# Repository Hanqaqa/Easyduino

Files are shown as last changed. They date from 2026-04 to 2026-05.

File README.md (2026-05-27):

# Easyduino: Repository of Open Source PCB Devboards for KiCad

The Easyduino project is an effort to easily dive into different PCB designs of the most popular microcontroller devboards like **Arduino, ESP32, Raspberry Pico and STM32 Bluepill** (more to come!). Using the free and Open Source Software [KiCad](https://www.kicad.org/) and adhering the best practices across the PCB and KiCad ecosystem. Also adding the much needed USB-C support!

<p align="center">
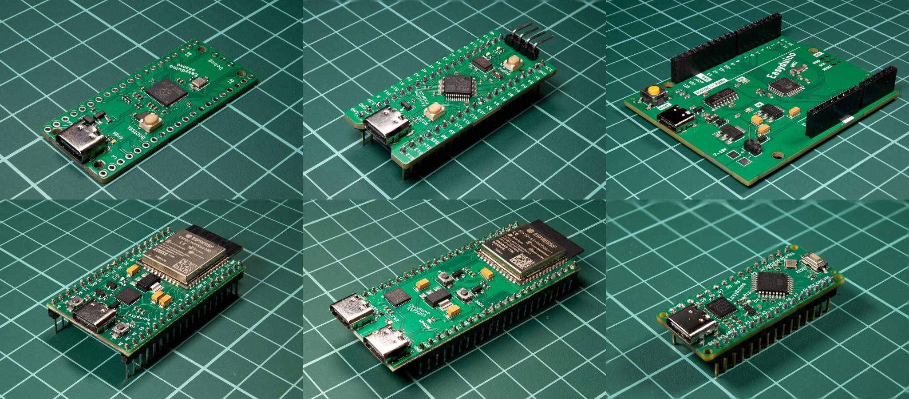
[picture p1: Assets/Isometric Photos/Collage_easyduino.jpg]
    
</p>

The project was born out of the necessity to unify the wide variety of software, languages and conventions used in the most popular devboards. For example Arduino Uno was developed in 2010, Italy, using Eagle. The ESP32 devboard was developed in 2016, China, using Altium. The Raspberry Pi Pico 2040 was developed around 2021 in the U.K. using KiCad and Altium...

## Available Development Boards 

[Easyduino UNO](https://github.com/Hanqaqa/Easyduino/tree/master/Atmega328p%20Arduino%20Uno) | [Easyduino Nano](https://github.com/Hanqaqa/Easyduino/tree/master/Atmega328p%20Arduino%20Nano) | [Easyduino ESP32](https://github.com/Hanqaqa/Easyduino/tree/master/ESP32) |
---|---|---|
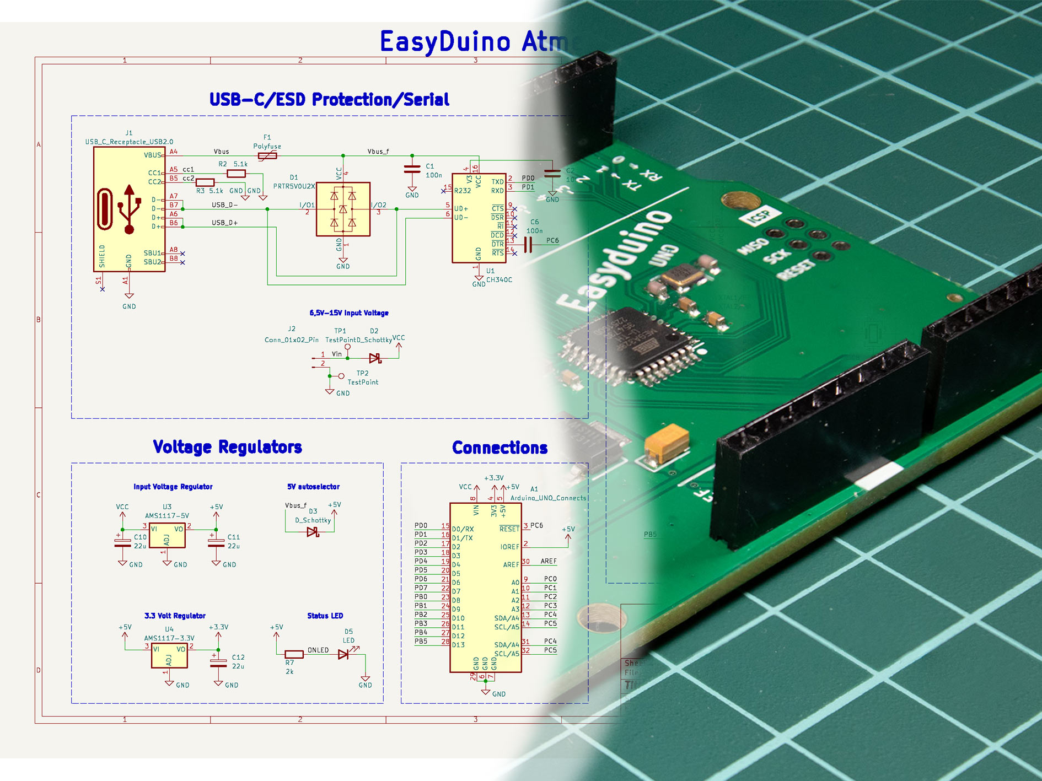
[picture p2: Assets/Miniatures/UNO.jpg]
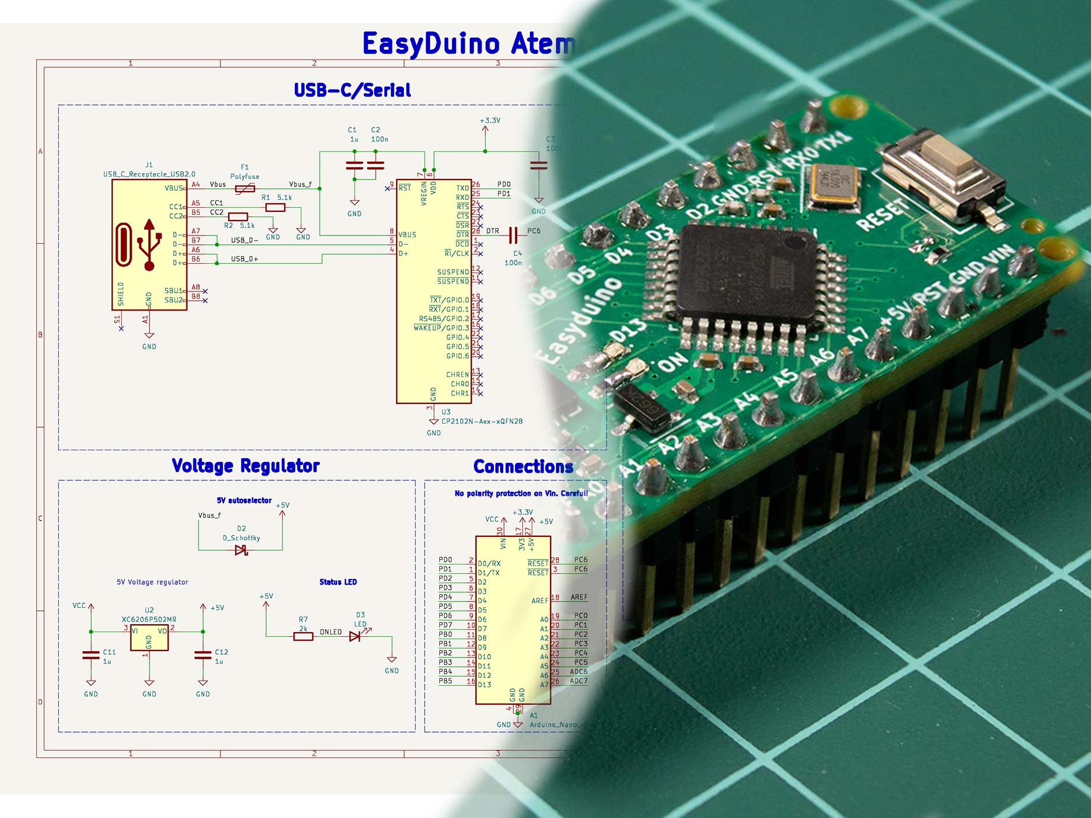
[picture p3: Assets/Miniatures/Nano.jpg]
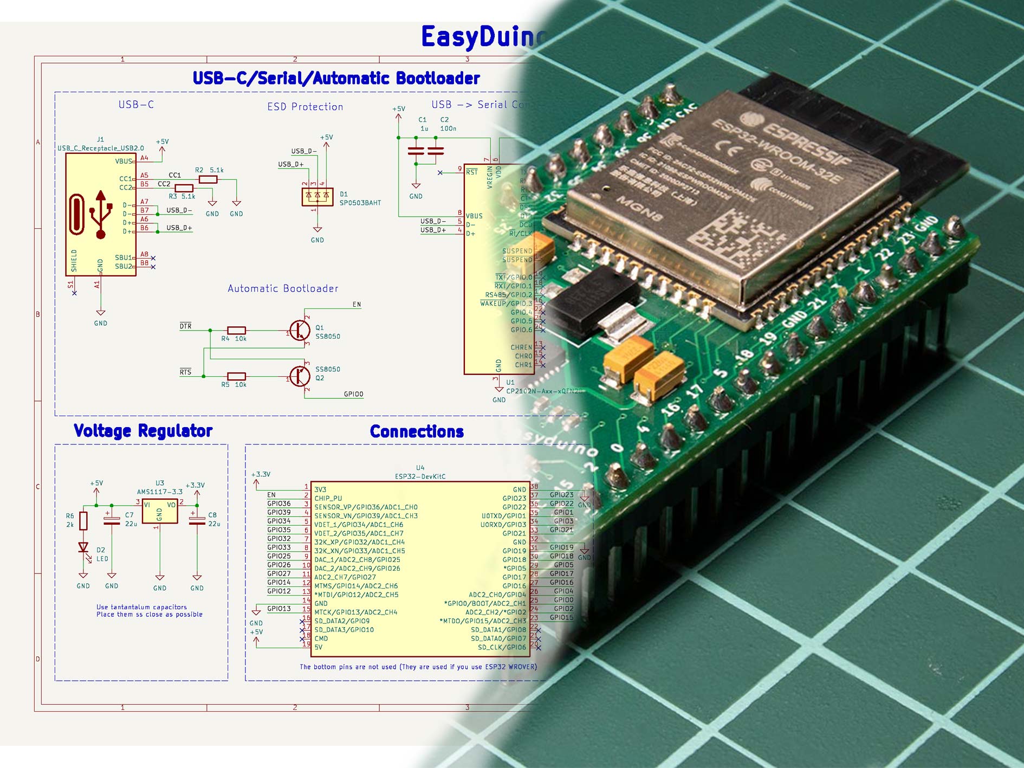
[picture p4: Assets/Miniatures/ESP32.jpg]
[](https://github.com/Hanqaqa/Easyduino/tree/master/Atmega328p%20Arduino%20Uno) | [](https://github.com/Hanqaqa/Easyduino/tree/master/Atmega328p%20Arduino%20Nano) | [](https://github.com/Hanqaqa/Easyduino/tree/master/ESP32) | 

[Easyduino ESP32 S3](https://github.com/Hanqaqa/Easyduino/tree/master/ESP32S3) | [Easyduino Pi Pico](https://github.com/Hanqaqa/Easyduino/tree/master/Raspberry%20Pi%20Pico%202040) | [Easyduino Bluepill STM32F103](https://github.com/Hanqaqa/Easyduino/tree/master/STM32F103%20Bluepill)
---|---|---|
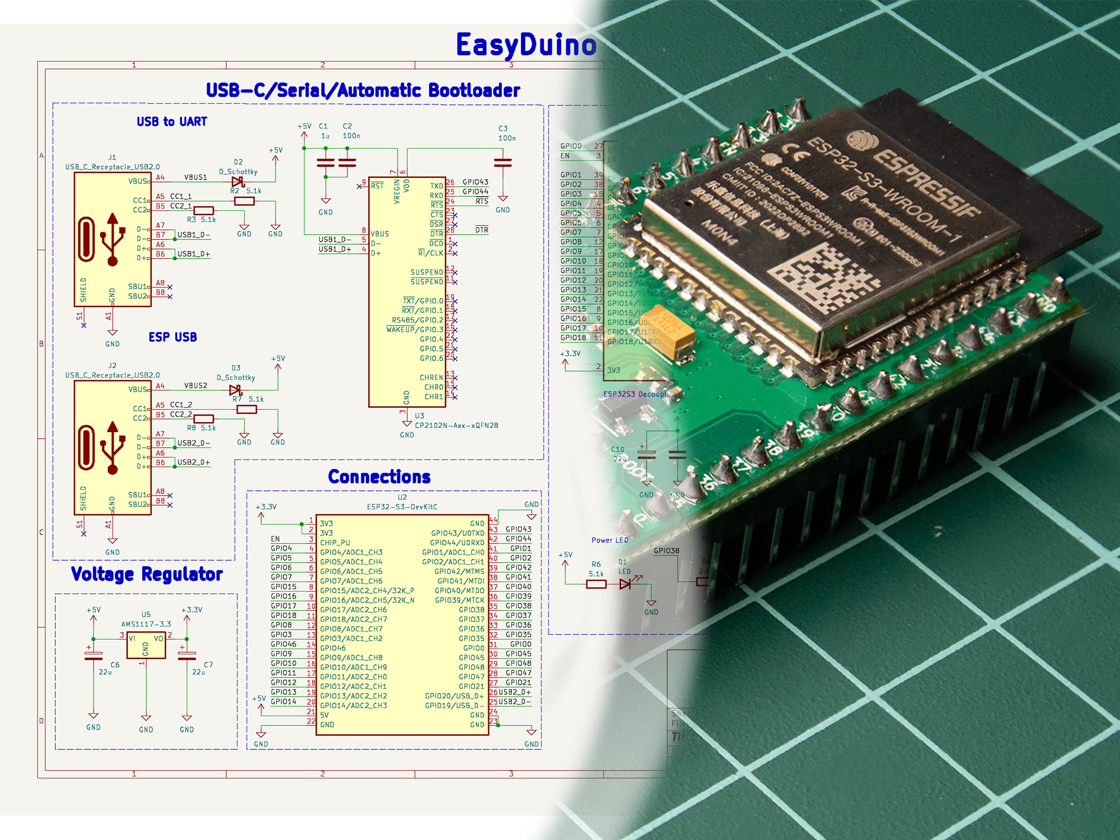
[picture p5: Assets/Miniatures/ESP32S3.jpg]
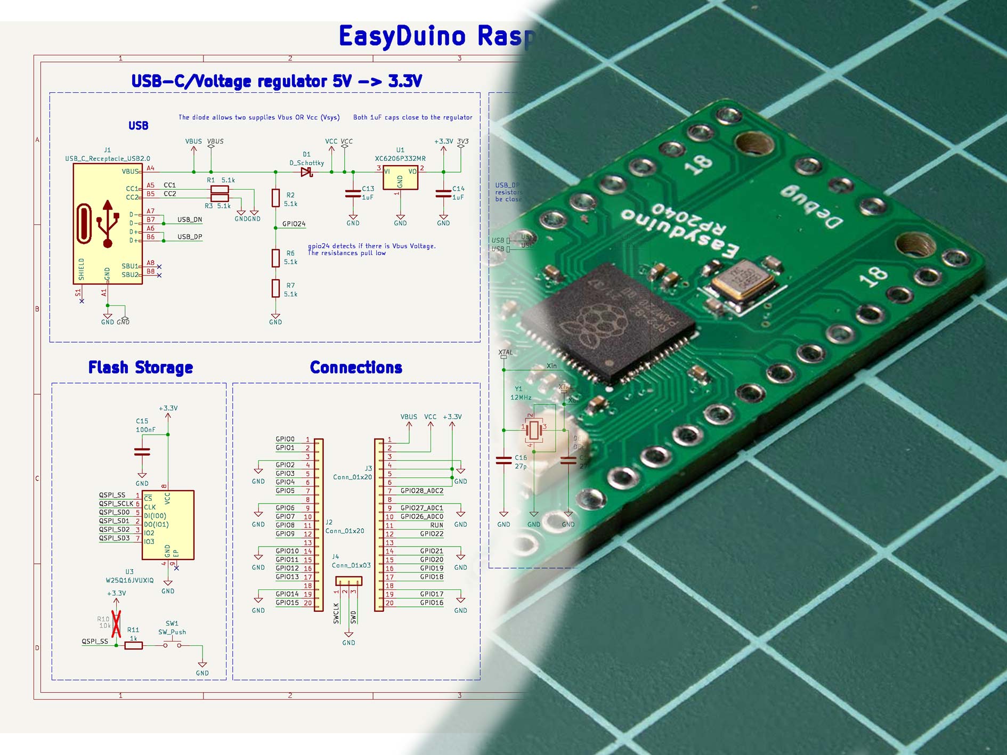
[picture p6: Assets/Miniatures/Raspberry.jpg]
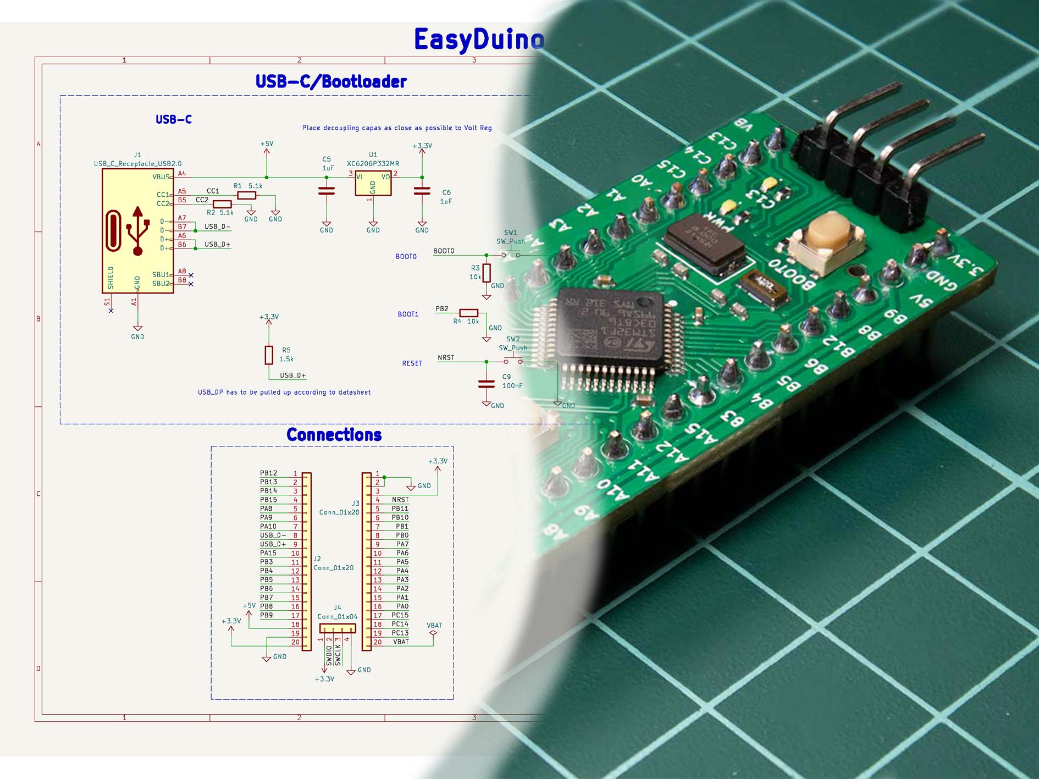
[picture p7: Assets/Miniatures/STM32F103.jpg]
[](https://github.com/Hanqaqa/Easyduino/tree/master/ESP32S3) | [](https://github.com/Hanqaqa/Easyduino/tree/master/Raspberry%20Pi%20Pico%202040) | [](https://github.com/Hanqaqa/Easyduino/tree/master/STM32F103%20Bluepill)

[Easyduino Pi Pico 2](https://github.com/Hanqaqa/Easyduino/tree/master/PiPico2) | [Easyduino Pi Pico 2 2354B](https://github.com/Hanqaqa/Easyduino/tree/master/PiPico22354B) | [Easyduino nrf52840 dongle](https://github.com/Hanqaqa/Easyduino/tree/master/nrf52840dongle)
---|---|---|
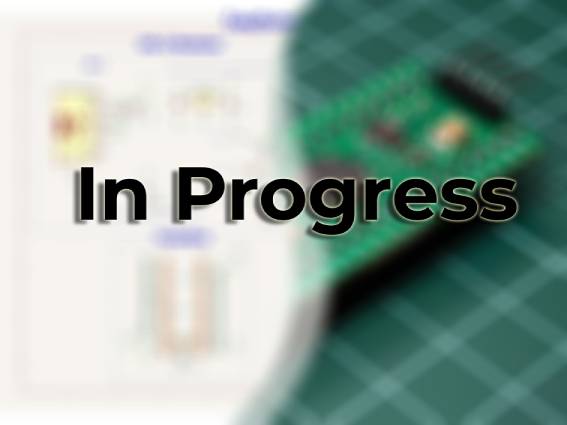
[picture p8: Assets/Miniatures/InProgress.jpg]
[](https://github.com/Hanqaqa/Easyduino/tree/master/PiPico2) | [](https://github.com/Hanqaqa/Easyduino/tree/master/PiPico22354B) | [](https://github.com/Hanqaqa/Easyduino/tree/master/nrf52840dongle)

The outline, pinout, layout and components have been tried to be replicated with respect to the originals, in all of the boards. With various levels of success. 

Some boards, like the Raspberry Pi Pico use 01005 components which are too expensive for the manufacturer to integrate in the PCB Aseembly line. Some other components like the original Arduino UNO USB to Serial converter, an Atmega16u2, were hard to come by during the development of this project ~January 2023, so more readily available options were chosen. All the differences with the original boards are explained inside the folder of each project in a readme file. 

4 layers of copper have been used in all projects to simplify the wiring. Specifically the [JLC04161H-7628](https://jlcpcb.com/impedance) stackup. 

The PCB constraints of the manufacturer JLCPCB are explained [here](https://github.com/Hanqaqa/Easyduino/tree/master/Assets/JLCPCB%20Constraints)

## Structure of each project

Each project consists of: 
- Main KiCad files (.kicad_pro, .kicad_sch...)
- A readme explaining the specifics of that project
- xxx.pretty or xxxlibraries folder which contains the non standard footprints or schematic parts used in the project (Some projects such as the Arduino UNO only use standard libraries, therefore these folders don't exist)
- The **Outputs** folder: Contains all the data produced by the KiCad Jobset like Gerbers, STEPs, PDFs, ERC, BOM, CPLs... Most of these are then copied, organized, and placed into their respective `ProductionFiles` folders.
- The ***ProductionFiles*** folder which includes files such as:
    - BOM: This folder contains both the list of components and the Centroid File in JLCPCB readable format. The CPL .csv file needs a small tweak at the beginning of the file in order to be readable. I mention it [here](https://github.com/Hanqaqa/Easyduino/tree/master/Assets/JLCPCB%20Constraints#cpl-component-placement-list).
    - ***Datasheets***: all the datasheets of the main components used in the project. Datasheets of easily replaceable components such as Resistors, Capacitors and LEDs are not given
    - Gerbers: A zip file with all of the manufacturing gerber files such as Copper/Mask/Silkscreen layers
    - PDFs: PDF and PNG files of the Schematic and PCB
    - Photos: Some photos of the manufactured PCB as well as some renders

## Using the project

1. Install the latest version of [KiCad](https://www.kicad.org/)
2. If you already have KiCad installed, click the upper right button in this github page `<>Code`, click `Download ZIP`, extract the files in your desired folder. If you know how to use git, clone the repository
3. Double click on the xxx.kicad_pro file inside any project and KiCad will start

This project was developed using KiCad v8.0.0, but has been updated and tested with KiCad v10. Including the creation of Jobsets which massively simplfies creating gerbers and BOMs. 

Since this is a collection of projects, the new KiCad v10 Git utilities don't work properly with each project, forcing you to git add the whole project if you want to make a change.

If you'd rather just consult the schematics or the gerbers. They are located inside the **ProductionFiles** folder of each project. Inside the **PDFs** and **Gerber** folders.

## Contributing

If you spot any mistakes inside any of the projects. Either open an issue and I will try to correct it or fork and merge the correction. 

If you plan on developing any other development boards and wish to merge into the project. Please try to use the same style and conventions as the original ones in the schematic. Positive voltages facing up, text being clearly readable, a references page, similar folder structure.

To do list:

- [ ] ~~Order and test the v1.1 RP2040 board. (In v1.0 I mixed some pins in the Flash and couldn't boot up). Ordered. Awaiting arrival. v1.1 is working correctly. Need to update photos and repo.~~ Order v1.2 with Silkscreen text for BOOTSEL and RESET. Once received test and make photos.
- [ ] ~~Order and test the v1.1 ESP32S3 board. (In v1.0 I forgot to add PullUp and PullDown in RST and SUSPEND CP2102). Ordered. Awaiting arrival.~~ TX and RX signals going into CP2102 were mixed. Fix it and order v1.2. Once received test and make photos.
- [ ] Developing: nRF52840 Dongle, RP2350A (Pi Pico 2), and Pi Pico 2 2354B with extra functionalities
- [ ] Investigate other possible microcontrollers/SOCs/FPGAs to implement.

## Acknowledgments

Thanks to [winsrrow](https://github.com/winsrrow) for providing lots of KiCad tips and designing from the ground up the v1.1 RP2040 board.

## Licensing

This project is distributed under the [**CERN Open Hardware Licence Version 2 - Permissive**](https://github.com/Hanqaqa/Easyduino/blob/master/License.txt) which means **you are free to use any or all parts of this project with or without disclosing the source**, even for comercial projects. As long as you include a copy of the CERN OHLv2 Permissive Licence.

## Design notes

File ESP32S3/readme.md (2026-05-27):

# ESP32S3 v1.2 IN PROGRESS

The new and powerful microcontroller from Espressif

<p align="center">
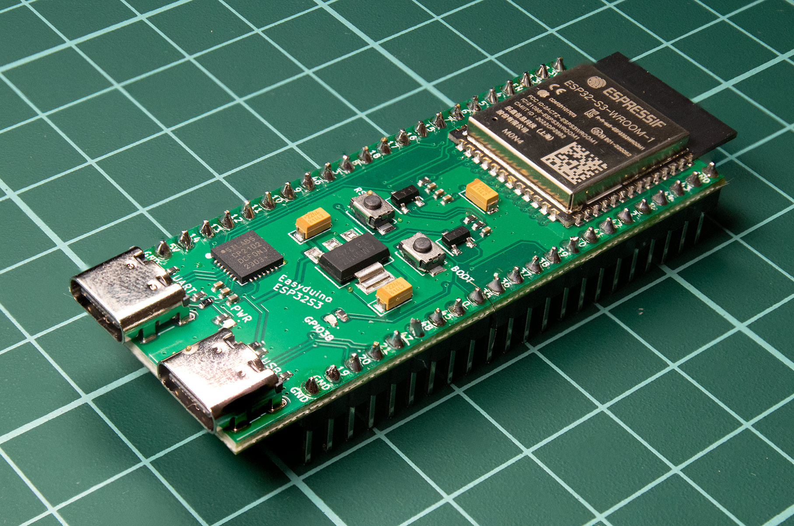
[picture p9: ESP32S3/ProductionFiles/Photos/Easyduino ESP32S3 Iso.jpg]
    
</p>

**The pictured version is v1.0 which had TX/RX from the CP2102 going into the ESP32S3 module mixed up. The project contains the v1.2 which corrects that mistake. Will update the pictures once I order antoher batch and test everything works correctly.**

## Schematic

<p align="center">
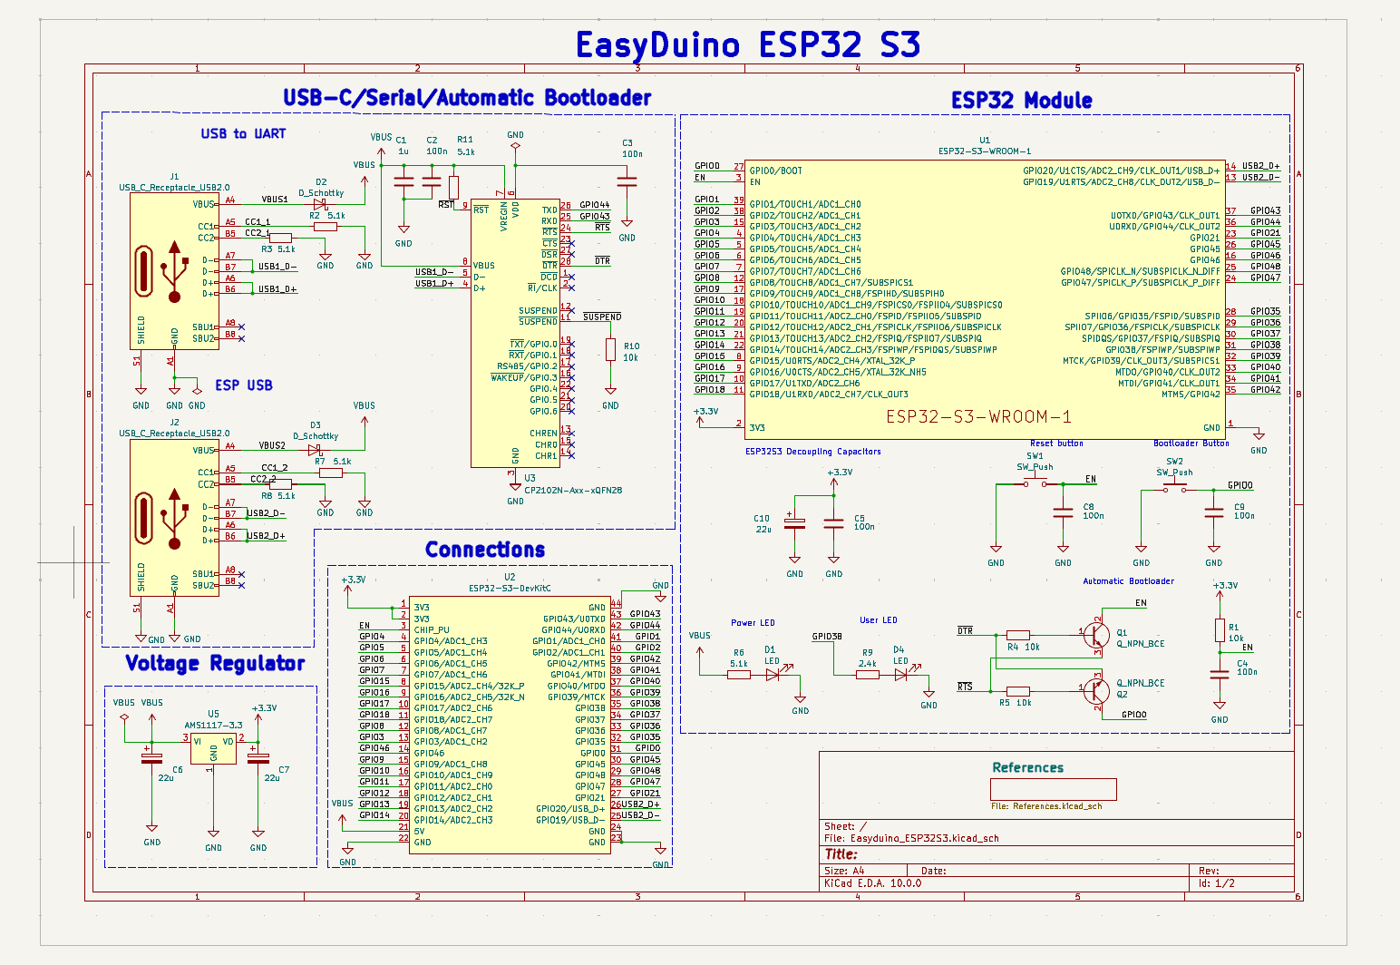
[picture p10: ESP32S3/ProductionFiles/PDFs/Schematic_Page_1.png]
    
</p>

KiCad Schematic symbols, footprints and 3D Models were obtained from their [KiCad Github repository](https://github.com/espressif/kicad-libraries)

## Gerbers

<p align="center">
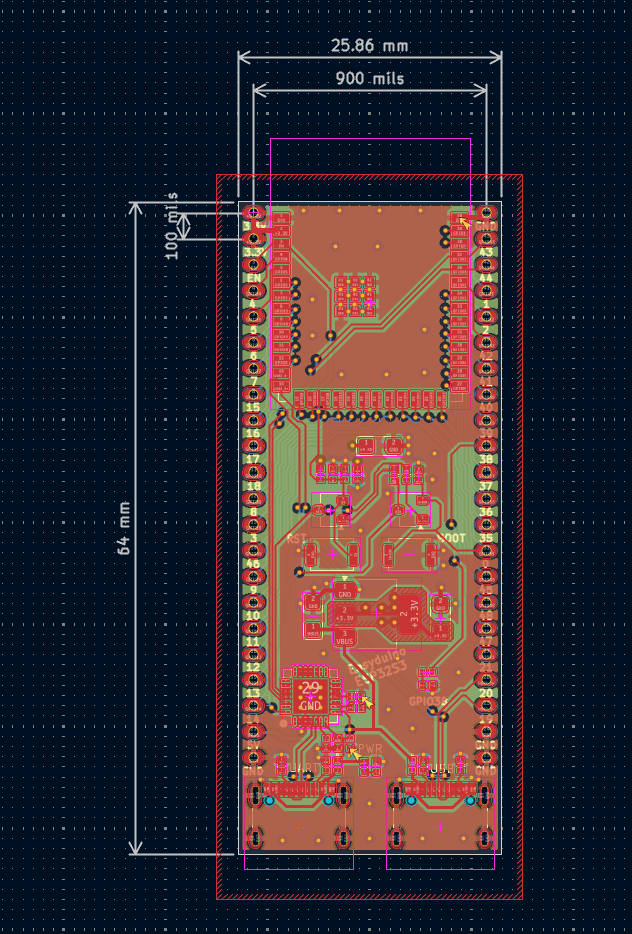
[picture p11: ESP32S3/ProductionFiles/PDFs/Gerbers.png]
    
</p>

## Specs

- Input Voltage: 5V-15V(External Source 5V) 5V (USB UART OR USB ESP32) or 3.3V. ONLY USE ONE VOLTAGE INPUT AT A TIME
- Output Current at 3.3V : 1 A (External Source) 500mA (USB)
- No Polarity Protection (External Source)
- Overcurrent Protection: None 

## References 

### ESP32 S3 WROOM 1

#### Decoupling Capacitors:

- ESP32 S3 WROOM 1 datasheet p25 -> 3.3V pin needs a 22uF and a 100nF capacitors. The 22uF doesn't have to be a tantalum capacitor. But I will use a tantalum to reuse components

#### Automatic Bootloader

- ESPS3 Sch -> Automatic Bootloader.
- ESPS3 Sch / ESP32 S3 WROOM 1 datasheet p25 -> EN pin 10k resistor and 100nF capacitor

#### Thermal vias

- ESP32 S3 WROOM 1 datasheet p27 -> GND Thermal needs vias between pads

### USB-C

#### Filtering 

- USB Hardware Design Guidelines for FTDI ICs p8 -> 10nF Cap + Ferrite Bead + 100nF Cap + 4.7uF Cap
- I disregarded such heavy filtering for the easier to implement 1uF and 100nF cap given in the CP2102 datasheet
- I added a polyfuse with Ihold=500mA and Itrip=1A.

#### Differential Pair

- USB needs 90 Ohm differential traces. 
- Using JLCPCB's JLC04161H-7628 stackup.
- Which with Signal Layer (Layer 1) and a GND layer (L2) below. And with 0.2mm tracks and separated 0.15mm gives a differential pair impedance of approximately 90 Ohms.
- For USB1 will use a very short trace for D+ D- (around 2mm)
- For USB2 (tracks that go to the internal ESP32 S3 pins and the pinout) the traces are long ~60mm for D+ D-, and have vias
- The Development board from ESP32S3 has no problem with these differential pairs with vias and is a 2 board layer
- I also have to place vias because of the pinout of USB C and CP2102. Some other people have placed vias without problems for signal integrity

#### CP2102

- CP2102 datasheet p15 -> VBUS will be tied to REGIN. 1uF and 100 nF will be added.
- CP2102 datasheet p15 -> ESD Supression Diode for all three inputs of USB  
- CP2102 datasheet p15 and p19 -> 100nF for VDD output, 4.7 uF is optional for higher current circuits.
- CP2102 datasheet p23 -> The VDD or 3.3 output can only provide 100mA. I will not use this as a voltage provider for the ciruit. I will use the AMS1117-3.3 
- CP2102 datasheet p15 -> RST pulled up via 4.7k and SUSPEND~ pulled down via 10k.

#### AMS1117-3.3V

- AMS1117 Datasheet p1 -> 3.3V/1A Output with 5-15V Input
- AMS1117 Datasheet p4 -> 22uF tantalum capacitor on input and output.

## KiCad Render

<p align="center">
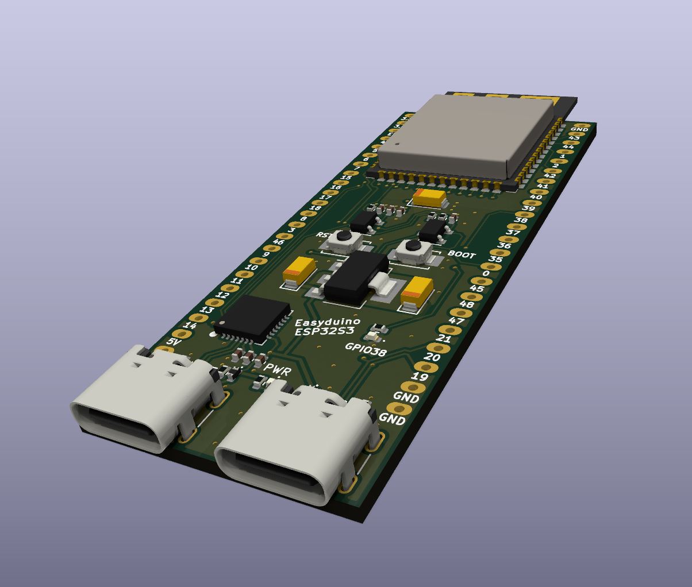
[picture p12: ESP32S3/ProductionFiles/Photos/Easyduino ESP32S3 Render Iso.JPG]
    
</p>

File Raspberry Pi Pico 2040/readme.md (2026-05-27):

# Raspberry Pi Pico RP2040 v1.2 IN PROGRESS.

The new and easy to use Microcontroller from the Raspberry Pi Foundation. Now with a Reset button. Connect via USB, hold BOOTSEL (BT), press and release RESET(RST), then release BOOTSEL. You are now in Bootloader mode.

<p align="center">
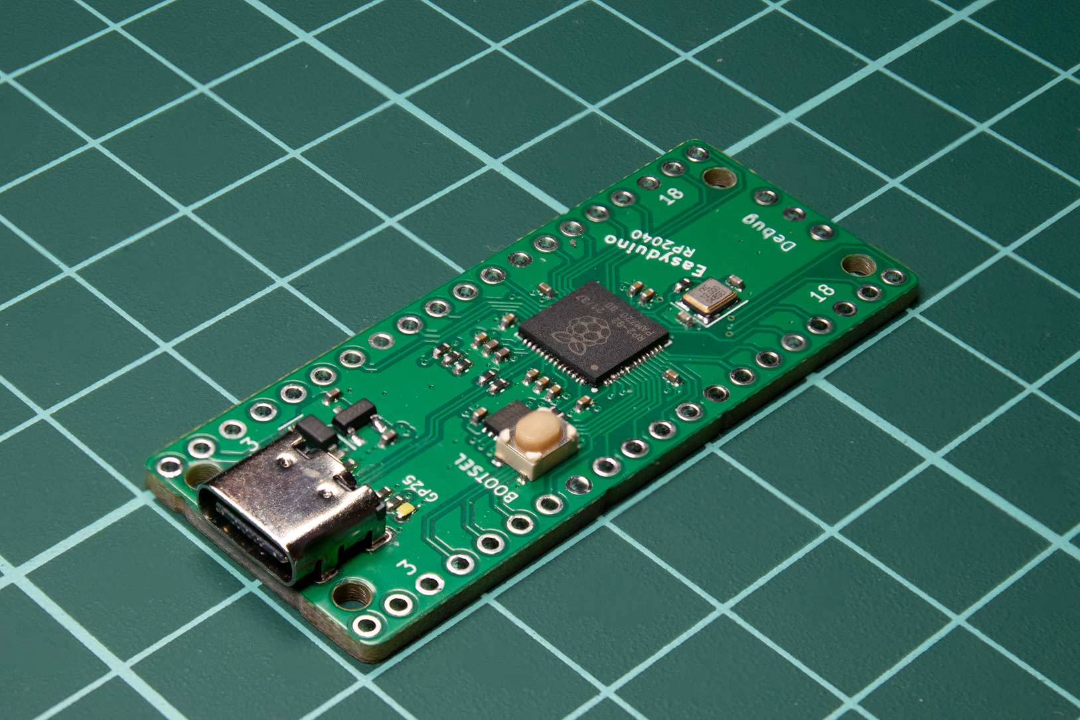
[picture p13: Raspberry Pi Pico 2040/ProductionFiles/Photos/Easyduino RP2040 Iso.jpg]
    
</p>

**The pictured version is v1.0 which had some pins mixed up in the flash memory and couldn't boot up. The project contains the v1.2 which corrects that mistake, adds a debug port and some test points. The photo will be updated when I receive and test the new board.**
**The mounting holes are not exactly in the same position as the original Pi Pico due to the size of USBC**

## Schematic

<p align="center">
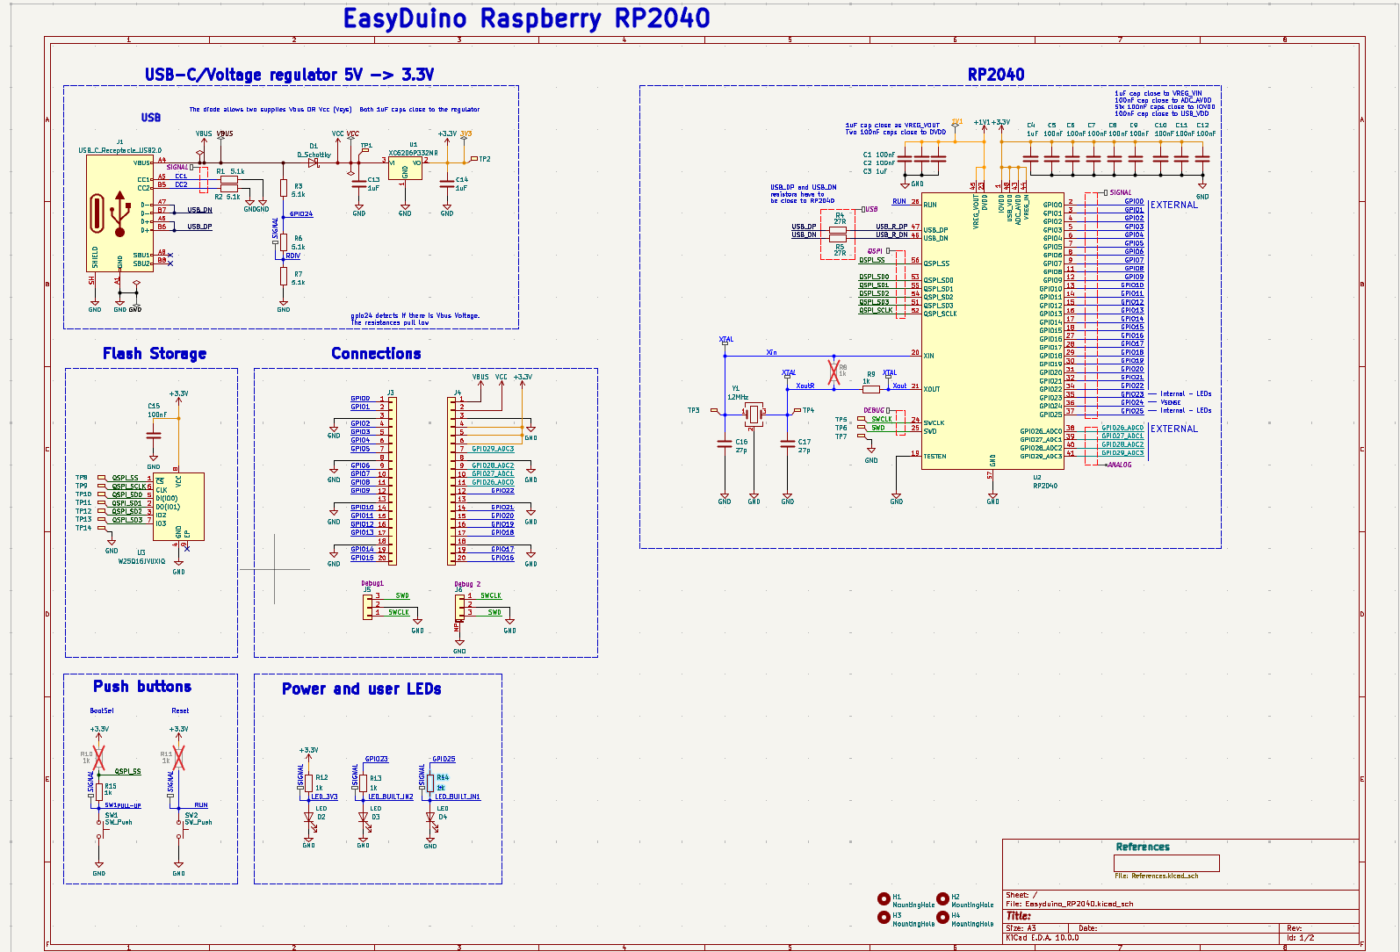
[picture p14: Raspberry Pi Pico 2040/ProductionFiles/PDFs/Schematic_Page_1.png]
    
</p>

KiCad's "Net classes" have been used in this schematic (The squares and romboids in the schematic). Net classes are useful for organising different nets on the circuit. For example, you can change all tracks widths for that net in just one menu.

## Gerbers

<p align="center">
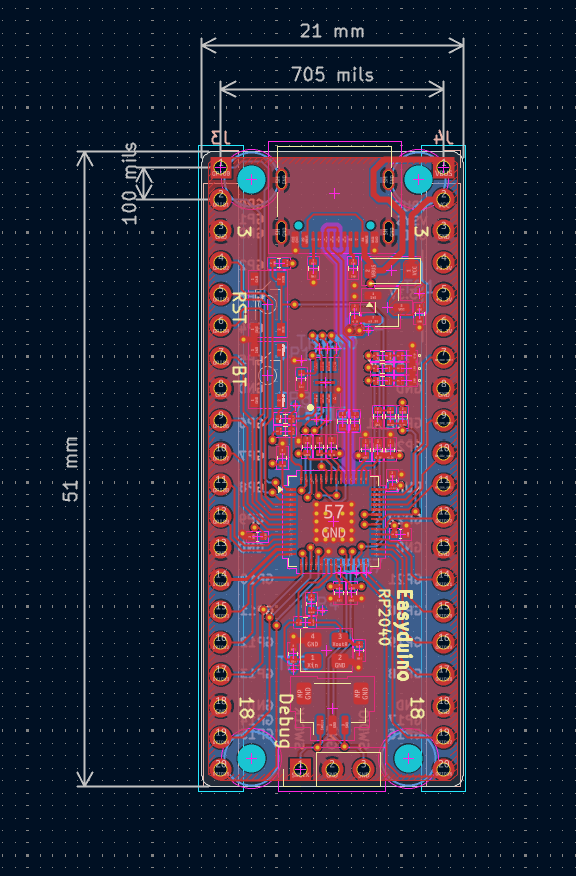
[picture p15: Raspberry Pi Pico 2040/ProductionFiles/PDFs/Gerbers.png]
    
</p>

## Specs

- Input Voltage: 5.5V-9V(External Source 5V) or 5V (USB). ONLY USE ONE VOLTAGE INPUT AT A TIME
- Maximum Output Current at 5V input : 200 mA at 3.3V output
- No Polarity Protection (External Source)
- Overcurrent Protection: None! 

## References 

### RP2040

- RPI Pico Schematic
- Hardware design with rp2040 p10 -> 12MHz crystal with 27 pF Capacitors 
- rp2040 datasheet p13 -> USB_DP and USB_DM need 27 Ohm Resistors
- rp2040 datasheet p13 -> Use a 12MHz Crystal
- rp2040 datasheet p13 -> TESTEN to GND
- rp2040 datasheet p155 -> USB_VDD connected to 3.3V and decoupled with a 100 nF capacitor
- rp2040 datasheet p155 -> IOVDD connected to 3.3V and decoupled with a 100 nF capacitor per pin (6pins)
- rp2040 datasheet p155 -> DVDD connected to VREG_VOUT = 1.1V and decoupled with a 100 nF capacitor per pin (2pins)
- rp2040 datasheet p156 -> ADC_AVDD connected to 3.3V and decoupled with a 100 nF capacitor. A better circuit (Pico Schematic) can be made when ADC is crucial
- rp2040 datasheet p160 -> VREG_VIN Internal 1.1V Voltage regulator Input. Connect to external 3.3V and decouple with 1uF
- rp2040 datasheet p160 -> VREG_VOUT Internal 1.1V Voltage regulator Output. Connect to 1.1V and decouple with 1uF

### USB-C

#### Differential Pair

- USB needs 90 Ohm differential traces. 
- According to JLCPCB impedance calculator, with a JLC7628 prepreg and 6mil (0.15mm) space between lines
- I have to use 9 mil tracks -> 0.2 mm
- I have to place vias because of the pinout of USB C and CP2102. Some other people have done it with no problems

### W25Q16JVUXIQ

- W25Q16JVUXIQ Datasheet p6 -> Use a 100nF and 1uF capacitor
- RPI Pico Schematic -> Use a 100nF and 2uF decoupling capacitors. A pull up resistor is not fitted
- Hardware design with rp2040 p9 -> Use a 100nF decoupling capacitor. Pull up resistor is not fitted, the flash can work without it. 
- I will only place the 100nF capacitor, since the devboard can work according to Hardware design guide. I will not place a pull up resitor

### XC6206P332MR-3.3V

- XC6206_Torex Datasheet p6 -> Two 1 uF ceramic capacitors on Vin and Vout

### Differences with Original Raspberry Pi Pico

- GPIO23 is not exposed or used. Since the voltage regulator used (XC6206...) doesn't have a Power Select mode
- GPIO29_ADC which is used for monitoring VSys (external battery) is not exposed or used in order to save costs
- In the Raspberry Pi Pico Schematic, 2uF capacitors are used for decoupling. I use 1uF decoupling capacitors as indicated in the rp2040 datasheet
- ADC_AVDD is powered only by 3.3V, no option for external Analog powering. This will be more noisy for projects where ADC is used. But in order to save space and cost. I will skip the option to power ADC_AVDD externally

## KiCad Render

<p align="center">
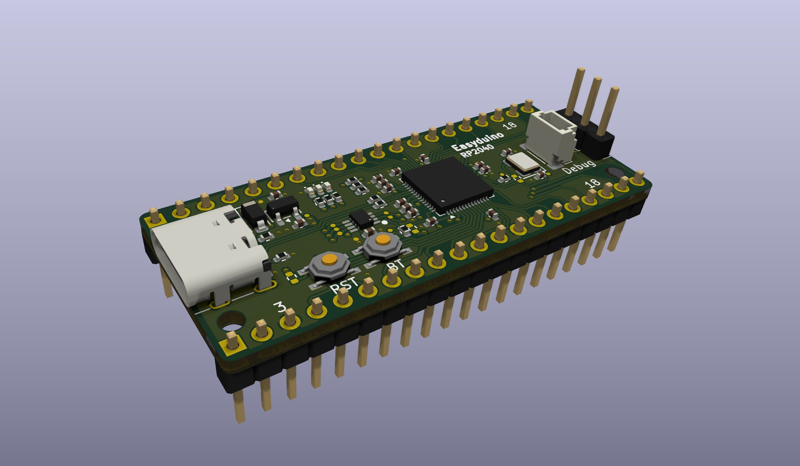
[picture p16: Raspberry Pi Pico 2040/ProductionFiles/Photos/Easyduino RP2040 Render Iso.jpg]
    
</p>

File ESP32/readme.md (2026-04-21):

# ESP32

The most popular WiFi Microcontroller

<p align="center">
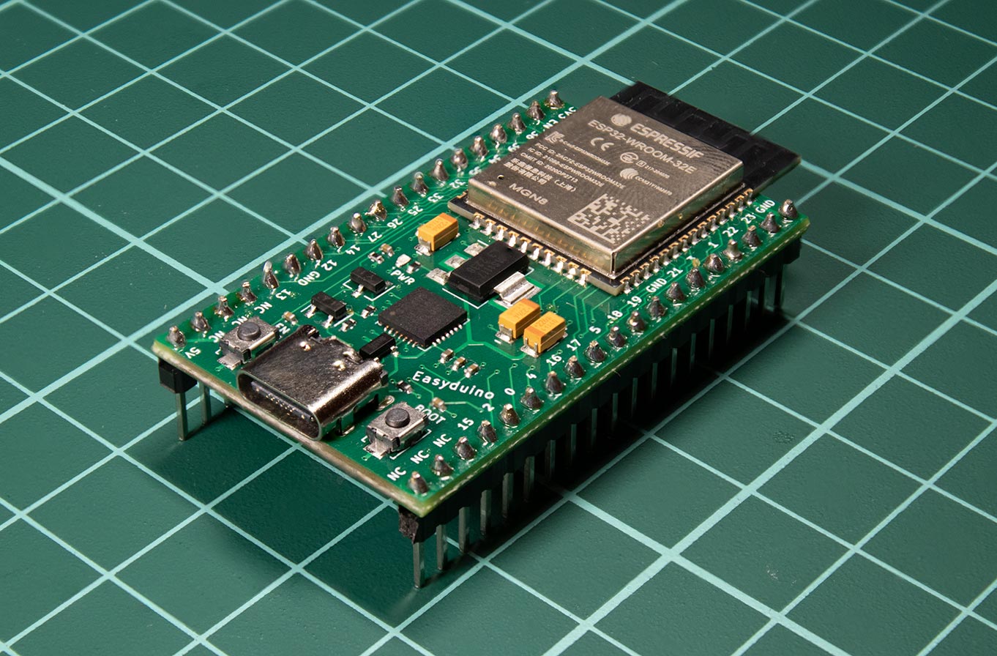
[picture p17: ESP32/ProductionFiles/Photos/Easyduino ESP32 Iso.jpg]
    
</p>

## Schematic

<p align="center">
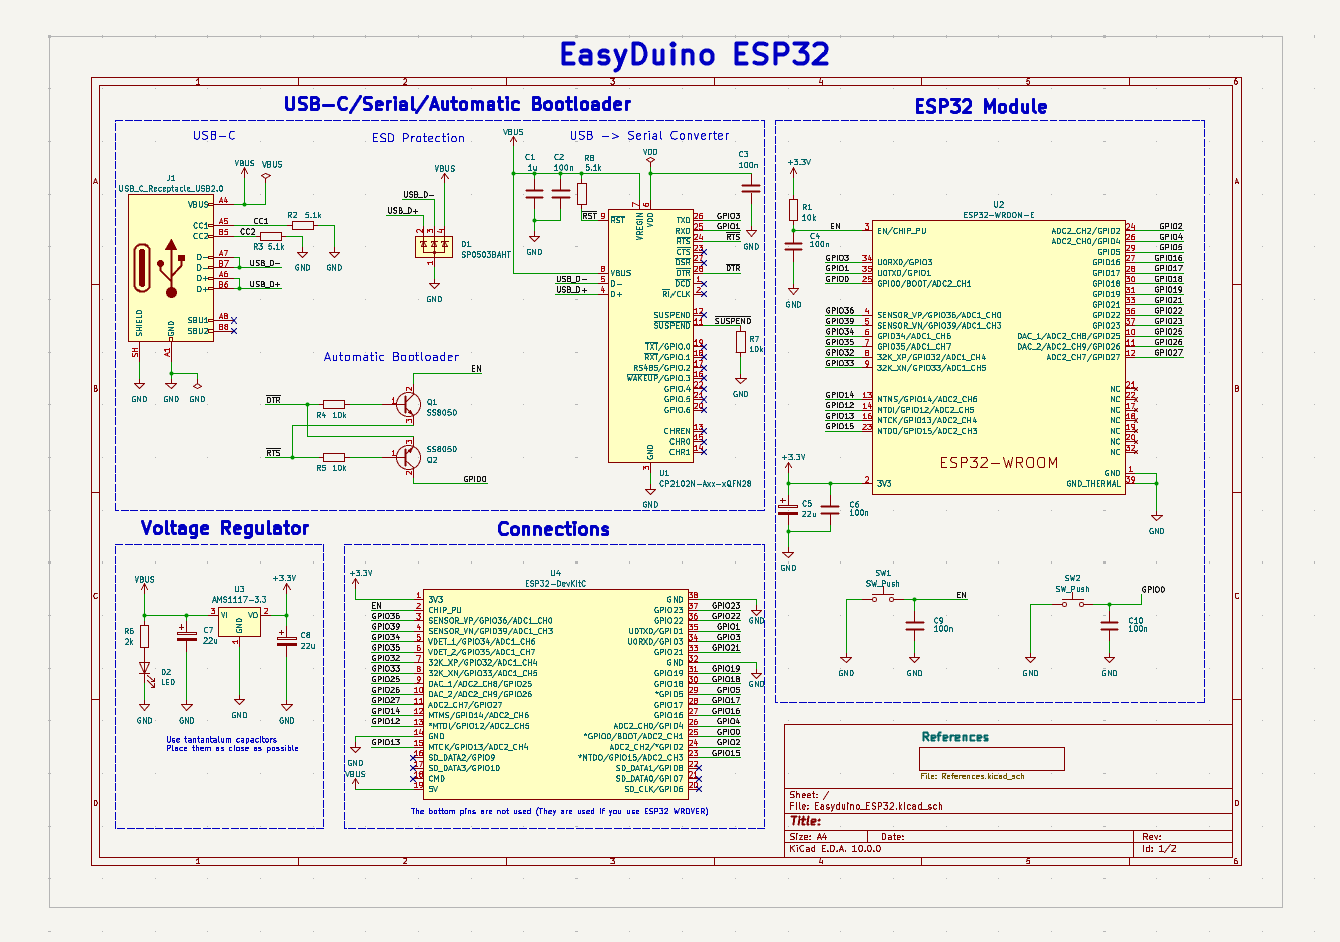
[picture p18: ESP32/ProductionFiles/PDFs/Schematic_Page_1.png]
    
</p>

KiCad Schematic symbols, footprints and 3D Models were obtained from their [KiCad Github repository](https://github.com/espressif/kicad-libraries)

## Gerbers

<p align="center">
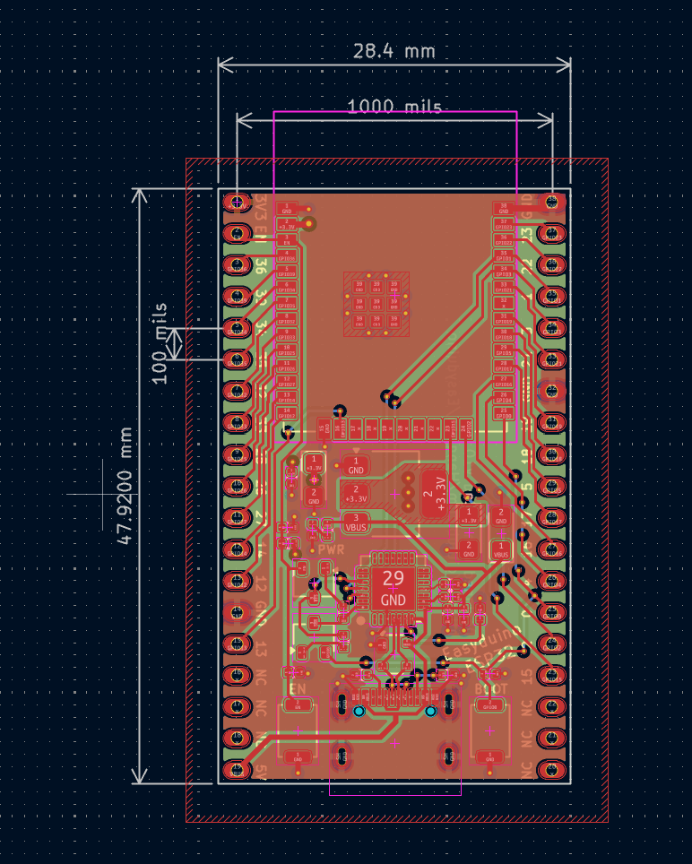
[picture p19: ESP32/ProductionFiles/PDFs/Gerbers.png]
    
</p>

## Specs

- Input Voltage: 5V-15V(External Source 5V Pin) 5V (USB) or 3.3V (3.3V Pin). ONLY USE ONE VOLTAGE INPUT AT A TIME
- Output Current at 3.3V : 1 A (External Source) 500mA (USB)
- No Polarity Protection (External Source)
- Overcurrent Protection: None 

## References 

### ESP32 WROOM 32E

#### Decoupling capacitors 

- ESP32 Wroom 32 E datasheet p24 -> 3.3V pin needs one 22uF and one 100nF capacitors

#### Enable pin (EN)

- ESP32 Devkit sch -> EN pin 10k resistor and 100nF capacitor

#### Thermal Pad

- ESP32 Wroom 32 E datasheet p26 -> GND Thermal needs vias between pads. Needed vias are too small for my manufacturer. I will use bigger vias

#### Automatic Bootloader

- ESP32 Devkit sch -> Automatic Bootloader.

### USB-C

#### Filtering 

- USB Hardware Design Guidelines for FTDI ICs p8 -> 10nF Cap + Ferrite Bead + 100nF Cap + 4.7uF Cap
- I disregarded such heavy filtering for the easier to implement 1uF and 100nF cap given in the CP2102 datasheet
- I added a polyfuse with Ihold=500mA and Itrip=1A.

#### Differential Pair

- USB needs 90 Ohm differential traces. 
- According to JLCPCB impedance calculator, with a JLC7628 prepreg and 6mil (0.15mm) space between lines
- I have to use 9 mil tracks -> 0.2 mm
- I will use a very short trace for D+ D- (around 2mm)
- I have to place vias because of the pinout of USB C and CP2102. Some other people have done it with no problems

#### CP2102

- CP2102 datasheet p15 -> VBUS will be tied to REGIN. 1uF and 100 nF will be added.
- CP2102 datasheet p15 -> ESD Supression Diode for all three inputs of USB  
- CP2102 datasheet p15 and p19 -> 100nF for VDD output, 4.7 uF is optional for higher current circuits.
- CP2102 datasheet p23 -> The VDD or 3.3 output can only provide 100mA. I will not use this as a voltage provider for the ciruit. I will use the AMS1117-3.3 
- CP2102 datasheet p15 -> RST pulled up via 4.7k and SUSPEND~ pulled down via 10k.

#### AMS1117-3.3V

- AMS1117 Datasheet p1 -> 3.3V/1A Output with 5-15V Input
- AMS1117 Datasheet p4 -> 22uF tantalum capacitor on input and output.

## KiCad Render

<p align="center">
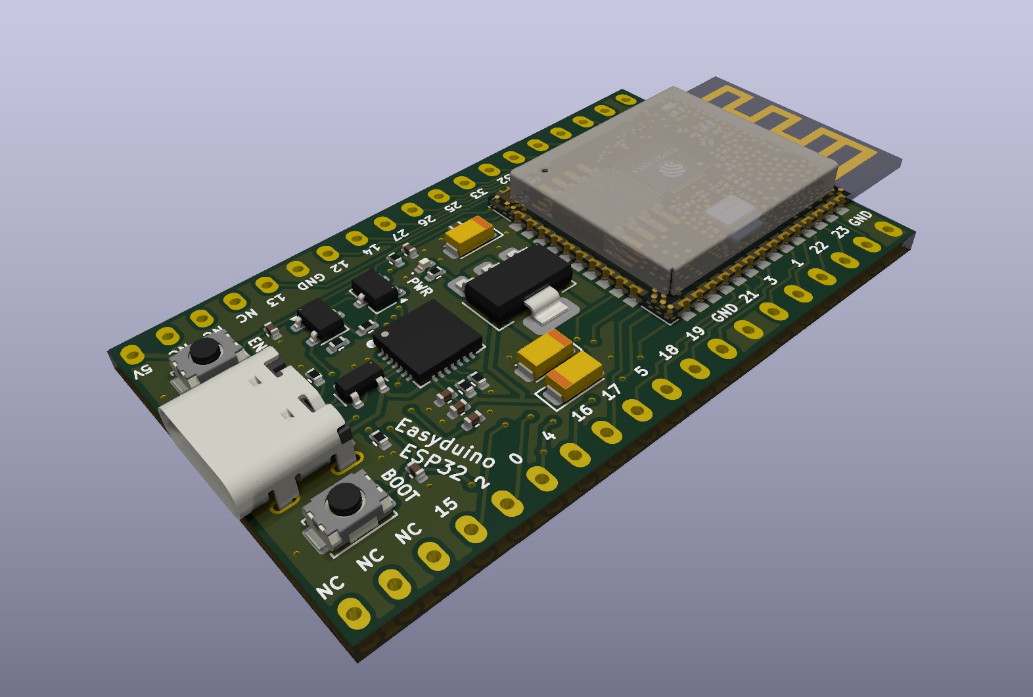
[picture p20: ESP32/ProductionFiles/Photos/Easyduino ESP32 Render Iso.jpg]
    
</p>

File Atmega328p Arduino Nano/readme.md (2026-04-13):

# Easyduino Arduino Nano

The popular Nano version of the Arduino

<p align="center">
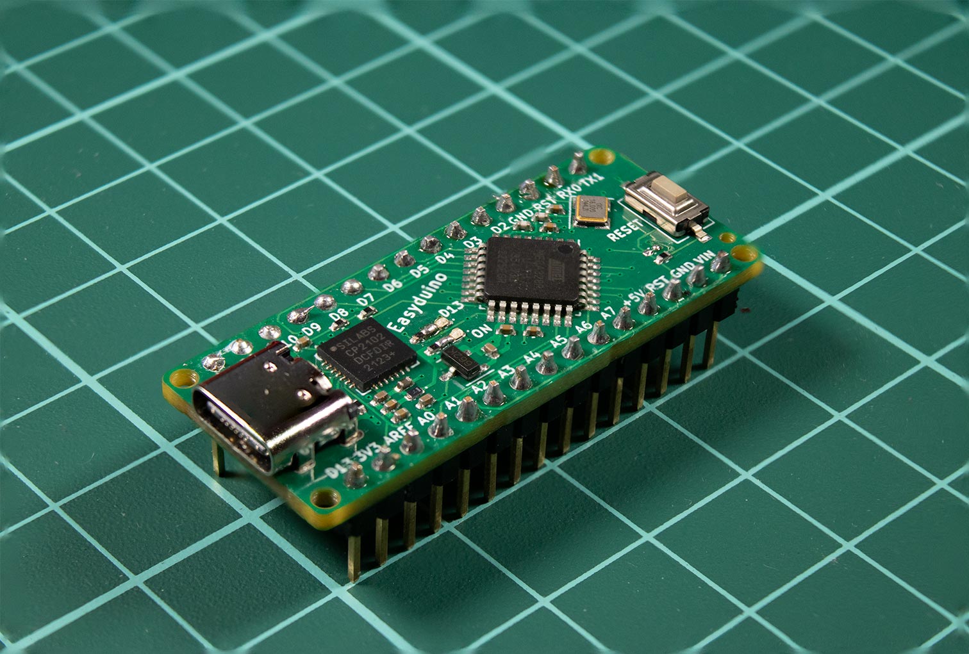
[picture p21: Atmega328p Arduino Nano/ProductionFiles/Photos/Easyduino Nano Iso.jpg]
    
</p>

## Schematic

<p align="center">
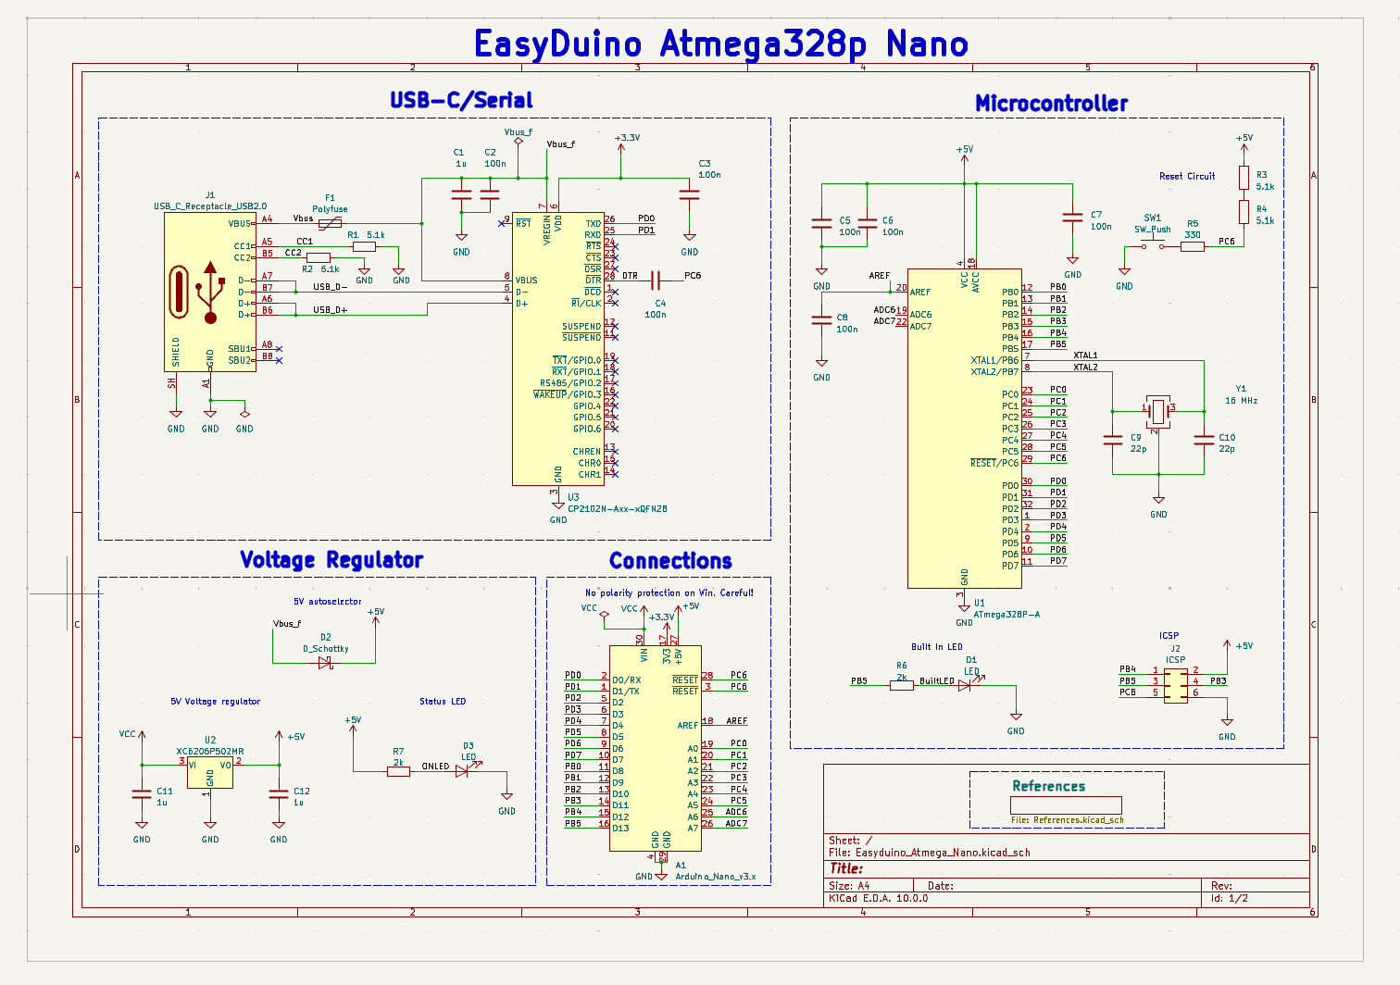
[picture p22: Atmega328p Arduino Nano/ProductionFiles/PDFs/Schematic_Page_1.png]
    
</p>

## Gerbers

<p align="center">
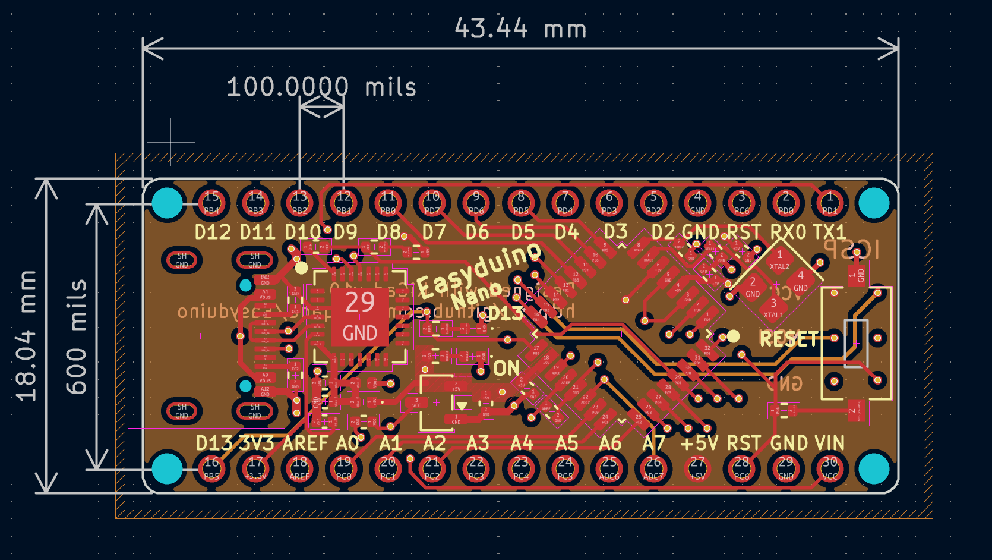
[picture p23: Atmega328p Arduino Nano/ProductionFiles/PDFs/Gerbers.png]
    
</p>

## Specs

- Input Voltage: 5.5V-9V(External Source Vin) 5V (USB). Both can be used at the same time. Preferable to only power from one source
- Output Current: 250 mA (External Source) 500mA (USB)
- 3.3V Output Current: None (External Source) 100 mA (USB)
- No Polarity Protection (External Source)
- Overcurrent Protection: None (External Source) 1A (USB)
- 5V Autoselector: can take both USB and external source. A diode will avoid short circuit. 
- External input Polarity Protection: None!! 

## References 

### Atmega 328p

#### Reset 

- Atmega Hardware Design Considerations p7,p8 -> 10kR and 330R for switch. The 100nF capacitor is not used for Arduino (Produces errors with DTR)
- The 100nF capacitor on DTR (CP2102) is used for tricking the Atmega into Bootloader mode

#### Crystal

- Atmega Hardware Design Considerations p16 -> 22pf

#### AVCC

- Atmega328 Reference Manual p213 -> 10uH ferrite bead and 100nF. 
- The Analog tracks aren't critical. I won't create an analog ground for these tracks.
- I also won't add the 10 uH ferrite

#### AREF

- Atmega Hardware Design Considerations p6 -> 100nF

### USB-C

#### Filtering 

- USB Hardware Design Guidelines for FTDI ICs p8 -> 10nF Cap + Ferrite Bead + 100nF Cap + 4.7uF Cap
- I disregarded such heavy filtering for the easier to implement 1uF and 100nF cap given in the CP2102 datasheet
- I added a polyfuse with Ihold=500mA and Itrip=1A.

#### Differential Pair

- USB needs 90 Ohm differential traces. 
- According to JLCPCB impedance calculator, with a JLC7628 prepreg and 6mil (0.15mm) space between lines

- I have to use 9 mil tracks -> 0.2 mm
- I will use a very short trace for D+ D- (around 2mm)
- I have to place vias because of the pinout of USB C and CP2102. Some other people have done it with no problems

#### CP2102

- CP2102 datasheet p15 -> 1uF and 100nF for REGIN and VBUS
- CP2102 datasheet p15 -> 100nF for VDD output, 4.7 uF is optional for higher current circuits.
- CP2102 datasheet p23 -> The VDD or 3.3 output can only provide 100mA 
- CP2102 datasheet p23 -> Logic levels go up to 3.3 V, but Atmega328p is able to understand them. Despite being 5V
- CP2102 datasheet p15 -> RST and SUSPEND resistors have not been placed. Might produce bad results due to noise

#### XC6206P

- XC6206 Torex Datasheet p1 -> 1uF ceramic capacitor on input and output. 7V Maximum operating Voltage
- XC6206 UWM Datasheet p2 -> 1uF ceramic capacitor on the input and output. 9V Maximum operating Voltage

#### 5V autoselector

- If USB is present and no external input voltage. The USB will power the ATMEGA
- If USB is present and there is external input voltage. The external voltage will power the ATMEGA
- If USB is not present and there is external input voltage. The external voltage will power the ATMEGA. The 3.3V output won't work

## KiCad Render

<p align="center">
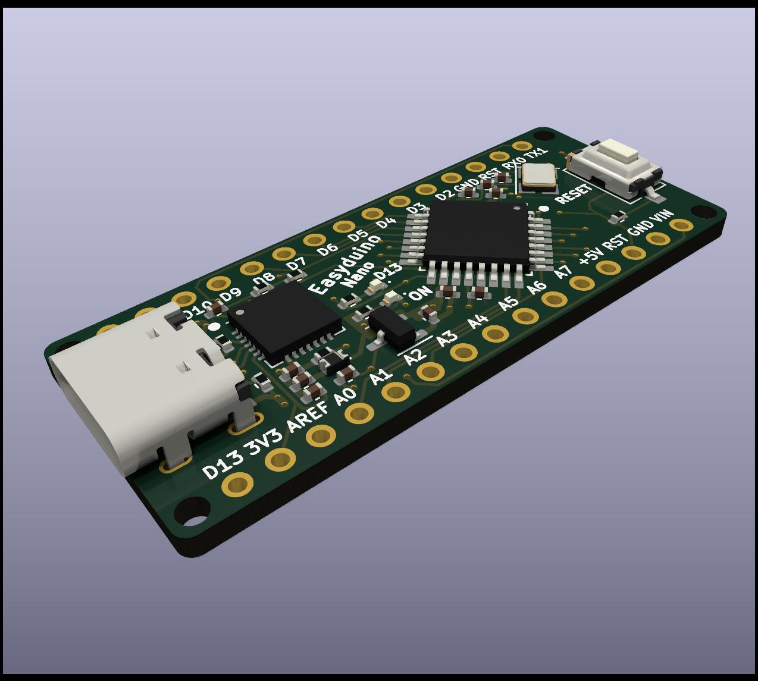
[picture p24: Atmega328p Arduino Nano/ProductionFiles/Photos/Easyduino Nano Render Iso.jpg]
    
</p>

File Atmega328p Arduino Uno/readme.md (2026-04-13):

# Easyduino Arduino

The Microcontroller that propelled the Maker and Hobbyst movements

<p align="center">
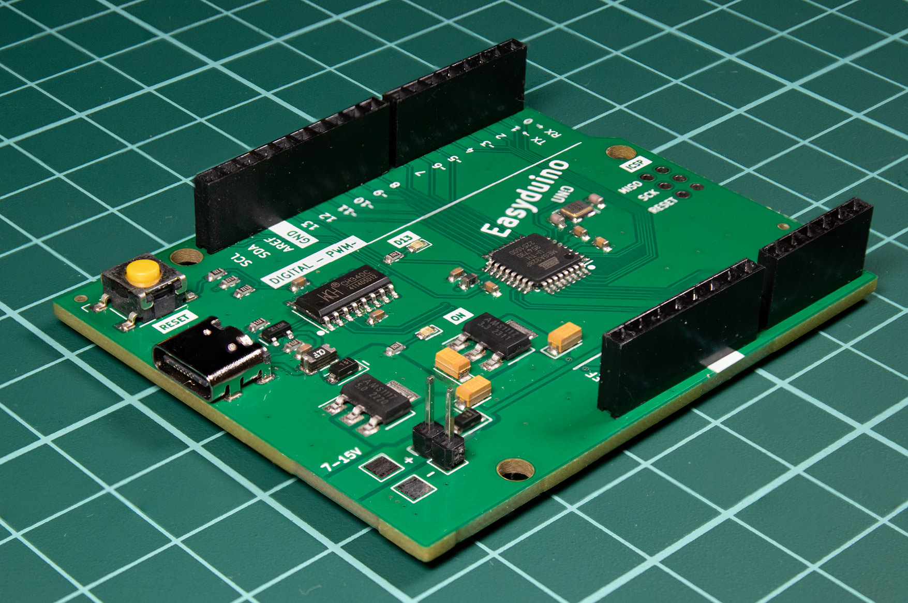
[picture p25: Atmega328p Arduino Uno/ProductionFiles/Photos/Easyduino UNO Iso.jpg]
    
</p>

## Schematic

<p align="center">
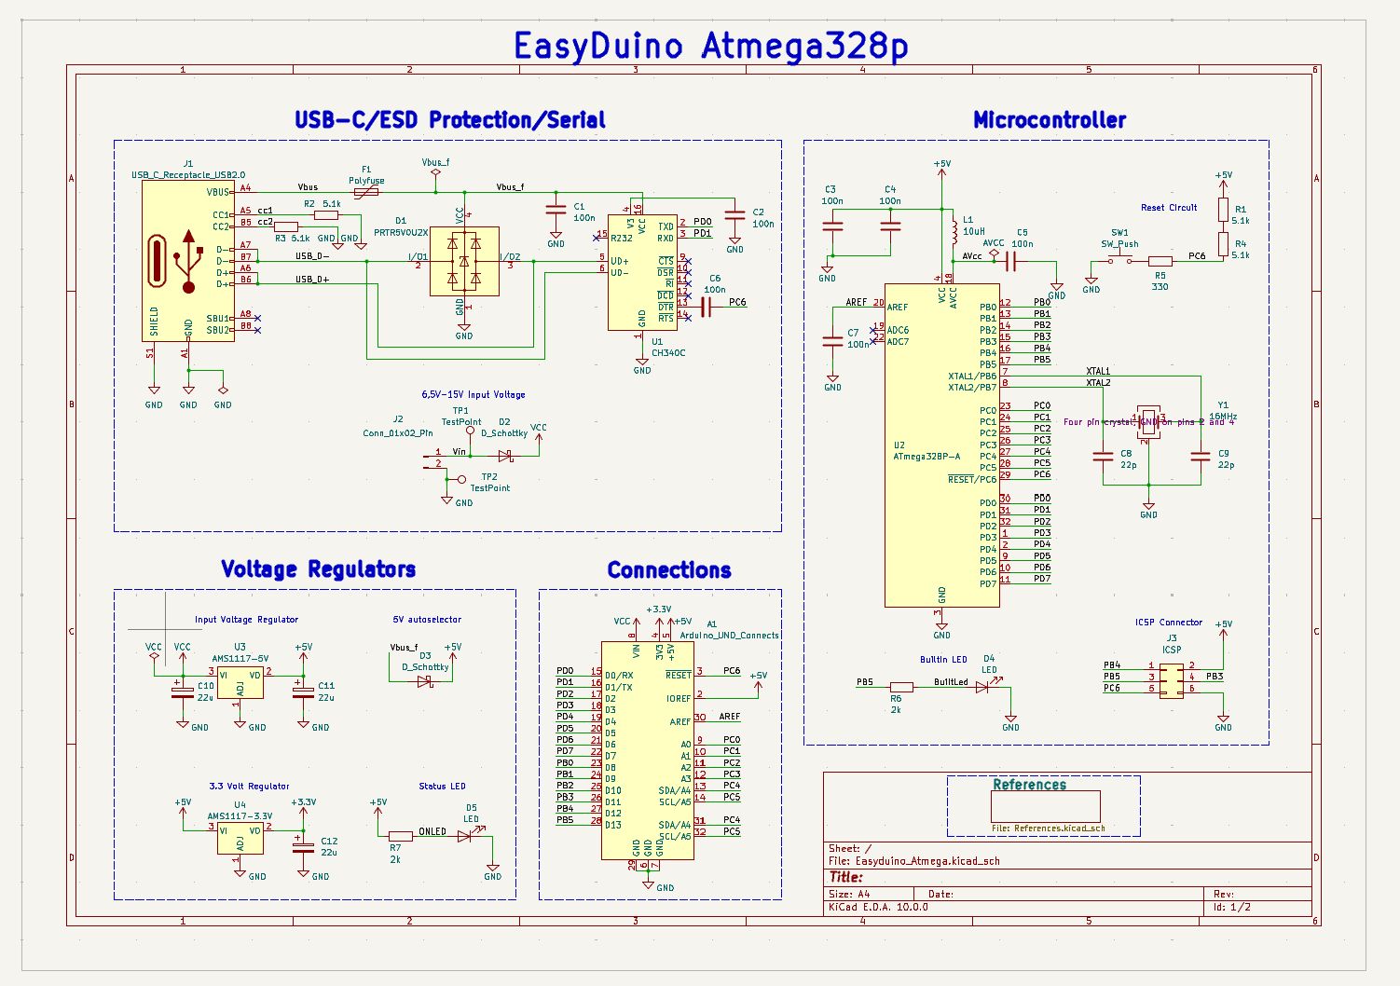
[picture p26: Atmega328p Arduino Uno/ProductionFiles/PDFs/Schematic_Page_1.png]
    
</p>

## Gerbers

<p align="center">
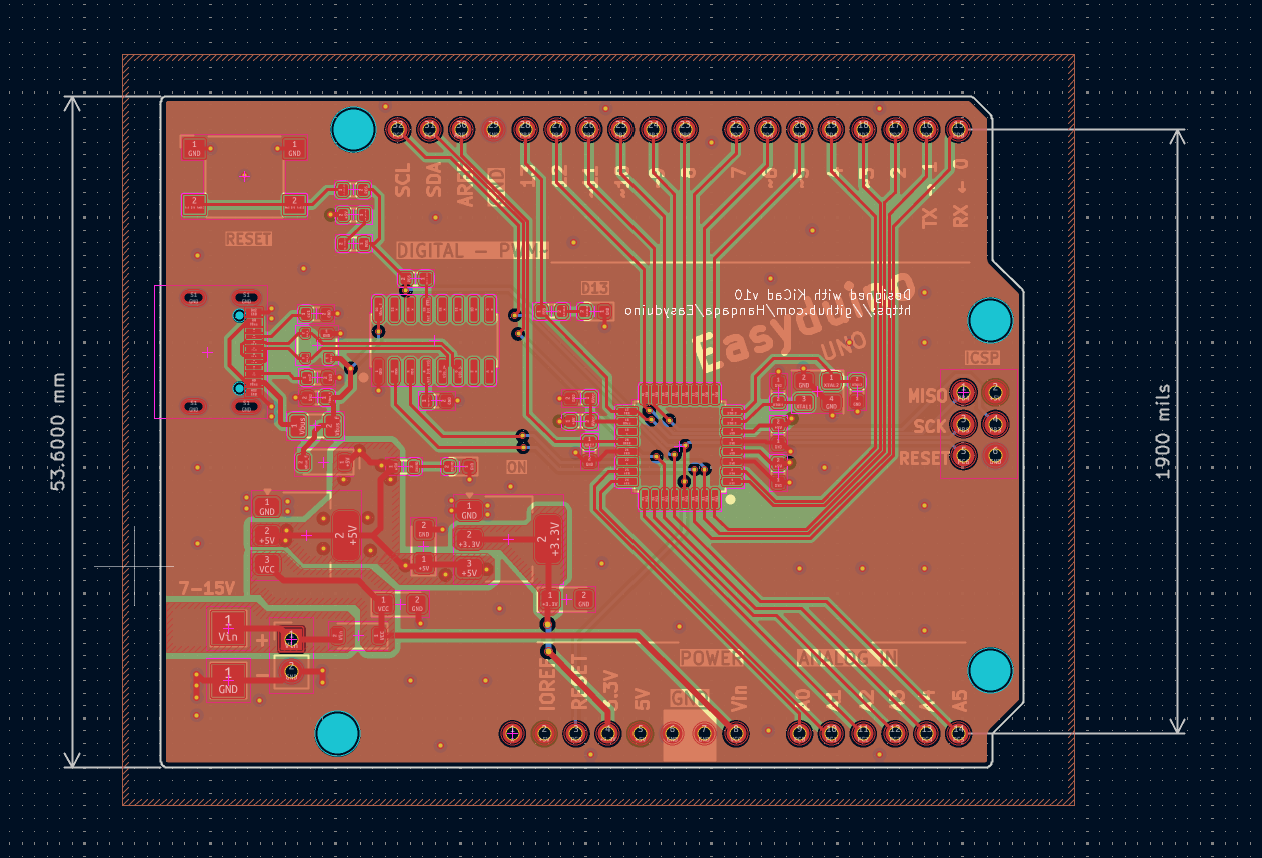
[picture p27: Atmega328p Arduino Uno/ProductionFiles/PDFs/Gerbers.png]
    
</p>

## Specs

- Input Voltage: 6.5V-15V(External Source Vin) 5V (USB). Both can be used at the same time.
- 5V Output Current: 1A (External Source) 500mA (USB)
- 3.3V Output Current: 500mA (External Source) 250 mA (USB)
- Polarity Protection (External Source) diode D2
- Overcurrent Protection: None (External Source) 1A (USB)
- 5V Autoselector: can take both USB and external source. A diode will avoid short circuit
- External Input Polarity protection: A diode will protect the circuit from a wrongly inserted battery. 

## References 

### Atmega 328p

#### Reset 

- Atmega Hardware Design Considerations p7,p8 -> 10kR, 100nF cap and 330R for switch. The 100nF is not used in Arduino (produces erors with DTR)
- The 100nF capacitor on DTR (CH340C) is used for tricking Arduino into Bootloader mode, it produces a voltage spike.

#### Crystal

- Atmega Hardware Design Considerations p16 -> 22pf

#### AVCC

- Atmega328 Reference Manual p213 -> 10uH ferrite bead and 100nF
- The Analog tracks aren't critical. I won't create an analog ground for these tracks

#### ICSP Connector

- Atmega Hardware Design Considerations p12

#### AREF

- Atmega Hardware Design Considerations p6 -> 100nF

### USB-C

#### Filtering 

- USB Hardware Design Guidelines for FTDI ICs p8 -> 10nF Cap + Ferrite Bead + 100nF Cap + 4.7uF Cap
- I disregarded such heavy filtering for the easier to implement 1uF and 100nF cap given in the CP2102 datasheet
- I added a polyfuse with Ihold=500mA and Itrip=1A.

#### Differential Pair

- USB needs 90 Ohm differential traces. 
- According to JLCPCB impedance calculator, with a JLC7628 prepreg and 6mil (0.15mm) space between lines
- I have to use 9 mil tracks -> 0.2 mm
- I will use a very short trace for D+ D- (around 2mm)
- I have to place vias because of the pinout of USB C and CP2102. Some other people have done it with no problems

#### CH340C

- Ch340 Datasheet: p10 -> 100nF between GND and V3.
- Ch340 Datasheet: p10 -> 100nF between GND and Vcc. Vcc to Vusb

#### AMS1117

- AMS1117 p4 -> 22uF tantalum capacitor on output
- I will use a 22uF to reuse the same capacitor
- I will reuse the output capacitor of AMS1117-5V to be the output capacitor of AMS1117-3.3V

#### 5V autoselector

- If USB is present and no external input voltage. The USB will power the ATMEGA
- If USB is present and there is external input voltage. The external voltage will power the ATMEGA
- If USB is not present and there is external input voltage. The external voltage will power the ATMEGA

## KiCad Render

<p align="center">
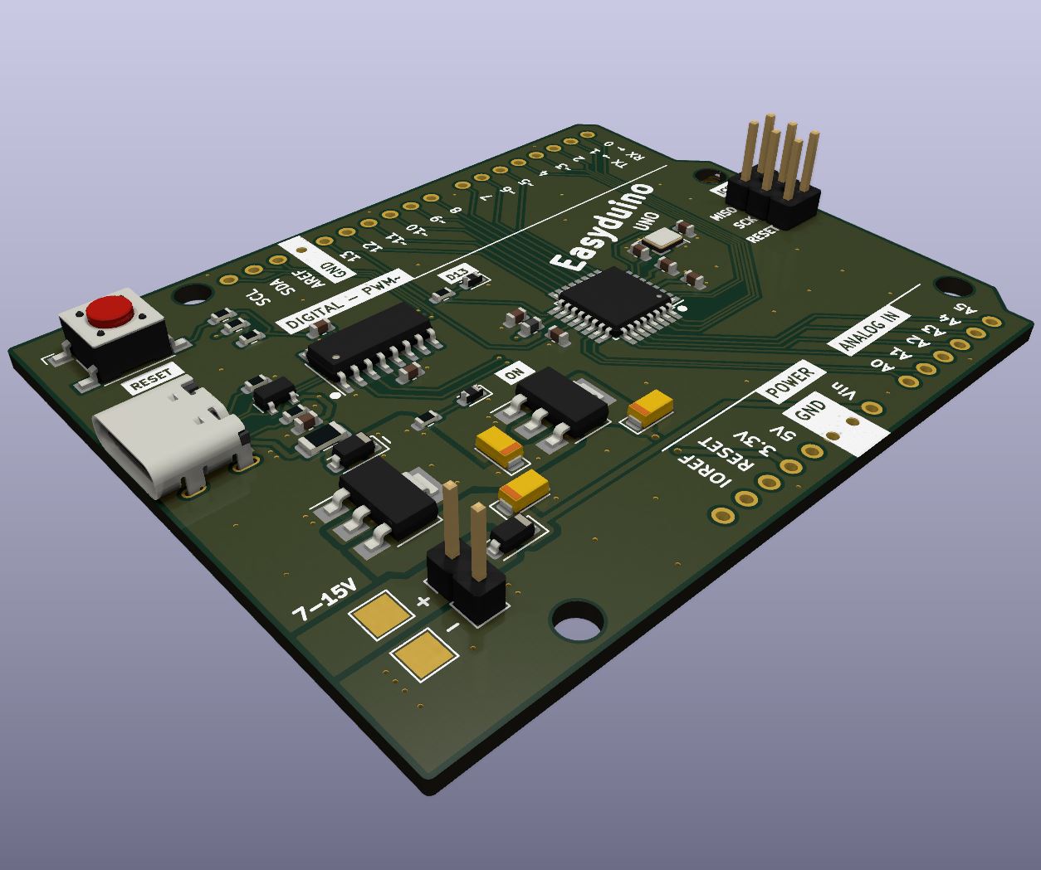
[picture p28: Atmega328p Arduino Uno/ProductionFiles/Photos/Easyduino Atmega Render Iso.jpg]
    
</p>

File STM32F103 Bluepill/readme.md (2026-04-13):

# Easyduino Bluepill STM32F103

The Industry Standard in the Microcontroller World

<p align="center">
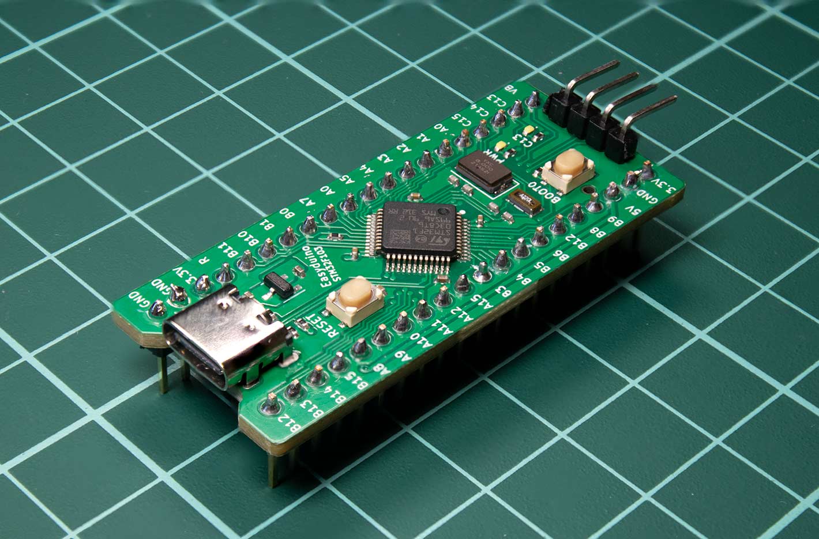
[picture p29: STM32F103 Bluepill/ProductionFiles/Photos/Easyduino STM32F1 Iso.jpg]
    
</p>

## Schematic

<p align="center">
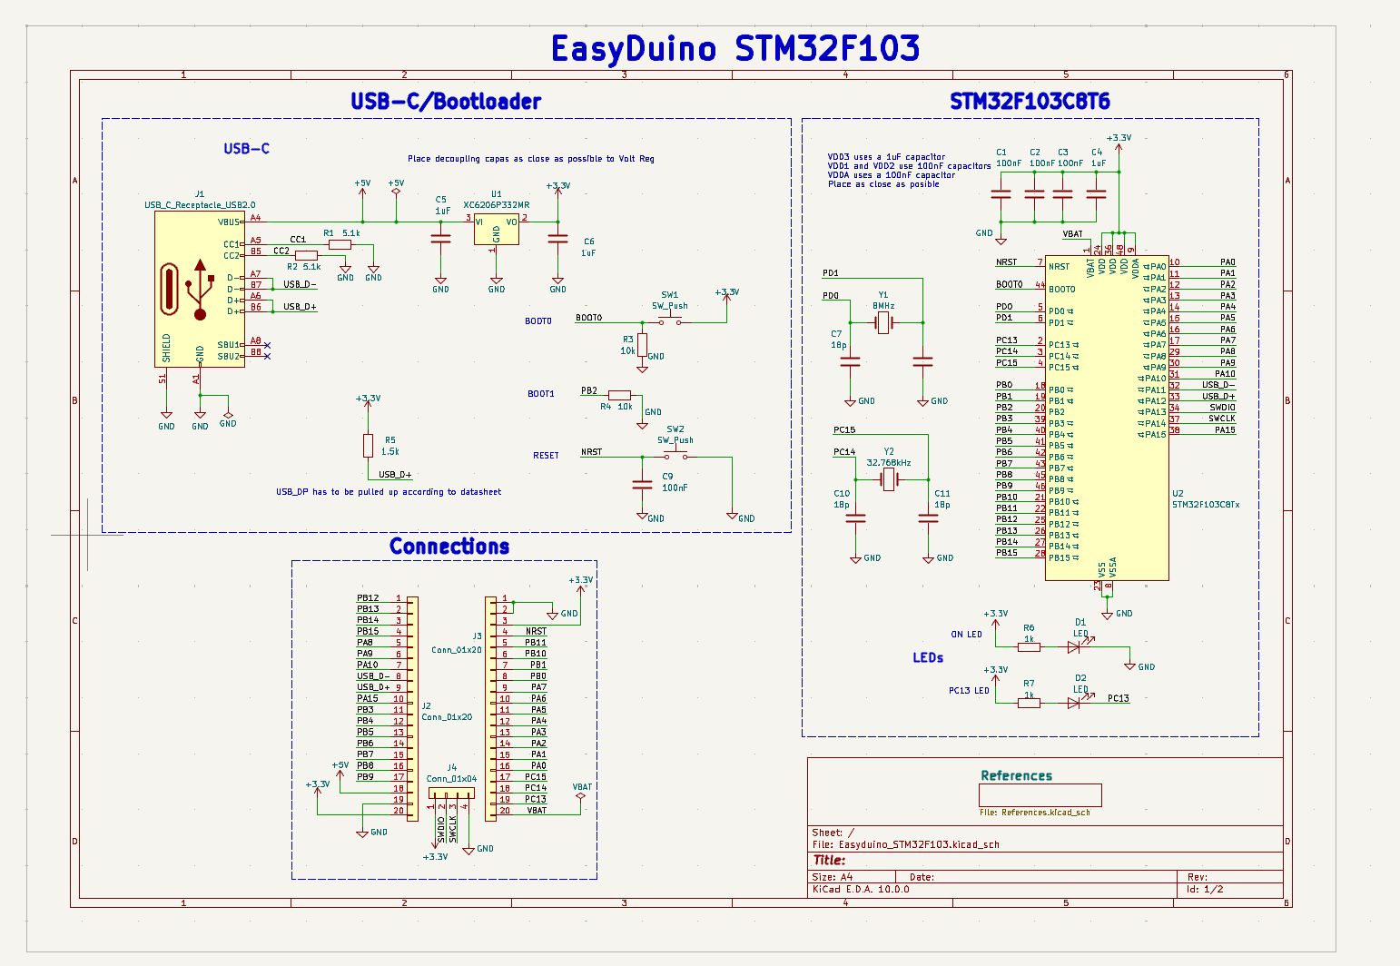
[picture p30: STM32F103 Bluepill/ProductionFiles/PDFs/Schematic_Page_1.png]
    
</p>

## Gerbers

<p align="center">
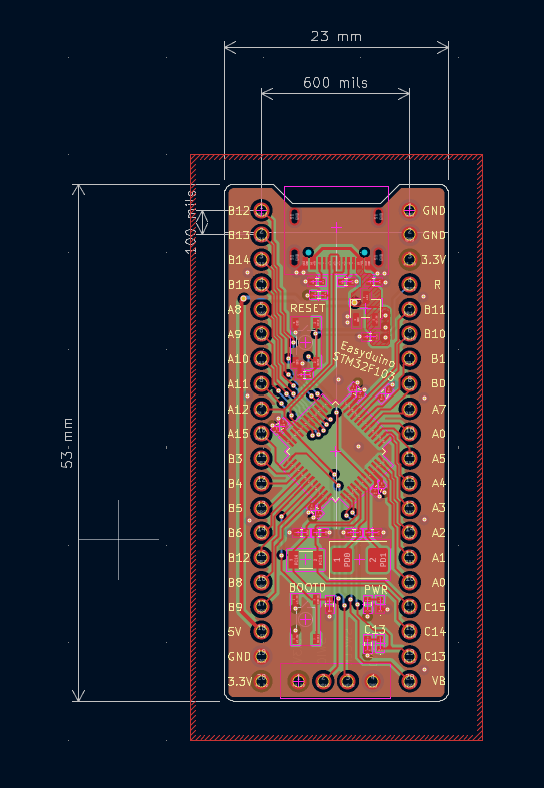
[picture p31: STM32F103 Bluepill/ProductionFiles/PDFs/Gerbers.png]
    
</p>

## Specs

- Input Voltage: 5.5V-9V(External Source through 5V pin) or 5V (USB). ONLY USE ONE VOLTAGE INPUT AT A TIME
- Maximum Output Current at 5V input : 200 mA at 3.3V output
- No Polarity Protection (External Source)
- Overcurrent Protection: None 

## References 

### STM32F103C8T6

#### Decoupling Capacitors 

- STM32F103x8 Datasheet p36 -> one 100nF decoupling capacitor per VDD pin except one 4.7uF capacitor in VDD3. I will use a 1uF capacitor in VDD3 to save costs
- STM32F103x8 Datasheet p36 -> one 10nF decoupling capacitor plus a 1uF capacitor for VDDA. I will not be needing very precise analog measurements. I will only use a 100nF capacitor

#### Crystals 

- STM32F103x8 Datasheet p54 -> PC14 PC15 use a 32.768 KHz resonator with approximately 15pF capacitors on each side. I will use 18pF
- STM32F103x8 Datasheet p52 -> PD0 PD1 use 8MHz crystal. Use 5-25 pF capacitors on each side. I will use 18pF

#### USB 

- STM32F103x8 Datasheet p 73-> No info about USB Data lines resistors. USB_D+ must be pulled up to 3.3 via 1.5k 
- Bluepill Schematic -> 20 Ohm USB Data lines terminator and a 4.7k pull up resistor
- Blackpill Schematic -> 10 Ohm USB Data lines terminator and a no pull up resistor
- I will trust the datasheet and not place resistors in USB lines and pull up to 3.3V. The Bluepill schematic is probably badly designed

#### NRST 

- STM32F103x8 Datasheet p67 -> NRST is connected to a switch and 100nF cap
- Bluepill Schematic -> 10k resistor and 100nF cap
- F031K6 Schematic -> NRST connected to a switch and 100nF cap
- Again I will trust the datasheet

#### Boot0 and Boot1 

- STM32F103x8 Hardware Development p16 -> Normally HIGH via a 10k resistor 
- Bluepill Schematic -> 100k resistors for both Boot0 and Boot1.
- Blackpill Schematic -> Boot1 tied to GND via 10k resistor. Boot0 tied to GND via 10k resistor and a push button to 3.3V
- The Blackpill and the Hardware Development guide agree. So i will place the 10k resistor and add a push button to Boot0

### USB-C

#### Filtering 

- USB Hardware Design Guidelines for FTDI ICs p8 -> 10nF Cap + Ferrite Bead + 100nF Cap + 4.7uF Cap
- I disregarded such heavy filtering for the easier to implement 1uF and 100nF cap given in the CP2102 datasheet
- I added a polyfuse with Ihold=500mA and Itrip=1A.

#### Differential Pair

- USB needs 90 Ohm differential traces. 
- According to JLCPCB impedance calculator, with a JLC7628 prepreg and 6mil (0.15mm) space between lines
- I have to use 9 mil tracks -> 0.2 mm
- I will use a very short trace for D+ D- (around 2mm)
- I have to place vias because of the pinout of USB C and CP2102. Some other people have done it with no problems

#### XC6206P332MR-3.3V

- XC6206_Torex Datasheet p6 -> Two 1 uF ceramic capacitors on Vin and Vout

## KiCad Render

<p align="center">
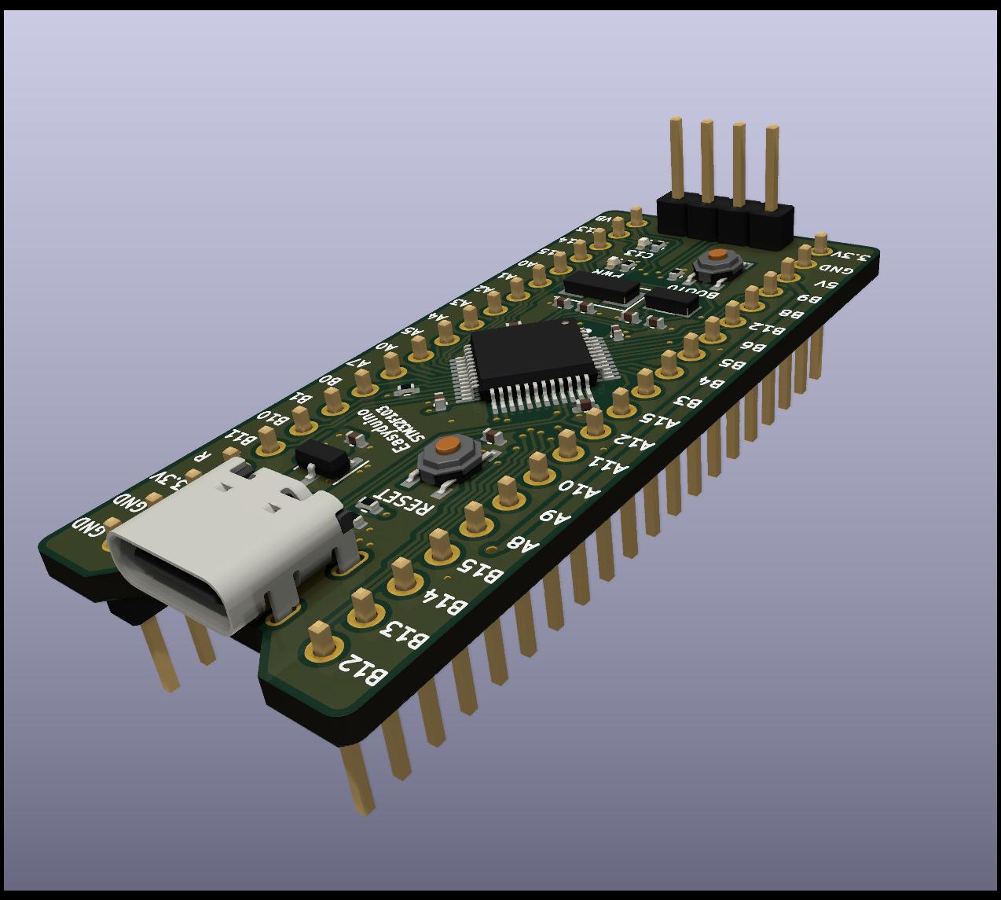
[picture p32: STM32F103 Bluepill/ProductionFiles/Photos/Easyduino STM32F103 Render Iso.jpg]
    
</p>

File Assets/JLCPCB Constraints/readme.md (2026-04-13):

# JLCPCB Constraints for 2 layer boards

In order to make the boards as easy to manufacture as possible. I will choose the [2 layer boards constraints on JLCPCB](https://jlcpcb.com/capabilities/pcb-capabilities). Even though they were later manufactured using 4 layers for the sole reason of being easier to route.

### PCB constraints 

- Minimum clearance: 0.128mm
- Minimum track width: 0.128mm
- Minimum connection width: 0mm
- Minimum annular width: 0.1mm
- Minimum via diameter: 0.5mm
- Copper to hole clearance: 0.254mm (I mistakenly used 0.25mm! This has not been fixed as it would require retracking all the boards. The manufacturer has not complained about those 0.004mm)
- Copper to edge clearance: 0.4mm (Some boards were manufactured with 0mm clearance, but the gerbers were later fixed)
- Minimum through hole: 0.3mm
- Hole to hole clearance: 0.254mm (I mistakenly used 0.25mm)
- uVias: not used
 
 <p align="center">
    
</p>

### Assembly constraints

- 0402 maximum package for Economic assemble. Around $15 or 15€ cheaper than the Standard Assembly which allows 0201 parts.
- Check Confirm Parts Placement. They changed the polarity of my Tantalum capacitors on the Easyduino UNO without contacting me!! I had to resolder them later.

## Stackup constraints

I chose the [JLC04161H-7628](https://jlcpcb.com/impedance) stackup with the following characteristics:

 <p align="center">
    
</p>

With Signal Layer (Layer 1) and a GND layer (L2) below. And with 0.2mm tracks and separated 0.15mm gives a differential pair impedance of approximately 90 Ohms. 

 <p align="center">
    
</p>

## Fill zones constraints

 <p align="center">
    
</p>

## CPL (Component Placement List)

JLCPCB asks for the start of the position-top-pos.csv generated file by KiCad to be changed to:

```
Designator,Val,Package,Mid X ,Mid Y ,Rotation,Layer
```

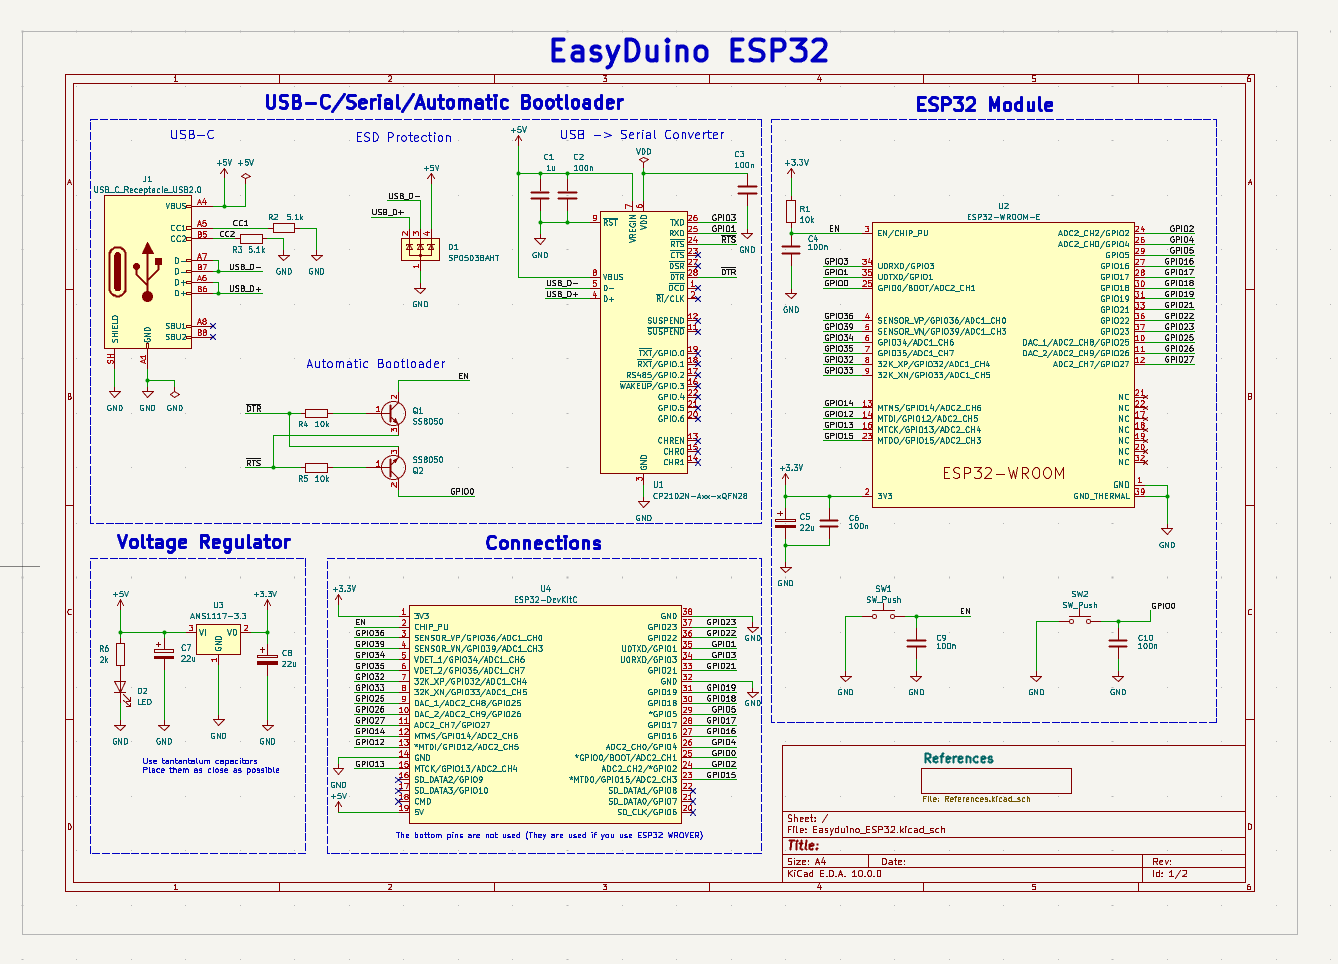
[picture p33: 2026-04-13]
Assets/Schematic/ESP32.png

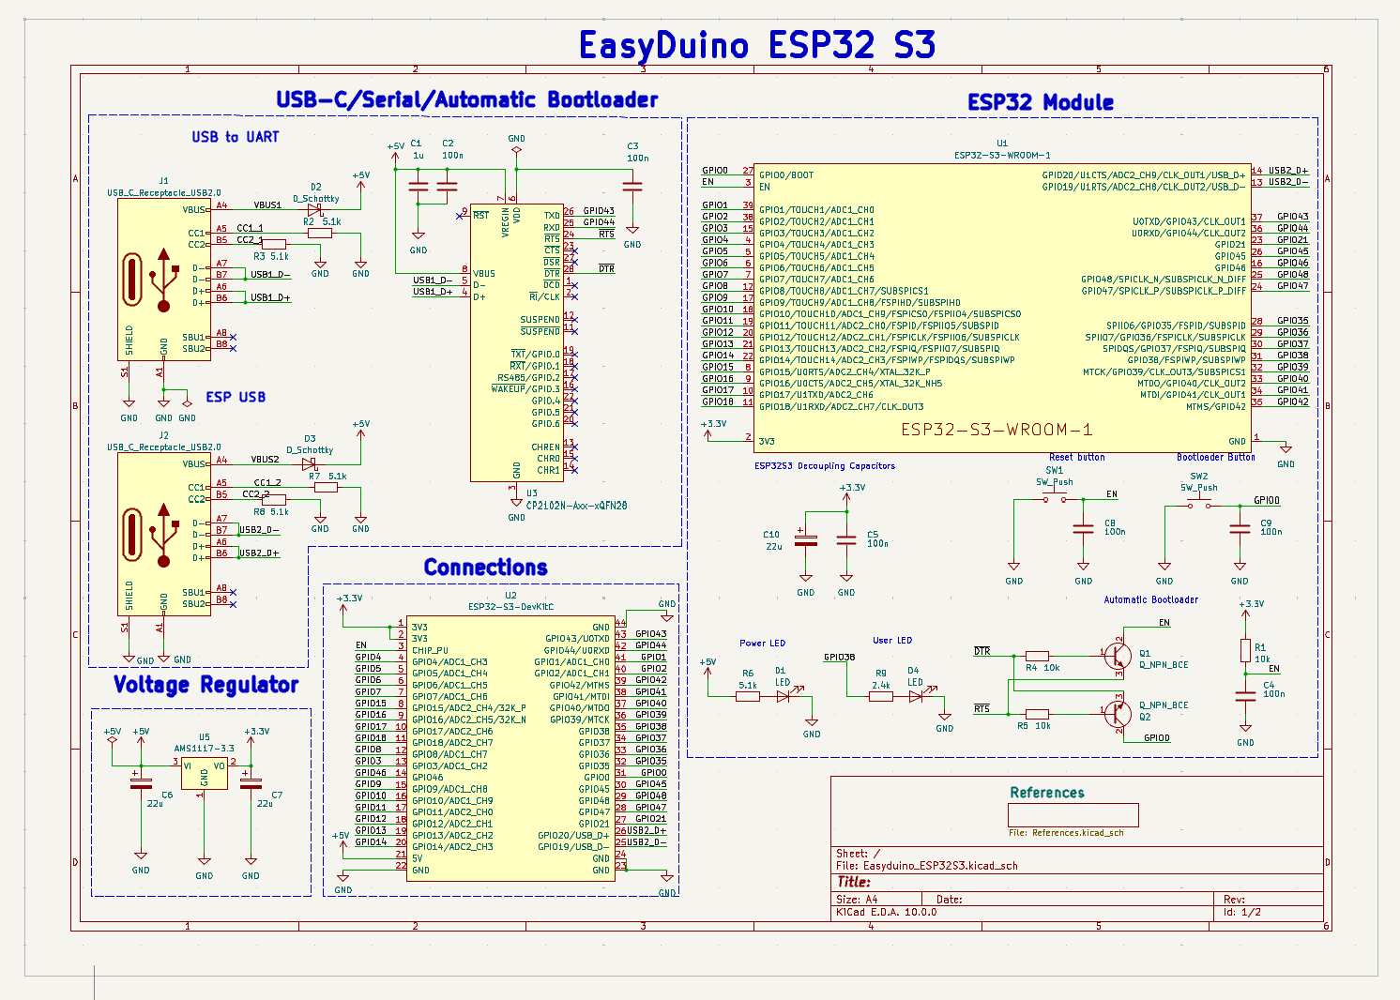
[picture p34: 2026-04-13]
Assets/Schematic/ESP32S3.png

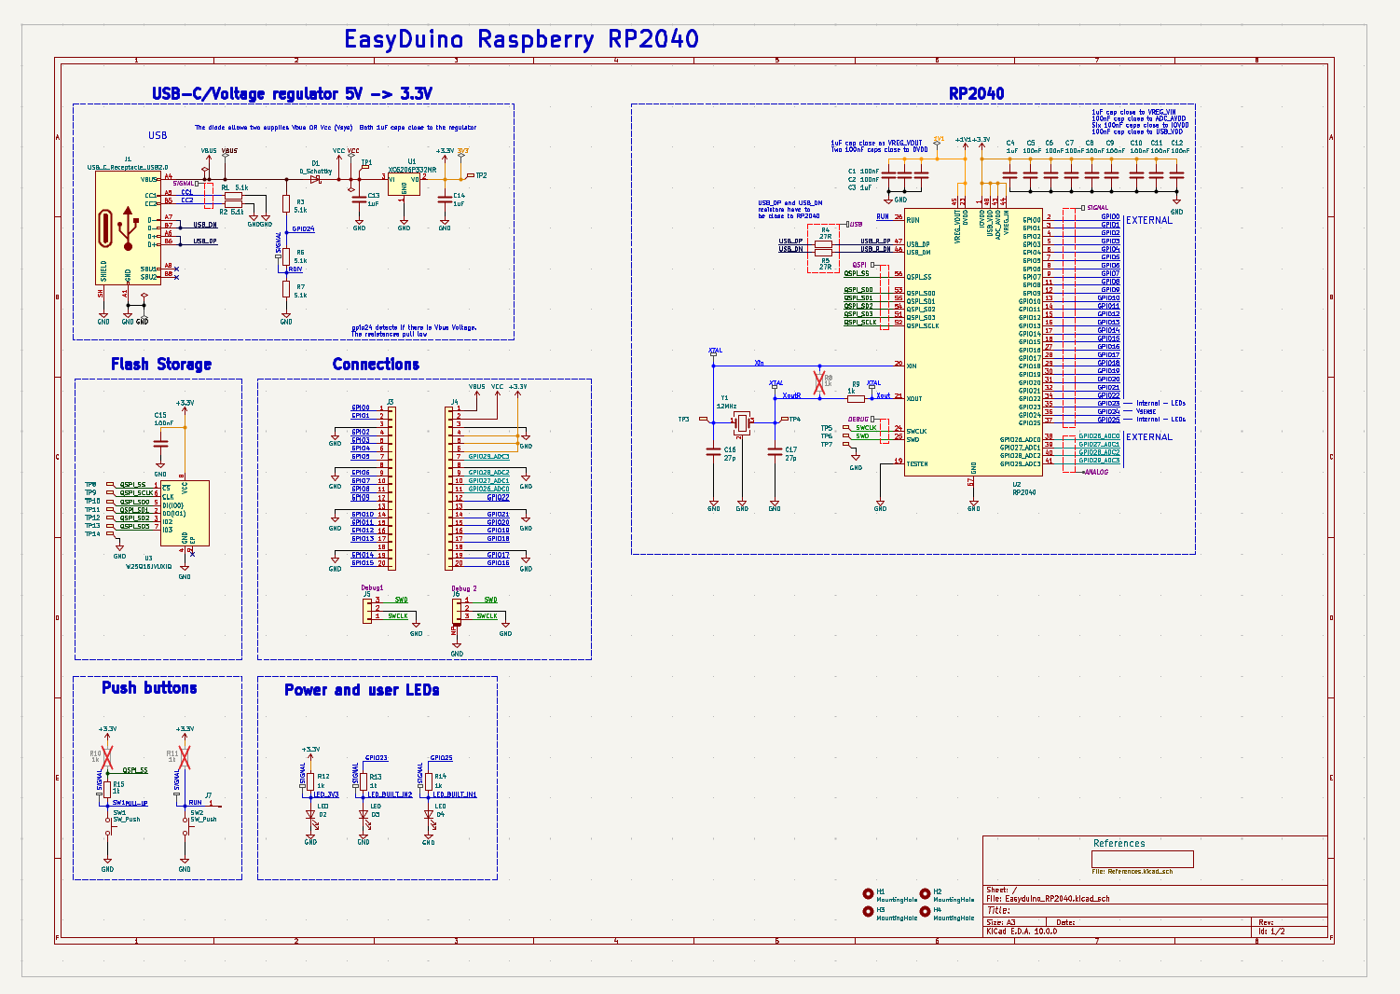
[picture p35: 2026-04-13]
Assets/Schematic/RaspberryPico.png

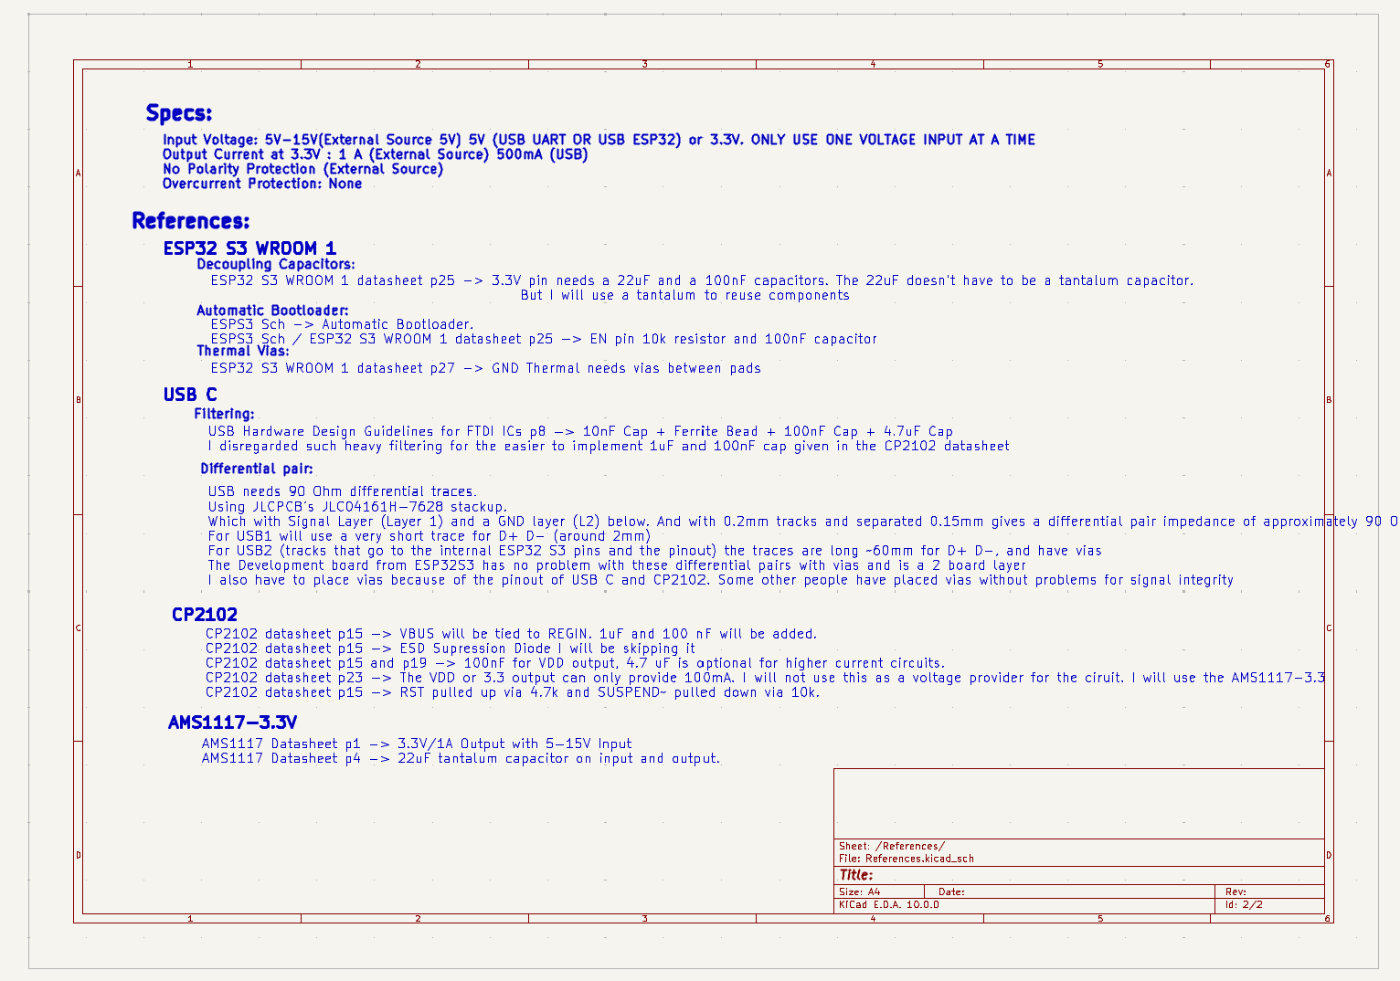
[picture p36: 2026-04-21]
ESP32S3/ProductionFiles/PDFs/Schematic_Page_2.png

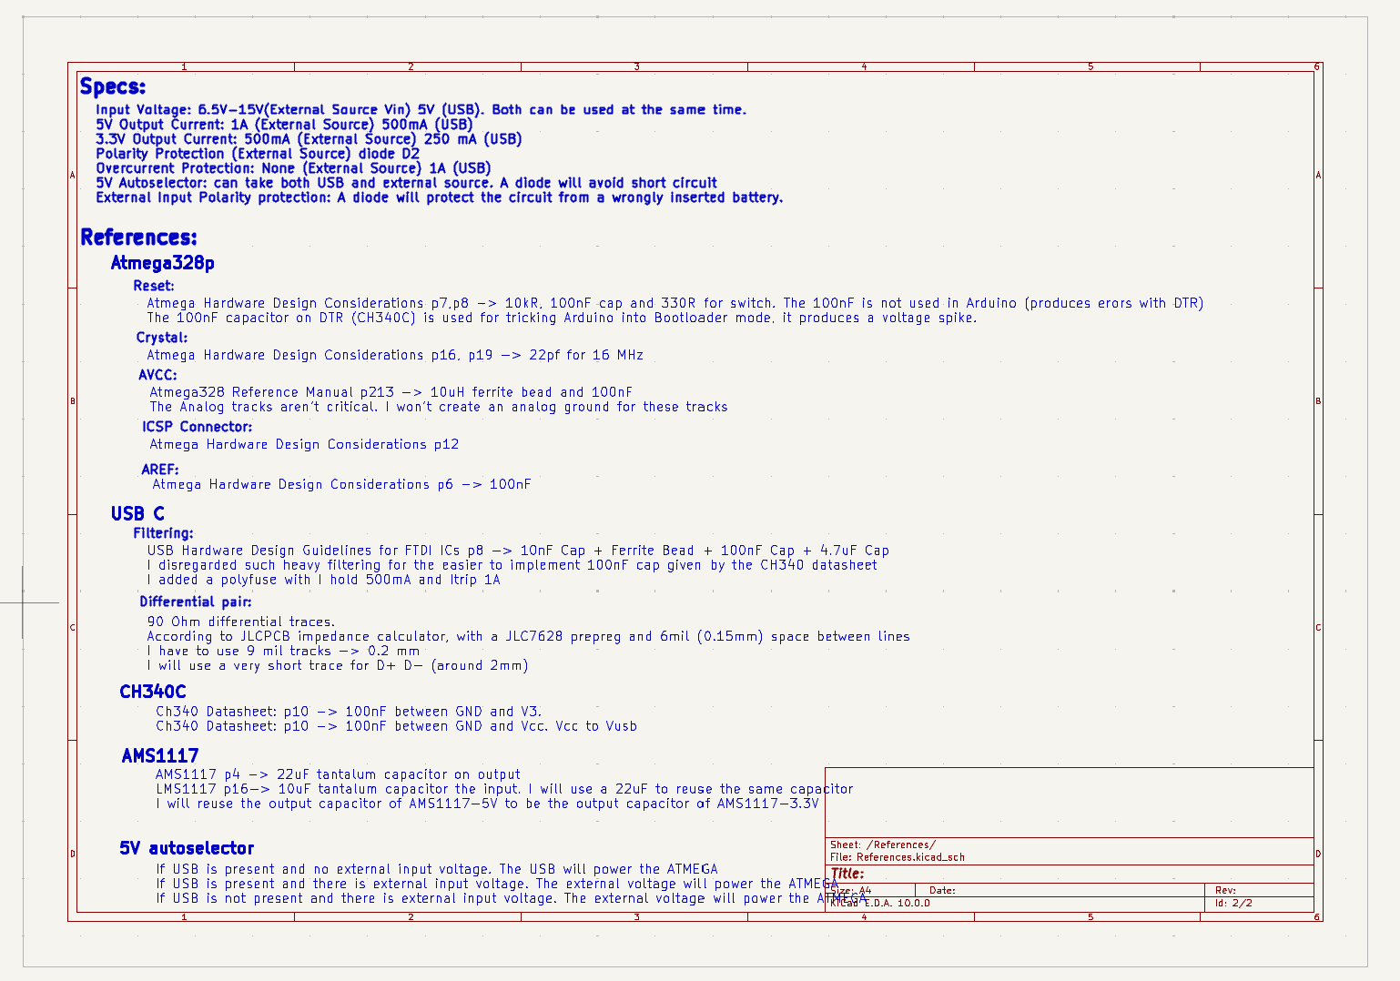
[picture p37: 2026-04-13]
Atmega328p Arduino Uno/ProductionFiles/PDFs/Schematic_Page_2.png

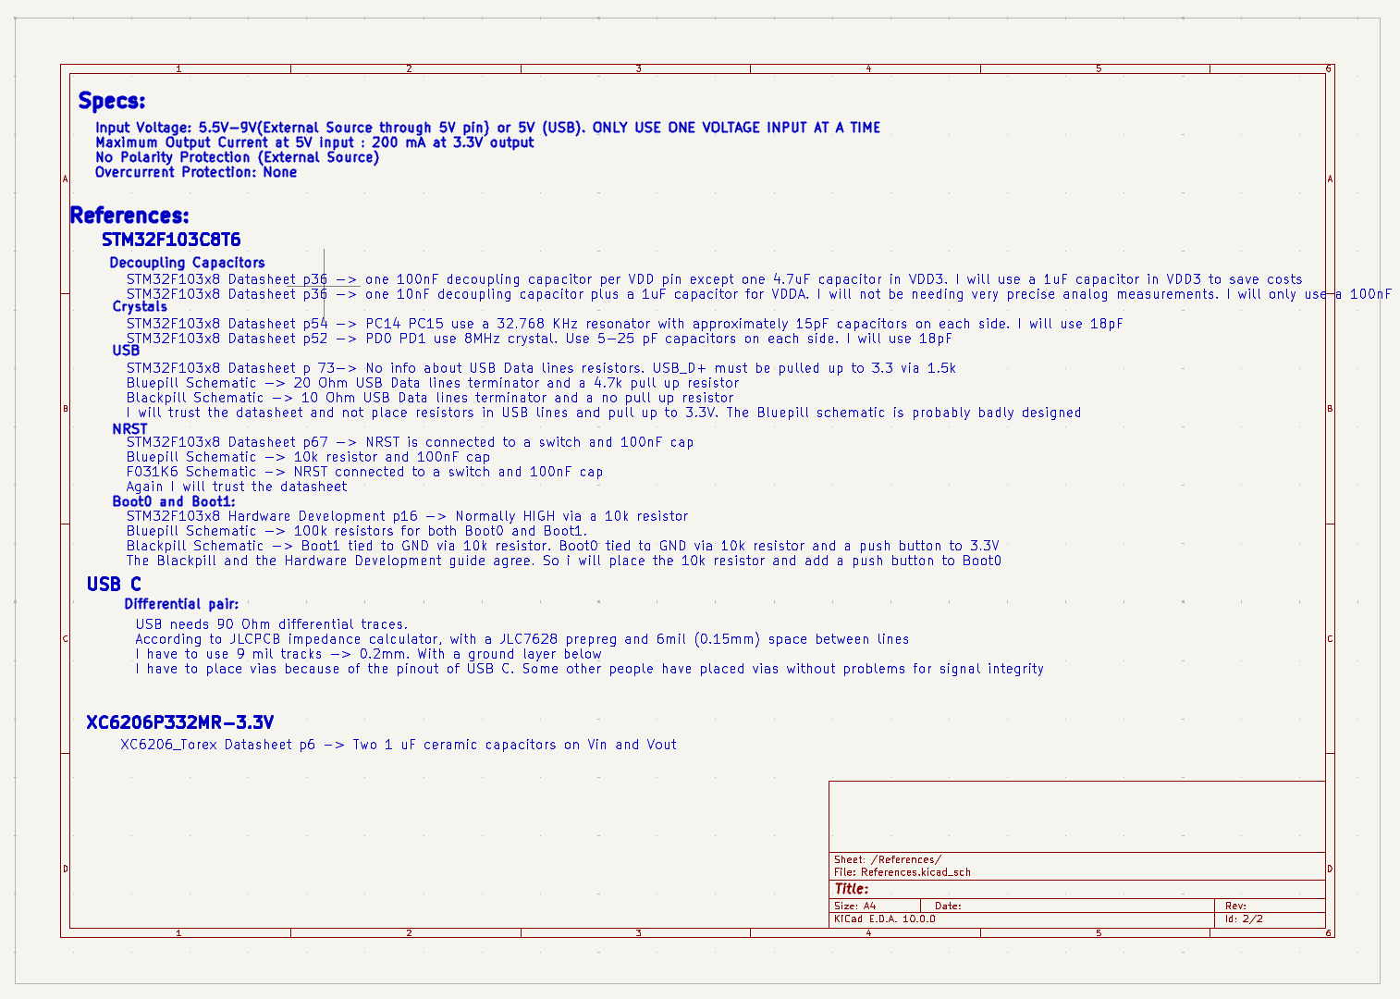
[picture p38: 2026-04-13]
STM32F103 Bluepill/ProductionFiles/PDFs/Schematic_Page_2.png

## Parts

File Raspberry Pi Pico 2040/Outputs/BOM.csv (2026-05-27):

Reference | Value | Qty | # | LCSC
C1 | 100nF | 1 | 1 | C1525
C2 | 100nF | 1 | 2 | C1525
C3 | 1uF | 1 | 3 | C52923
C4 | 1uF | 1 | 4 | C52923
C5 | 100nF | 1 | 5 | C1525
C6 | 100nF | 1 | 6 | C1525
C7 | 100nF | 1 | 7 | C1525
C8 | 100nF | 1 | 8 | C1525
C9 | 100nF | 1 | 9 | C1525
C10 | 100nF | 1 | 10 | C1525
C11 | 100nF | 1 | 11 | C1525
C12 | 100nF | 1 | 12 | C1525
C13 | 1uF | 1 | 13 | C52923
C14 | 1uF | 1 | 14 | C52923
C15 | 100nF | 1 | 15 | C1525
C16 | 27p | 1 | 16 | C1557
C17 | 27p | 1 | 17 | C1557
D1 | D_Schottky | 1 | 18 | C8598
D2 | LED | 1 | 19 | C434448
D3 | LED | 1 | 20 | C434448
D4 | LED | 1 | 21 | C434448
H1 | MountingHole | 1 | 22 | -
H2 | MountingHole | 1 | 23 | -
H3 | MountingHole | 1 | 24 | -
H4 | MountingHole | 1 | 25 | -
J1 | USB_C_Receptacle_USB2.0 | 1 | 26 | C2765186
J3 | Conn_01x20 | 1 | 27 | -
J4 | Conn_01x20 | 1 | 28 | -
J5 | Conn_01x03 | 1 | 29 | -
J6 | Conn_01x03_MountingPin | 1 | 30 | C160389
R1 | 5.1k | 1 | 31 | C25905
R2 | 5.1k | 1 | 32 | C25905
R3 | 5.1k | 1 | 33 | C25905
R4 | 27R | 1 | 34 | C2909343
R5 | 27R | 1 | 35 | C2909343
R6 | 5.1k | 1 | 36 | C25905
R7 | 5.1k | 1 | 37 | C25905
R9 | 1k | 1 | 38 | C11702
R12 | 1k | 1 | 39 | C11702
R13 | 1k | 1 | 40 | C11702
R14 | 1k | 1 | 41 | C11702
R15 | 1k | 1 | 42 | C11702
SW1 | SW_Push | 1 | 43 | C139797
SW2 | SW_Push | 1 | 44 | C139797
TP1 |  | 1 | 45
TP2 |  | 1 | 46
TP3 |  | 1 | 47
TP4 |  | 1 | 48
TP5 |  | 1 | 49
TP6 |  | 1 | 50
TP7 |  | 1 | 51
TP8 |  | 1 | 52
TP9 |  | 1 | 53
TP10 |  | 1 | 54
TP11 |  | 1 | 55
TP12 |  | 1 | 56
TP13 |  | 1 | 57
TP14 |  | 1 | 58
U1 | XC6206P332MR | 1 | 59 | C347376
U2 | RP2040 | 1 | 60 | C2040
U3 | W25Q16JVUXIQ | 1 | 61 | C2843335
Y1 | 12MHz | 1 | 62 | C9002

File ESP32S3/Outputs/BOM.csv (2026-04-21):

Reference | Value | Qty | # | LCSC
C1 | 1u | 1 | 1 | C52923
C2 | 100n | 1 | 2 | C1525
C3 | 100n | 1 | 3 | C1525
C4 | 100n | 1 | 4 | C1525
C5 | 100n | 1 | 5 | C1525
C6 | 22u | 1 | 6 | C11366
C7 | 22u | 1 | 7 | C11366
C8 | 100n | 1 | 8 | C1525
C9 | 100n | 1 | 9 | C1525
C10 | 22u | 1 | 10 | C11366
D1 | LED | 1 | 11 | C434447
D2 | D_Schottky | 1 | 12 | C2837790
D3 | D_Schottky | 1 | 13 | C2837790
D4 | LED | 1 | 14 | C434447
J1 | USB_C_Receptacle_USB2.0 | 1 | 15 | C2765186
J2 | USB_C_Receptacle_USB2.0 | 1 | 16 | C2765186
Q1 | Q_NPN_BCE | 1 | 17 | C916392
Q2 | Q_NPN_BCE | 1 | 18 | C916392
R1 | 10k | 1 | 19 | C25744
R2 | 5.1k | 1 | 20 | C25905
R3 | 5.1k | 1 | 21 | C25905
R4 | 10k | 1 | 22 | C25744
R5 | 10k | 1 | 23 | C25744
R6 | 5.1k | 1 | 24 | C25905
R7 | 5.1k | 1 | 25 | C25905
R8 | 5.1k | 1 | 26 | C25905
R9 | 2.4k | 1 | 27 | C25882
R10 | 10k | 1 | 28 | C25744
R11 | 5.1k | 1 | 29 | C25905
SW1 | SW_Push | 1 | 30 | C720477
SW2 | SW_Push | 1 | 31 | C720477
U1 | ESP32-S3-WROOM-1 | 1 | 32 | C2913197
U2 | ESP32-S3-DevKitC | 1 | 33 | -
U3 | CP2102N-Axx-xQFN28 | 1 | 34 | C6568
U5 | AMS1117-3.3 | 1 | 35 | C6186

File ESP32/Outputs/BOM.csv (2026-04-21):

Reference | Value | Qty | # | LCSC
C1 | 1u | 1 | 1 | C52923
C2 | 100n | 1 | 2 | C1525
C3 | 100n | 1 | 3 | C1525
C4 | 100n | 1 | 4 | C1525
C5 | 22u | 1 | 5 | C11366
C6 | 100n | 1 | 6 | C1525
C7 | 22u | 1 | 7 | C11366
C8 | 22u | 1 | 8 | C11366
C9 | 100n | 1 | 9 | C1525
C10 | 100n | 1 | 10 | C1525
D1 | SP0503BAHT | 1 | 11 | C7074
D2 | LED | 1 | 12 | C434447
J1 | USB_C_Receptacle_USB2.0 | 1 | 13 | C2765186
Q1 | SS8050 | 1 | 14 | C916392
Q2 | SS8050 | 1 | 15 | C916392
R1 | 10k | 1 | 16 | C25744
R2 | 5.1k | 1 | 17 | C25905
R3 | 5.1k | 1 | 18 | C25905
R4 | 10k | 1 | 19 | C25744
R5 | 10k | 1 | 20 | C25744
R6 | 2k | 1 | 21 | C4109
R7 | 10k | 1 | 22 | C25744
R8 | 5.1k | 1 | 23 | C25905
SW1 | SW_Push | 1 | 24 | C720477
SW2 | SW_Push | 1 | 25 | C720477
U1 | CP2102N-Axx-xQFN28 | 1 | 26 | C6568
U2 | ESP32-WROOM-E | 1 | 27 | C701342
U3 | AMS1117-3.3 | 1 | 28 | C6186
U4 | ESP32-DevKitC | 1 | 29 | -

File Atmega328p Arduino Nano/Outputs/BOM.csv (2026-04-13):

Reference | Value | Qty | # | LCSC
A1 | Arduino_Nano_v3.x | 1 | 1 | -
C1 | 1u | 1 | 2 | C52923
C2 | 100n | 1 | 3 | C1525
C3 | 100n | 1 | 4 | C1525
C4 | 100n | 1 | 5 | C1525
C5 | 100n | 1 | 6 | C1525
C6 | 100n | 1 | 7 | C1525
C7 | 100n | 1 | 8 | C1525
C8 | 100n | 1 | 9 | C1525
C9 | 22p | 1 | 10 | C1555
C10 | 22p | 1 | 11 | C1555
C11 | 1u | 1 | 12 | C52923
C12 | 1u | 1 | 13 | C52923
D1 | LED | 1 | 14 | C434447
D2 | D_Schottky | 1 | 15 | C2837790
D3 | LED | 1 | 16 | C434447
F1 | Polyfuse | 1 | 17 | C914087
J1 | USB_C_Receptacle_USB2.0 | 1 | 18 | C2765186
J2 | ICSP | 1 | 19 | -
R1 | 5.1k | 1 | 20 | C25905
R2 | 5.1k | 1 | 21 | C25905
R3 | 5.1k | 1 | 22 | C25905
R4 | 5.1k | 1 | 23 | C25905
R5 | 330 | 1 | 24 | C25104
R6 | 2k | 1 | 25 | C4109
R7 | 2k | 1 | 26 | C4109
SW1 | SW_Push | 1 | 27 | C520860
U1 | ATmega328P-A | 1 | 28 | C14877
U2 | XC6206P502MR | 1 | 29 | C16767
U3 | CP2102N-Axx-xQFN28 | 1 | 30 | C6568
Y1 | 16 MHz | 1 | 31 | C13738

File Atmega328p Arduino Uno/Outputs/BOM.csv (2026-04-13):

Reference | Value | Qty | # | LCSC
A1 | Arduino_UNO_Connects | 1 | 1 | -
C1 | 100n | 1 | 2 | C14663
C2 | 100n | 1 | 3 | C14663
C3 | 100n | 1 | 4 | C14663
C4 | 100n | 1 | 5 | C14663
C5 | 100n | 1 | 6 | C14663
C6 | 100n | 1 | 7 | C14663
C7 | 100n | 1 | 8 | C14663
C8 | 22p | 1 | 9 | C1653
C9 | 22p | 1 | 10 | C1653
C10 | 22u | 1 | 11 | C11366
C11 | 22u | 1 | 12 | C11366
C12 | 22u | 1 | 13 | C11366
D1 | PRTR5V0U2X | 1 | 14 | C2827688
D2 | D_Schottky | 1 | 15 | C8598
D3 | D_Schottky | 1 | 16 | C8598
D4 | LED | 1 | 17 | C72043
D5 | LED | 1 | 18 | C72043
F1 | Polyfuse | 1 | 19 | C70077
J1 | USB_C_Receptacle_USB2.0 | 1 | 20 | C2765186
J2 | Conn_01x02_Pin | 1 | 21 | -
J3 | ICSP | 1 | 22 | -
L1 | 10uH | 1 | 23 | C51942
R1 | 5.1k | 1 | 24 | C23186
R2 | 5.1k | 1 | 25 | C23186
R3 | 5.1k | 1 | 26 | C23186
R4 | 5.1k | 1 | 27 | C23186
R5 | 330 | 1 | 28 | C23138
R6 | 2k | 1 | 29 | C22940
R7 | 2k | 1 | 30 | C22940
SW1 | SW_Push | 1 | 31 | C271751
TP1 | TestPoint | 1 | 32 | -
TP2 | TestPoint | 1 | 33 | -
U1 | CH340C | 1 | 34 | C84681
U2 | ATmega328P-A | 1 | 35 | C14877
U3 | AMS1117-5V | 1 | 36 | C6187
U4 | AMS1117-3.3V | 1 | 37 | C6186
Y1 | 16MHz | 1 | 38 | C13738

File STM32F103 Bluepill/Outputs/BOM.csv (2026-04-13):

Reference | Value | Qty | # | LCSC
C1 | 100nF | 1 | 1 | C1525
C2 | 100nF | 1 | 2 | C1525
C3 | 100nF | 1 | 3 | C1525
C4 | 1uF | 1 | 4 | C52923
C5 | 1uF | 1 | 5 | C52923
C6 | 1uF | 1 | 6 | C52923
C7 | 18p | 1 | 7 | C1549
C8 | 18p | 1 | 8 | C1549
C9 | 100nF | 1 | 9 | C1525
C10 | 18p | 1 | 10 | C1549
C11 | 18p | 1 | 11 | C1549
D1 | LED | 1 | 12 | C434448
D2 | LED | 1 | 13 | C434448
J1 | USB_C_Receptacle_USB2.0 | 1 | 14 | C2765186
J2 | Conn_01x20 | 1 | 15 | -
J3 | Conn_01x20 | 1 | 16 | -
J4 | Conn_01x04 | 1 | 17 | -
R1 | 5.1k | 1 | 18 | C25905
R2 | 5.1k | 1 | 19 | C25905
R3 | 10k | 1 | 20 | C25744
R4 | 10k | 1 | 21 | C25744
R5 | 1.5k | 1 | 22 | C25867
R6 | 1k | 1 | 23 | C11702
R7 | 1k | 1 | 24 | C11702
SW1 | SW_Push | 1 | 25 | C139797
SW2 | SW_Push | 1 | 26 | C139797
U1 | XC6206P332MR | 1 | 27 | C347376
U2 | STM32F103C8Tx | 1 | 28 | C8734
Y1 | 8MHz | 1 | 29 | C115962
Y2 | 32.768kHz | 1 | 30 | C32346

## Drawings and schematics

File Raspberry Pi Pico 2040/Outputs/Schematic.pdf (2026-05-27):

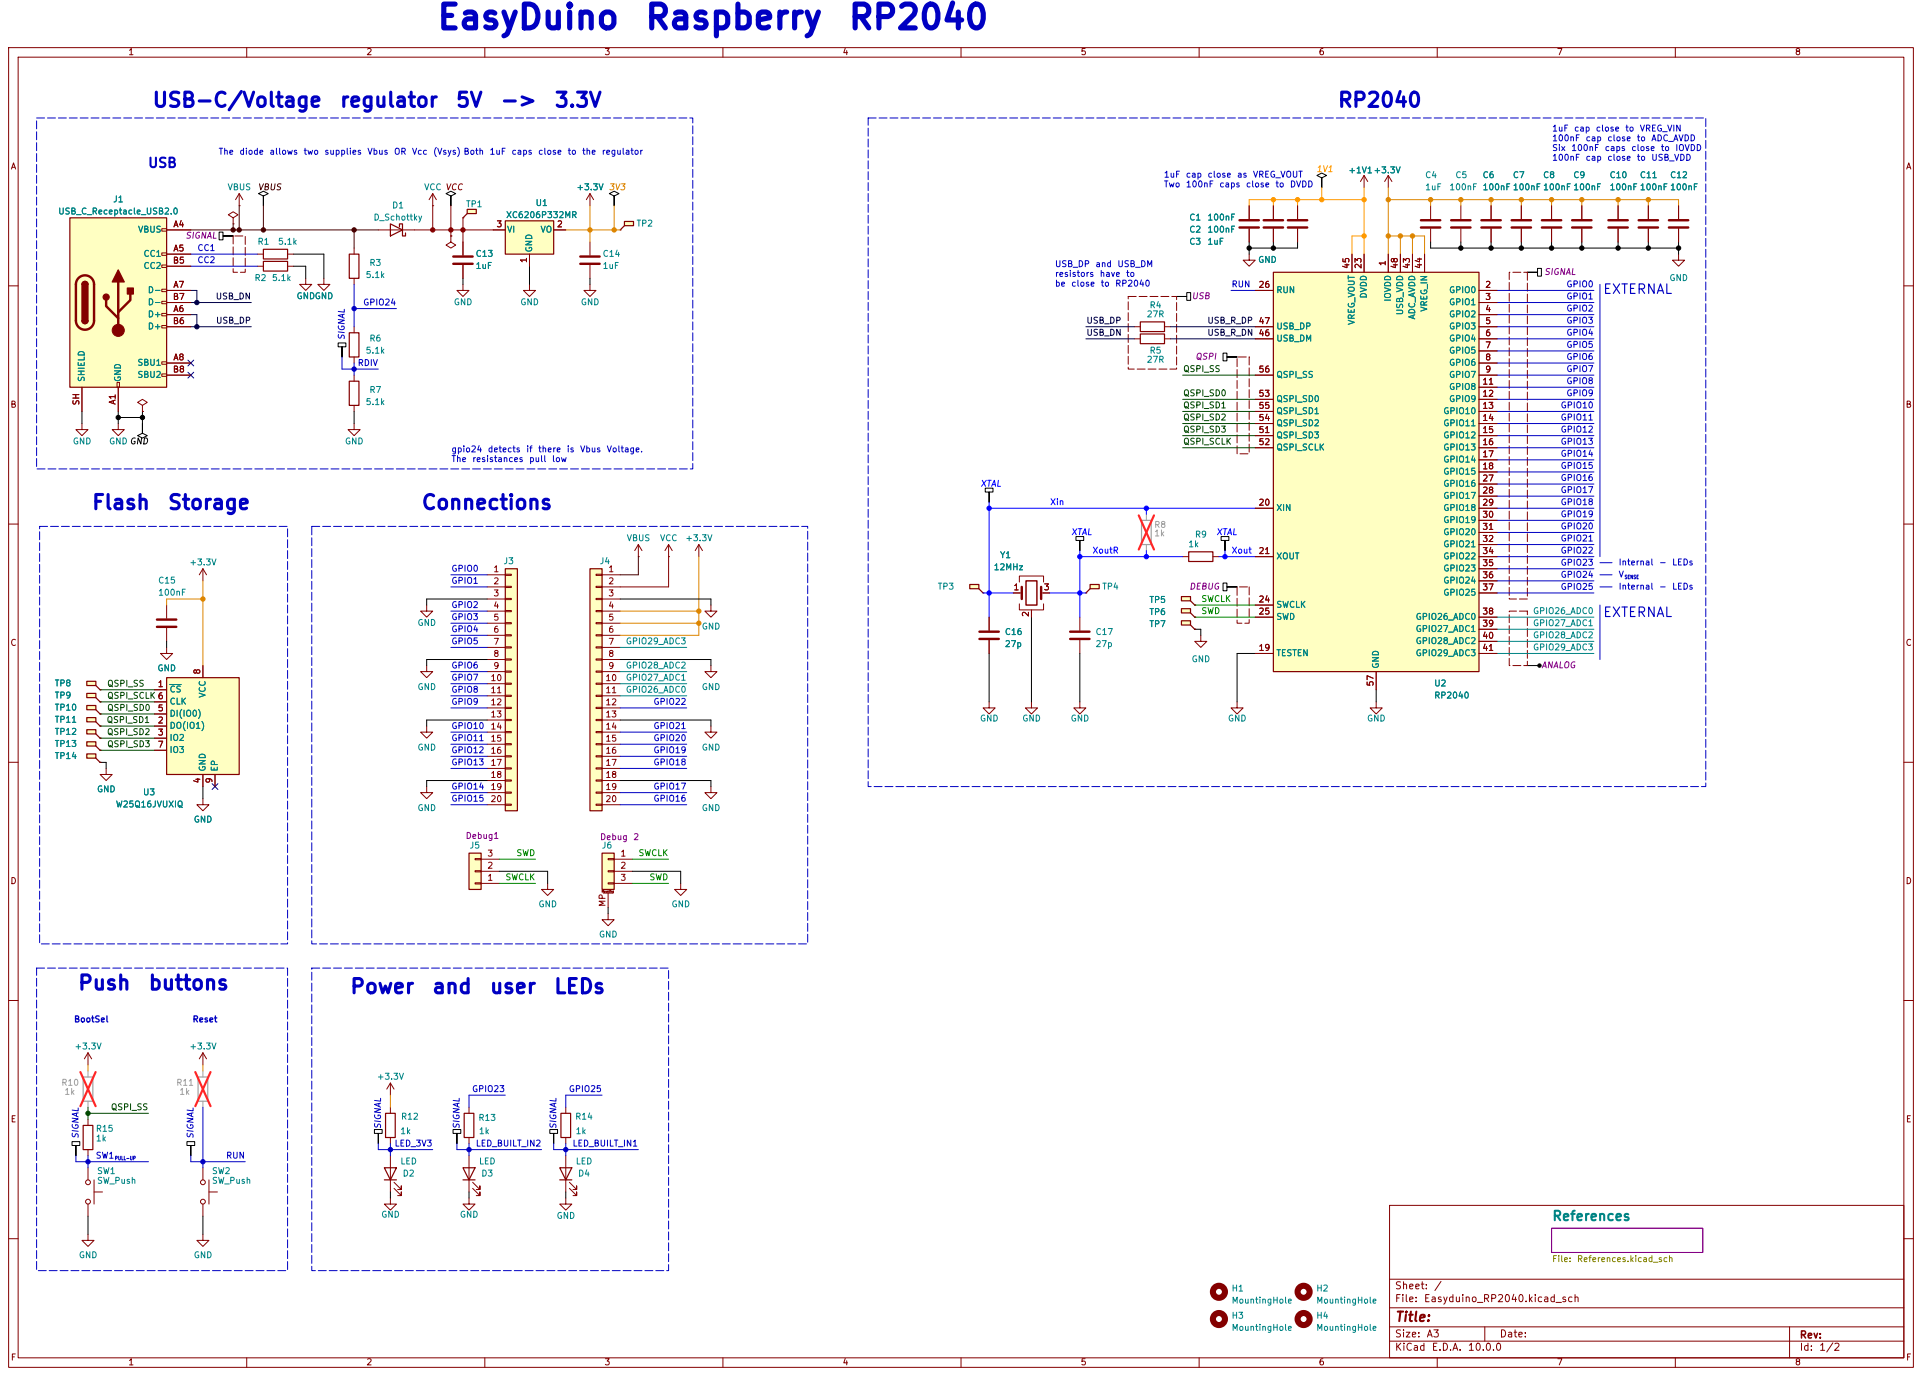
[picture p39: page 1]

1uF cap close to VREG_VIN
100nF cap close to ADC_AVDD
Six 100nF caps close to IOVDD

The diode allows two supplies Vbus OR Vcc (Vsys) Both 1uF caps close to the regulator
5.1k D1 D_Schottky VCC

Two 100nF caps close to DVDD USB_DP and USB_DM

GPIO13 GPIO14 GPIO12 GPIO13 GPIO11 GPIO1 GPIO2 GPIO4 GPIO0 GPIO3 GPIO6 GPIO5
gpio24 detects if there is Vbus Voltage.

The resistances pull low Connections

Internal - LEDs Flash Storage

Power and user LEDs

Size: A3 | Rev: | F Date:
KiCad E.D.A. 10.0.0 | Id: 1/2

1 | 2 | 3 | 4 | 5 | 6
1 | 2 | 3 | 4 | 5 | 6

AB

C

D

AB

C

D Date:

Size: A4 | Rev:
KiCad E.D.A. 10.0.0 | Id: 2/2

## Title:

File: References.kicad_sch

Sheet: /References/

# Differential pair:

RP2040

# Specs:

# USB C

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

# Maximum Output Current at 5V input : 200 mA at 3.3V output No Polarity Protection (External Source) Overcurrent Protection: None

# References:

# XC6206P332MR-3.3V

# Differences with Original Raspberry Pi Pico

# W25Q16JVUXIQ

## W25Q16JVUXIQ Datasheet p6 -> Use a 100nF and 1uF capacitor

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

### XC6206_Torex Datasheet p6 -> Two 1 uF ceramic capacitors on Vin and Vout

GPIO23 is not exposed or used. Since the voltage regulator used (XC6206...) doesn't have a Power Select mode
GPIO29_ADC which is used for monitoring VSys (external battery) is not exposed or used in order to save costs
In the Raspberry Pi Pico Schematic, 2uF capacitors are used for decoupling. I use 1uF decoupling capacitors as indicated in the rp2040 datasheet ADC_AVDD is powered only by 3.3V, no option for external Analog powering. This will be more noisy for projects where ADC is used.
ADC_AVDD But in order to save space and cost. I will skip the option to power it externally

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

### I have to use 9 mil tracks -> 0.2mm. With a ground layer below

I have to place vias because of the pinout of USB C. Some other people have placed vias without problems for signal integrity

## RPI Pico Schematic

### Hardware design with rp2040 p10 -> 12MHz crystal with 27 pF Capacitors

## rp2040 datasheet p13 -> USB_DP and USB_DM need 27 Ohm Resistors

### rp2040 datasheet p13 -> Use a 12MHz Crystal

## rp2040 datasheet p13 -> TESTEN to GND

### rp2040 datasheet p155 -> USB_VDD connected to 3.3V and decoupled with a 100 nF capacitor

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

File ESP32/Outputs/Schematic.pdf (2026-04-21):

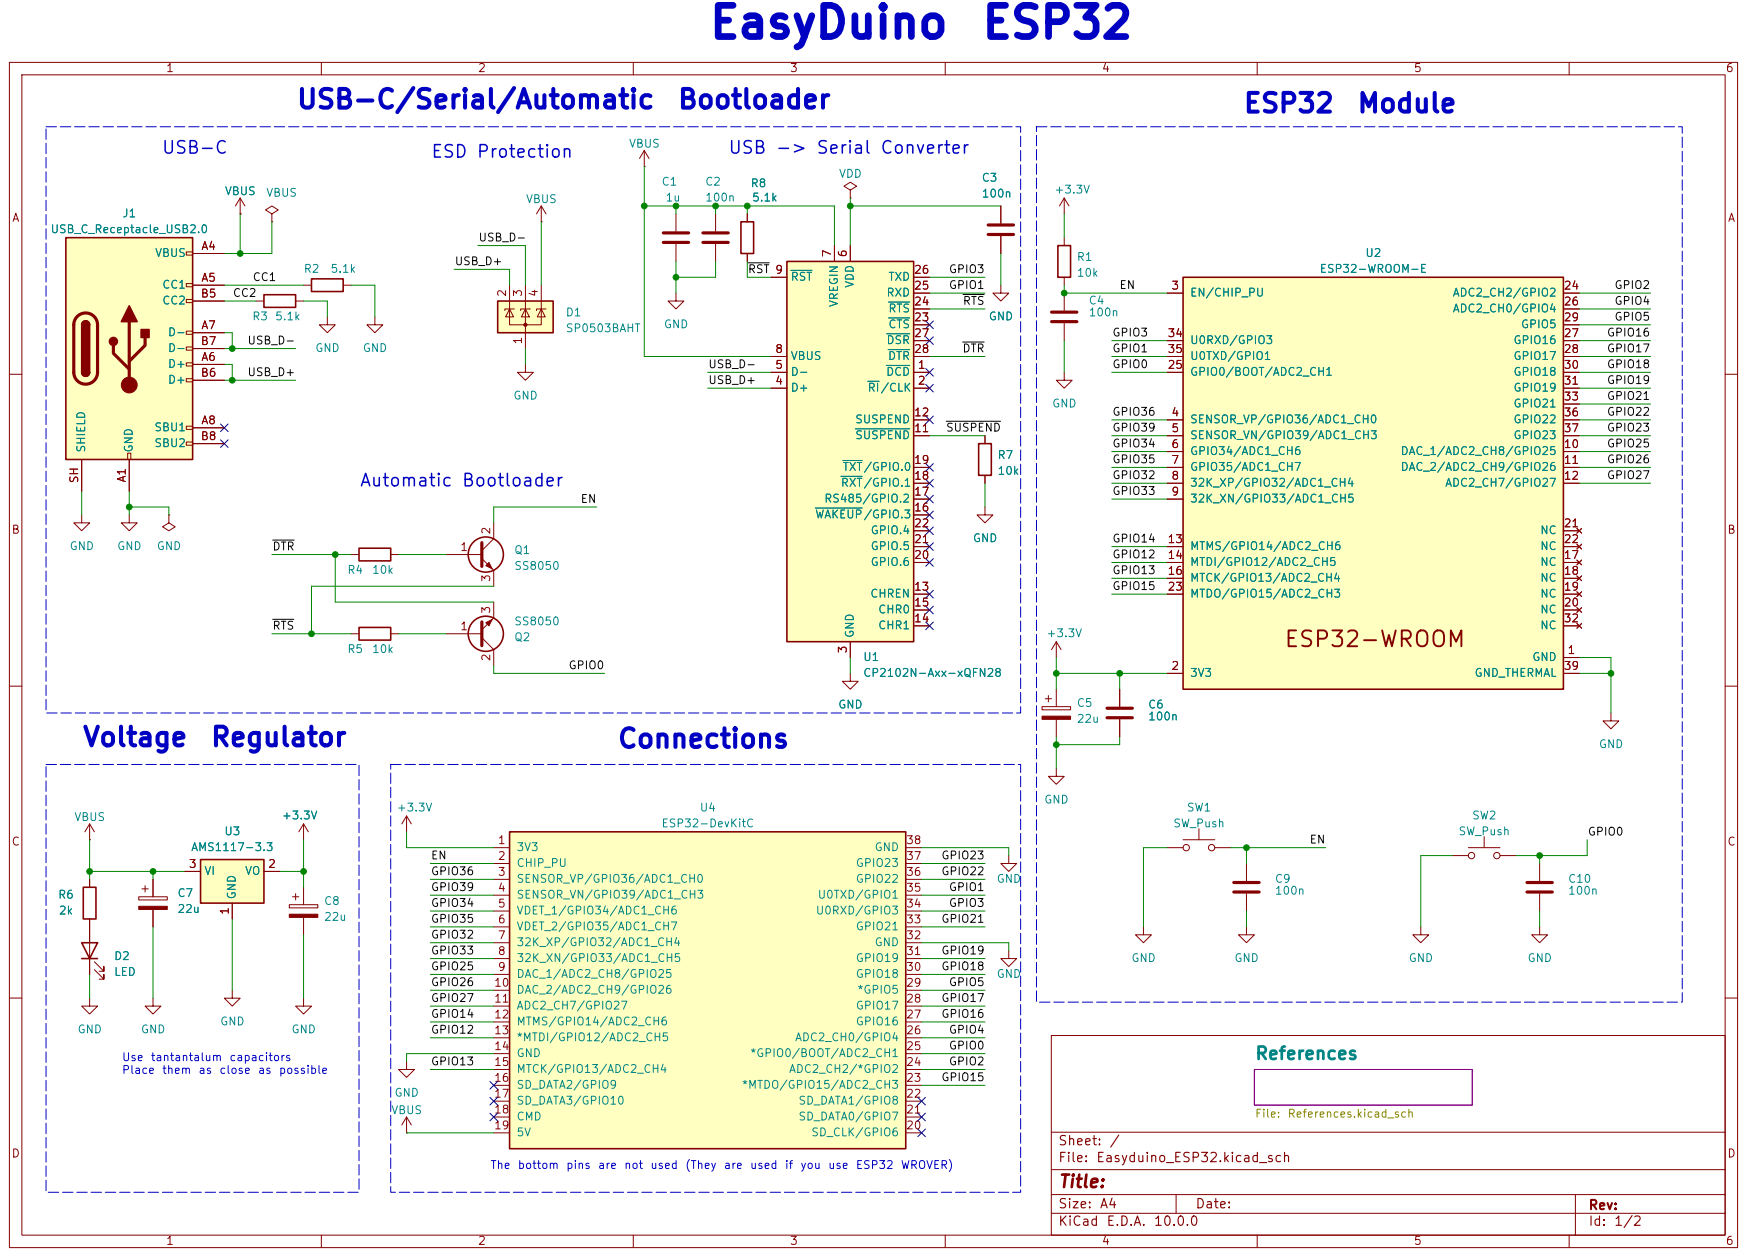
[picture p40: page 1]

USB-C/Serial/Automatic Bootloader

Place them as close as possible

The bottom pins are not used (They are used if you use ESP32 WROVER)

Size: A4 | Rev:
KiCad E.D.A. 10.0.0 | Id: 1/2

1 | 2 | 3 | 4 | 5 | 6
1 | 2 | 3 | 4 | 5 | 6

AB

C

D

AB

C

### D Date:

Size: A4 | Rev:
KiCad E.D.A. 10.0.0 | Id: 2/2

## Title:

### File: References.kicad_sch

### Sheet: /References/

CP2102

# AMS1117-3.3V

# USB C

# Differential pair:

## ESP32 Wroom 32 E datasheet p24 -> 3.3V pin needs one 22uF and one 100nF capacitors

## ESP32 Devkit sch -> EN pin 10k resistor and 100nF capacitor

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

ESP32 Devkit sch -> Automatic Bootloader.

## AMS1117 Datasheet p1 -> 3.3V/1A Output with 5-15V Input

AMS1117 Datasheet p4 -> 22uF tantalum capacitor on input and output.

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

## I have to use 9 mil tracks -> 0.2mm. With a ground layer below

For USBC I will use a very short trace for D+ D- (around 2mm, very short, lower than critical length)
The Development board from ESP32 has no problem with these tracks despite being a 2 board layer and USB Data tracks too thin
I have to place vias because of the pinout of USB C and CP2102. Some other people have placed vias without problems for signal integrity

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

CP2102 datasheet p15 -> VBUS will be tied to REGIN. 1uF and 100 nF will be added.

## CP2102 datasheet p15 -> ESD Supression Diode for all three inputs of USB

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

# ESP32 WROOM 32E

# References:

# Decoupling capacitors:

# Enable pin (EN):

# Thermal pad:

# Automatic Bootloader:

# Filtering:

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

# Output Current at 3.3V : 1 A (External Source) 500mA (USB) No Polarity Protection (External Source) Overcurrent Protection: None

# Specs:

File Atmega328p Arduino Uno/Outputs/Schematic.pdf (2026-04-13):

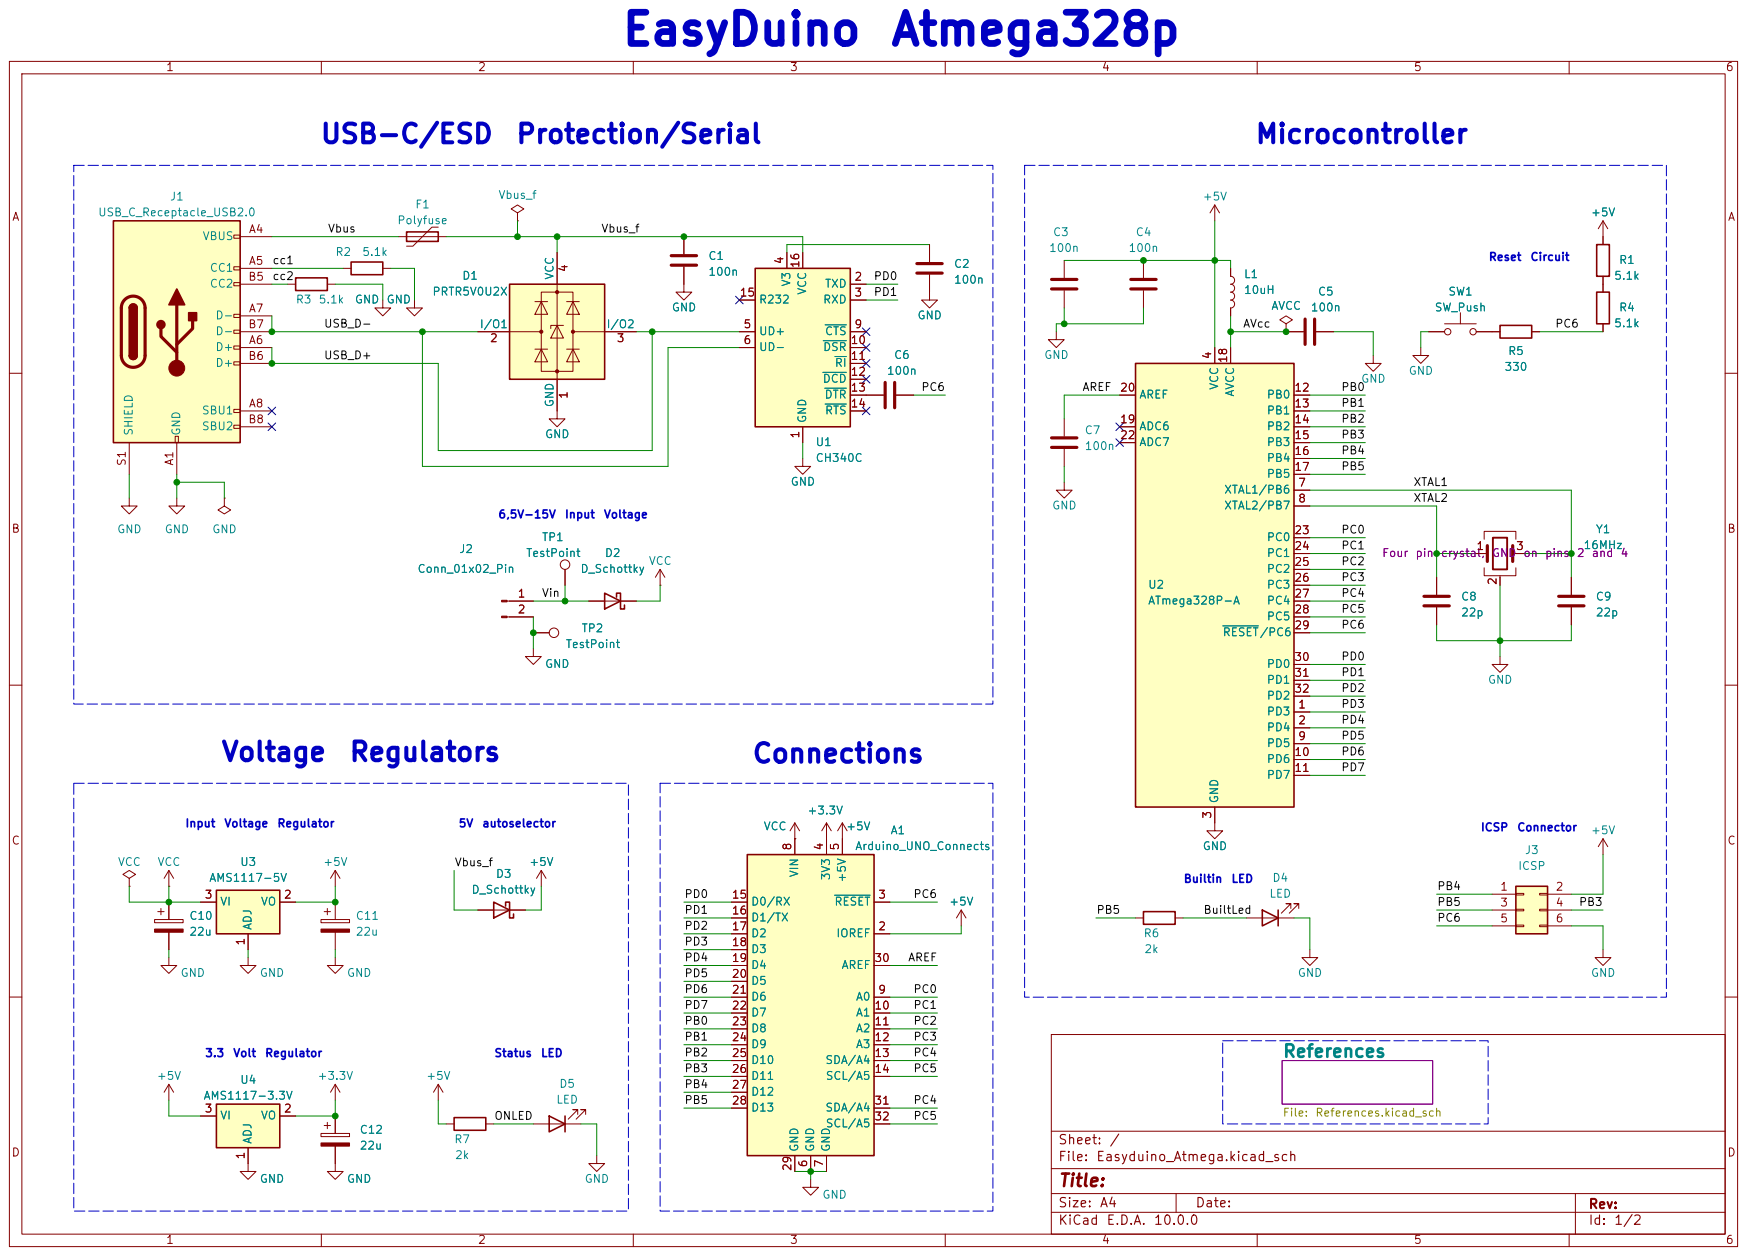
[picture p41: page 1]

USB-C/ESD Protection/Serial

Reset Circuit 6,5V-15V Input Voltage

4 UD+ 5 UD- 6 CTS 9 DSR 10 RI 11 DCD 12 DTR 13 RTS 14 R232 15 VCC 16 U1CH340C

4 UD+ 5 UD- 6 CTS 9 DSR 10 RI 11 DCD 12 DTR 13 RTS 14 R232 15 VCC 16 C6

Size: A4 | Rev:
KiCad E.D.A. 10.0.0 | Id: 1/2

1 | 2 | 3 | 4 | 5 | 6
1 | 2 | 3 | 4 | 5 | 6

AB

C

D

AB

C

D Date:

Size: A4 | Rev:
KiCad E.D.A. 10.0.0 | Id: 2/2

## Title:

File: References.kicad_sch

Sheet: /References/

# Specs:

# Atmega328p

# References:

# Reset:

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

External Input Polarity protection: A diode will protect the circuit from a wrongly inserted battery.

### Atmega328 Reference Manual p213 -> 10uH ferrite bead and 100nF The Analog tracks aren't critical. I won't create an analog ground for these tracks

### Atmega Hardware Design Considerations p12

# Differential pair:

### Atmega Hardware Design Considerations p6 -> 100nF

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

### Atmega Hardware Design Considerations p16, p19 -> 22pf for 16 MHz

# Filtering:

# ICSP Connector:

# AVCC:

# Crystal:

# USB C

# AREF:

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

### I have to use 9 mil tracks -> 0.2 mm I will use a very short trace for D+ D- (around 2mm)

# CH340C

# AMS1117

### If USB is present and no external input voltage. The USB will power the ATMEGA

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

USB Hardware Design Guidelines for FTDI ICs p8 -> 10nF Cap + Ferrite Bead + 100nF Cap + 4.7uF Cap
I disregarded such heavy filtering for the easier to implement 100nF cap given by the CH340 datasheet

## I added a polyfuse with I hold 500mA and Itrip 1A

# 5V autoselector

Ch340 Datasheet: p10 -> 100nF between GND and V3.

## Ch340 Datasheet: p10 -> 100nF between GND and Vcc. Vcc to Vusb

### AMS1117 p4 -> 22uF tantalum capacitor on output

LMS1117 p16-> 10uF tantalum capacitor the input. I will use a 22uF to reuse the same capacitor
I will reuse the output capacitor of AMS1117-5V to be the output capacitor of AMS1117-3.3V

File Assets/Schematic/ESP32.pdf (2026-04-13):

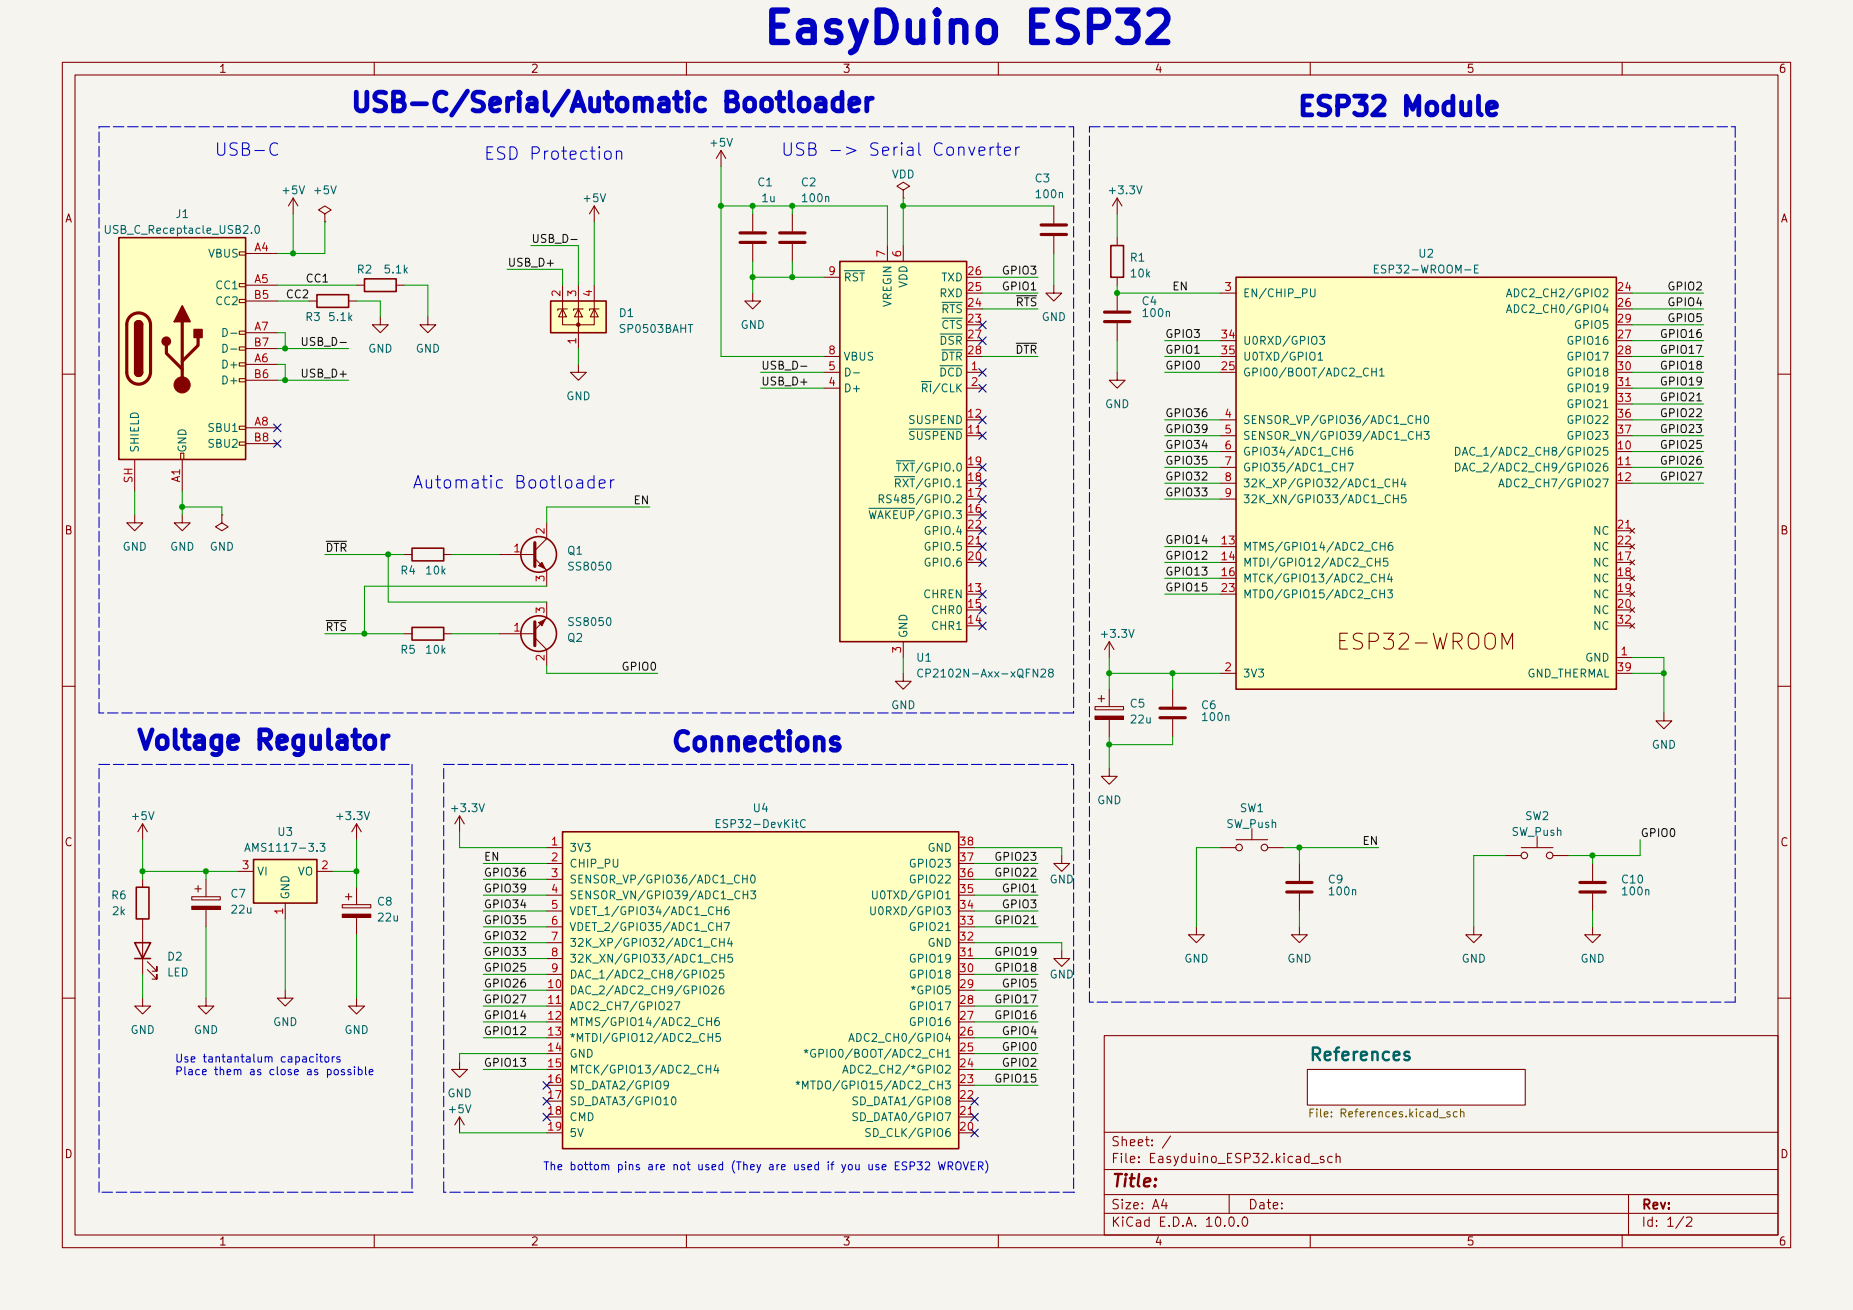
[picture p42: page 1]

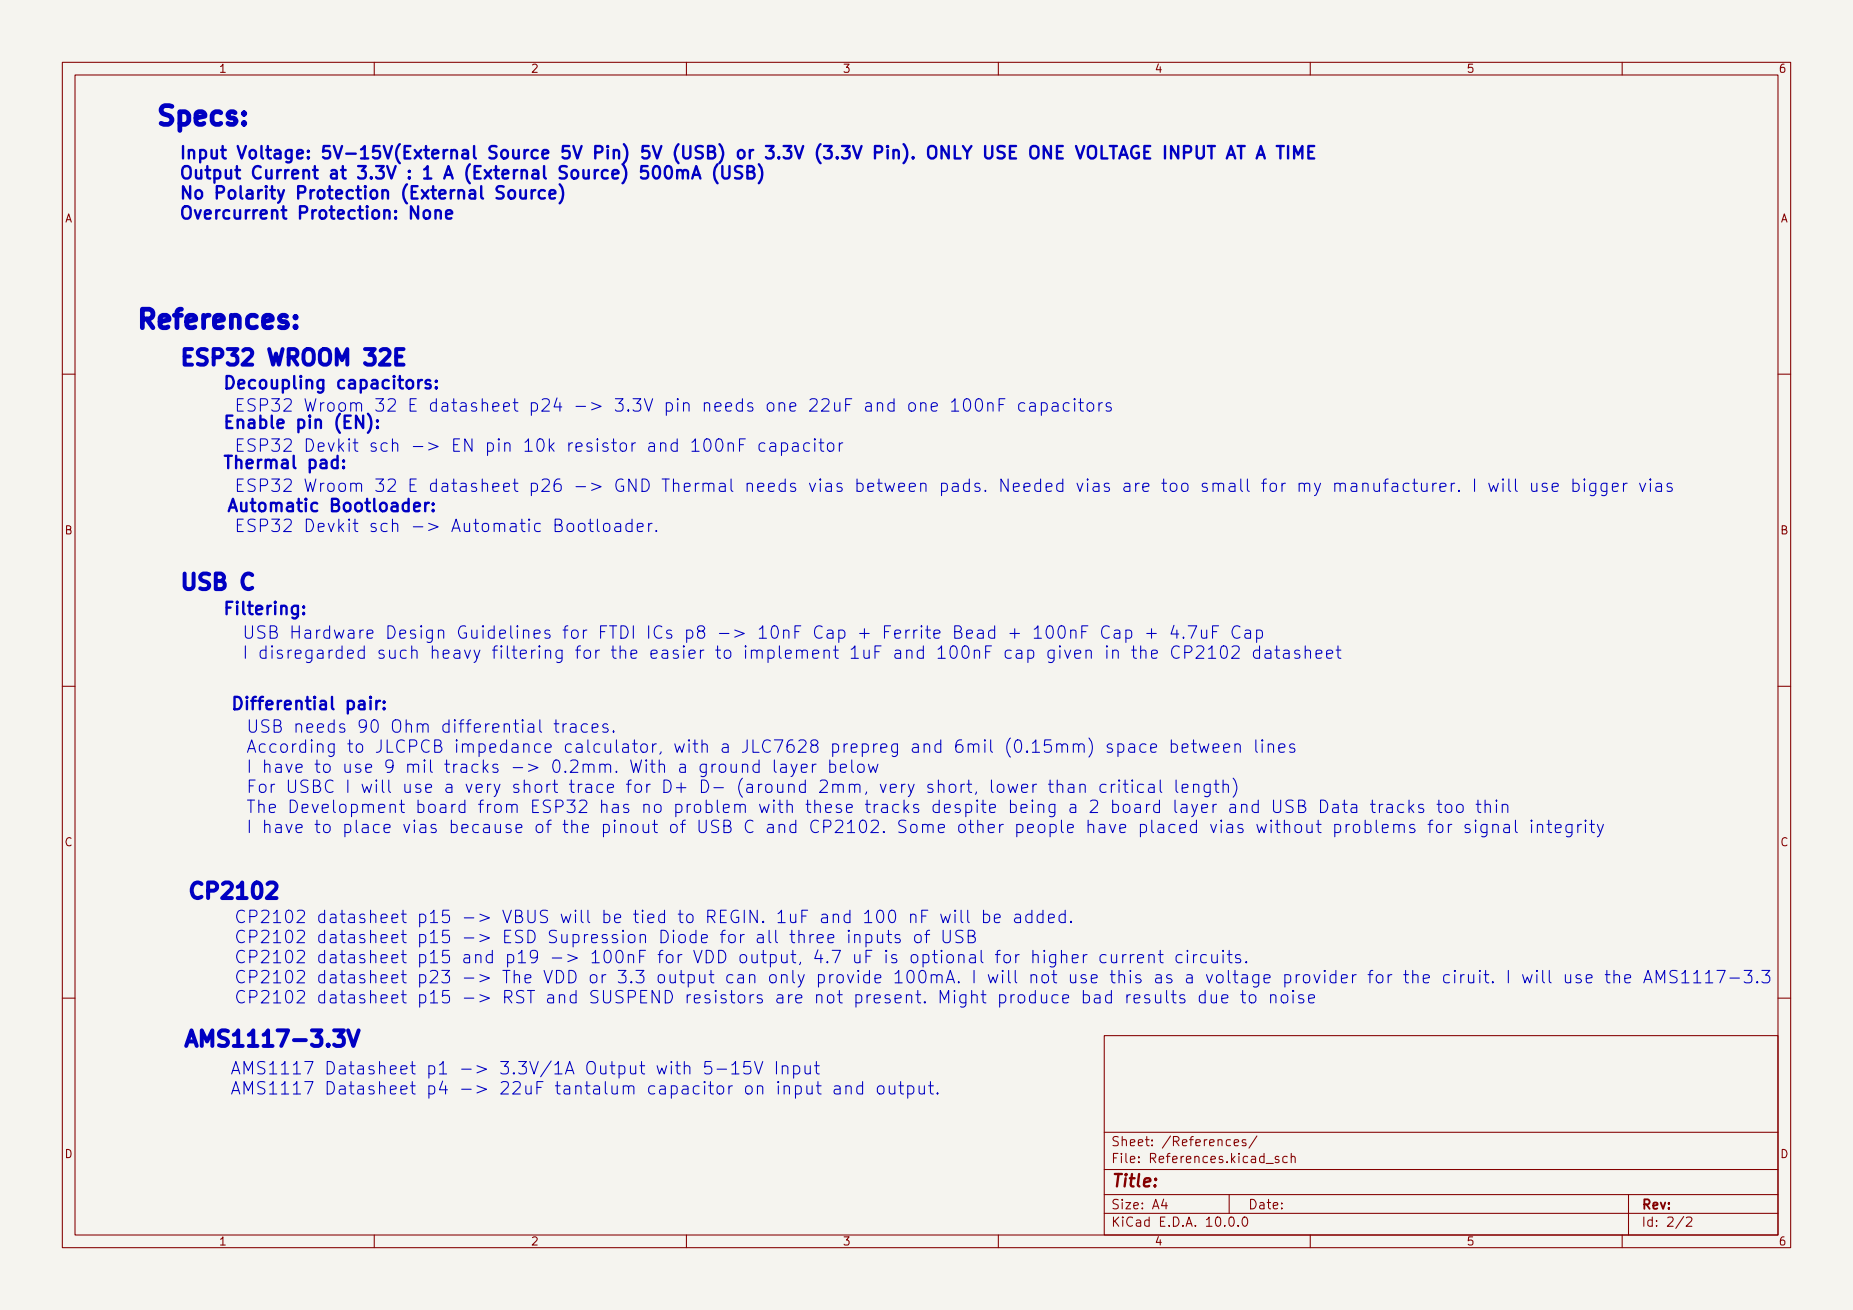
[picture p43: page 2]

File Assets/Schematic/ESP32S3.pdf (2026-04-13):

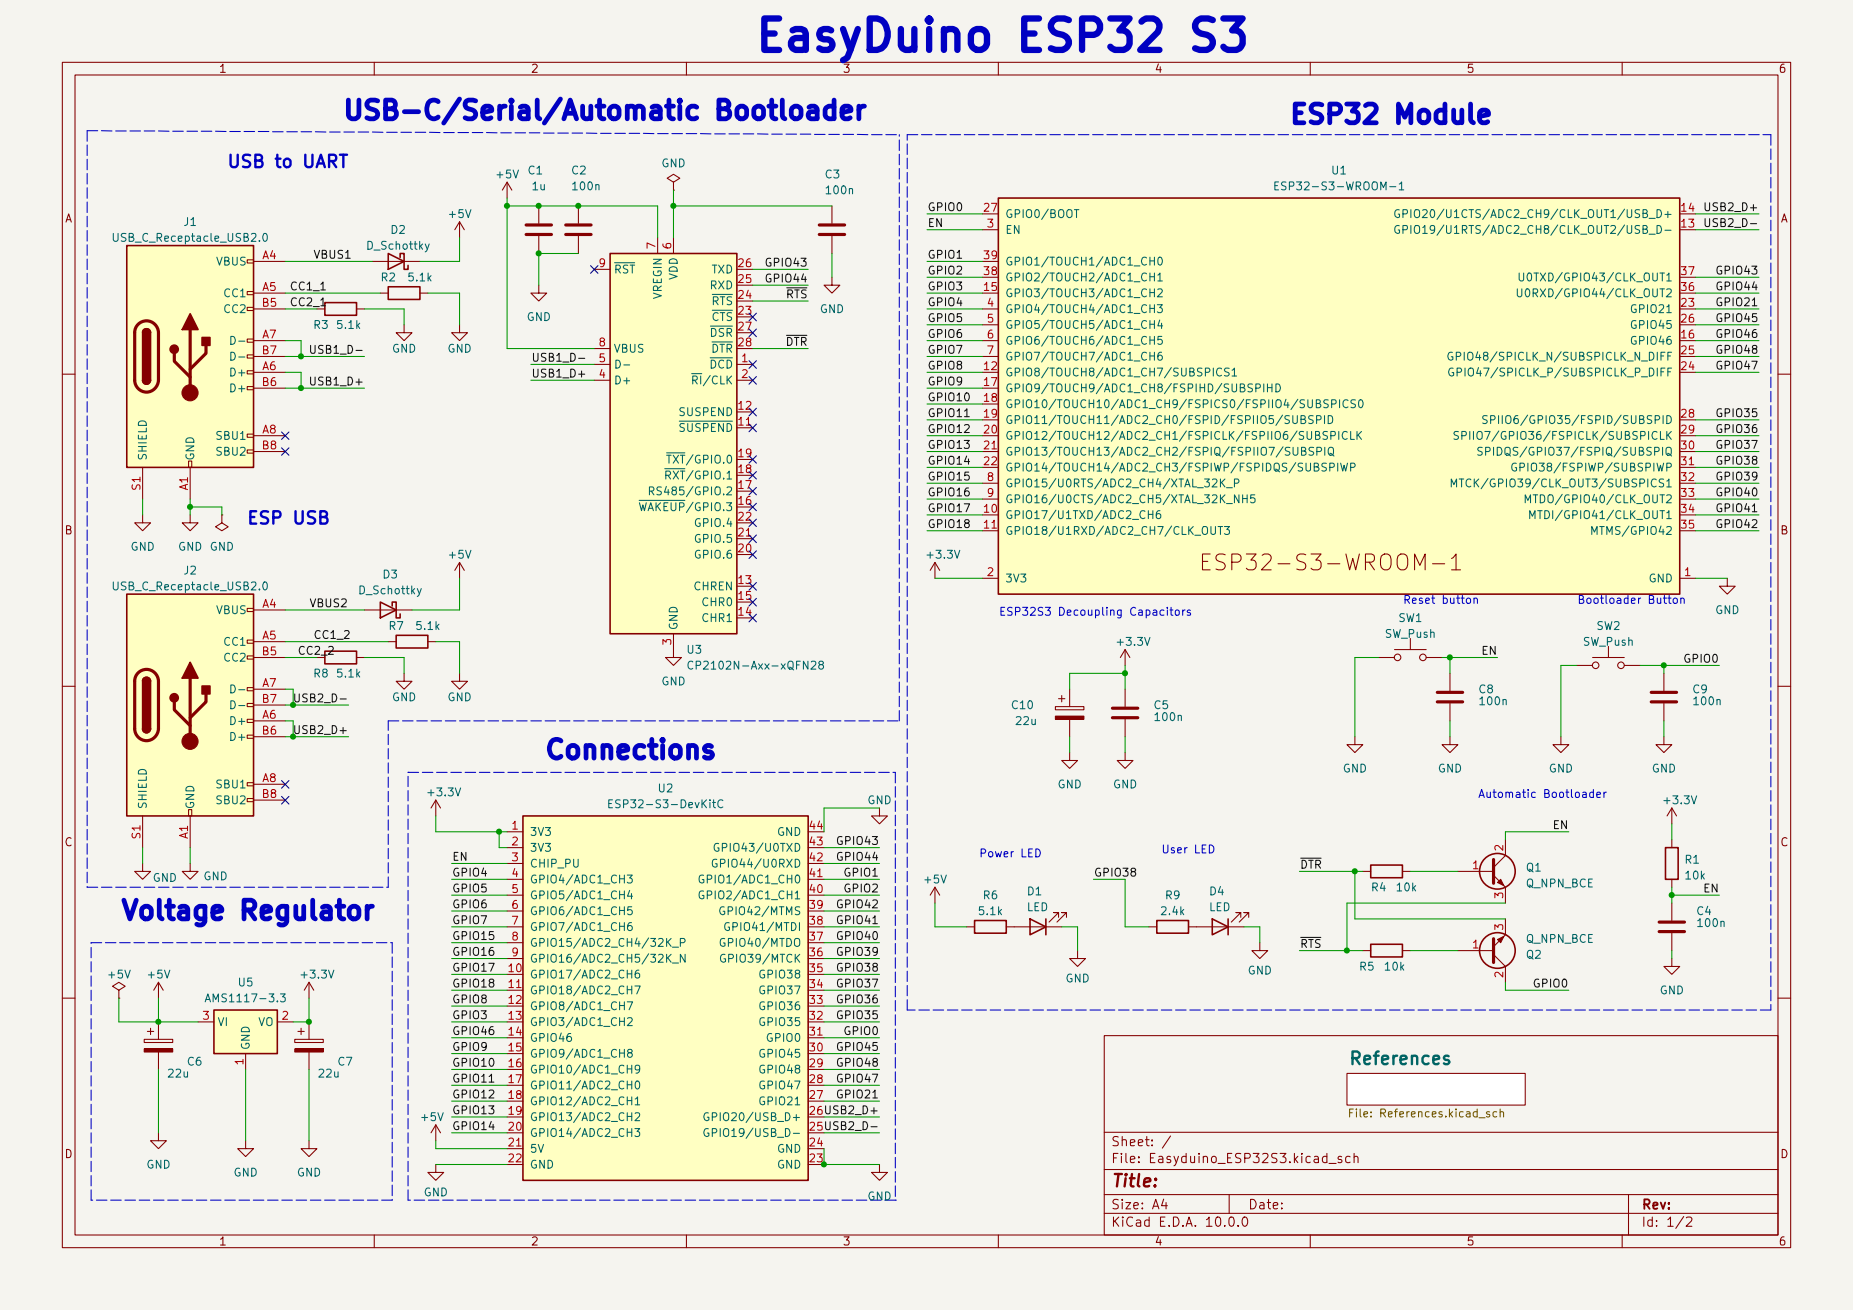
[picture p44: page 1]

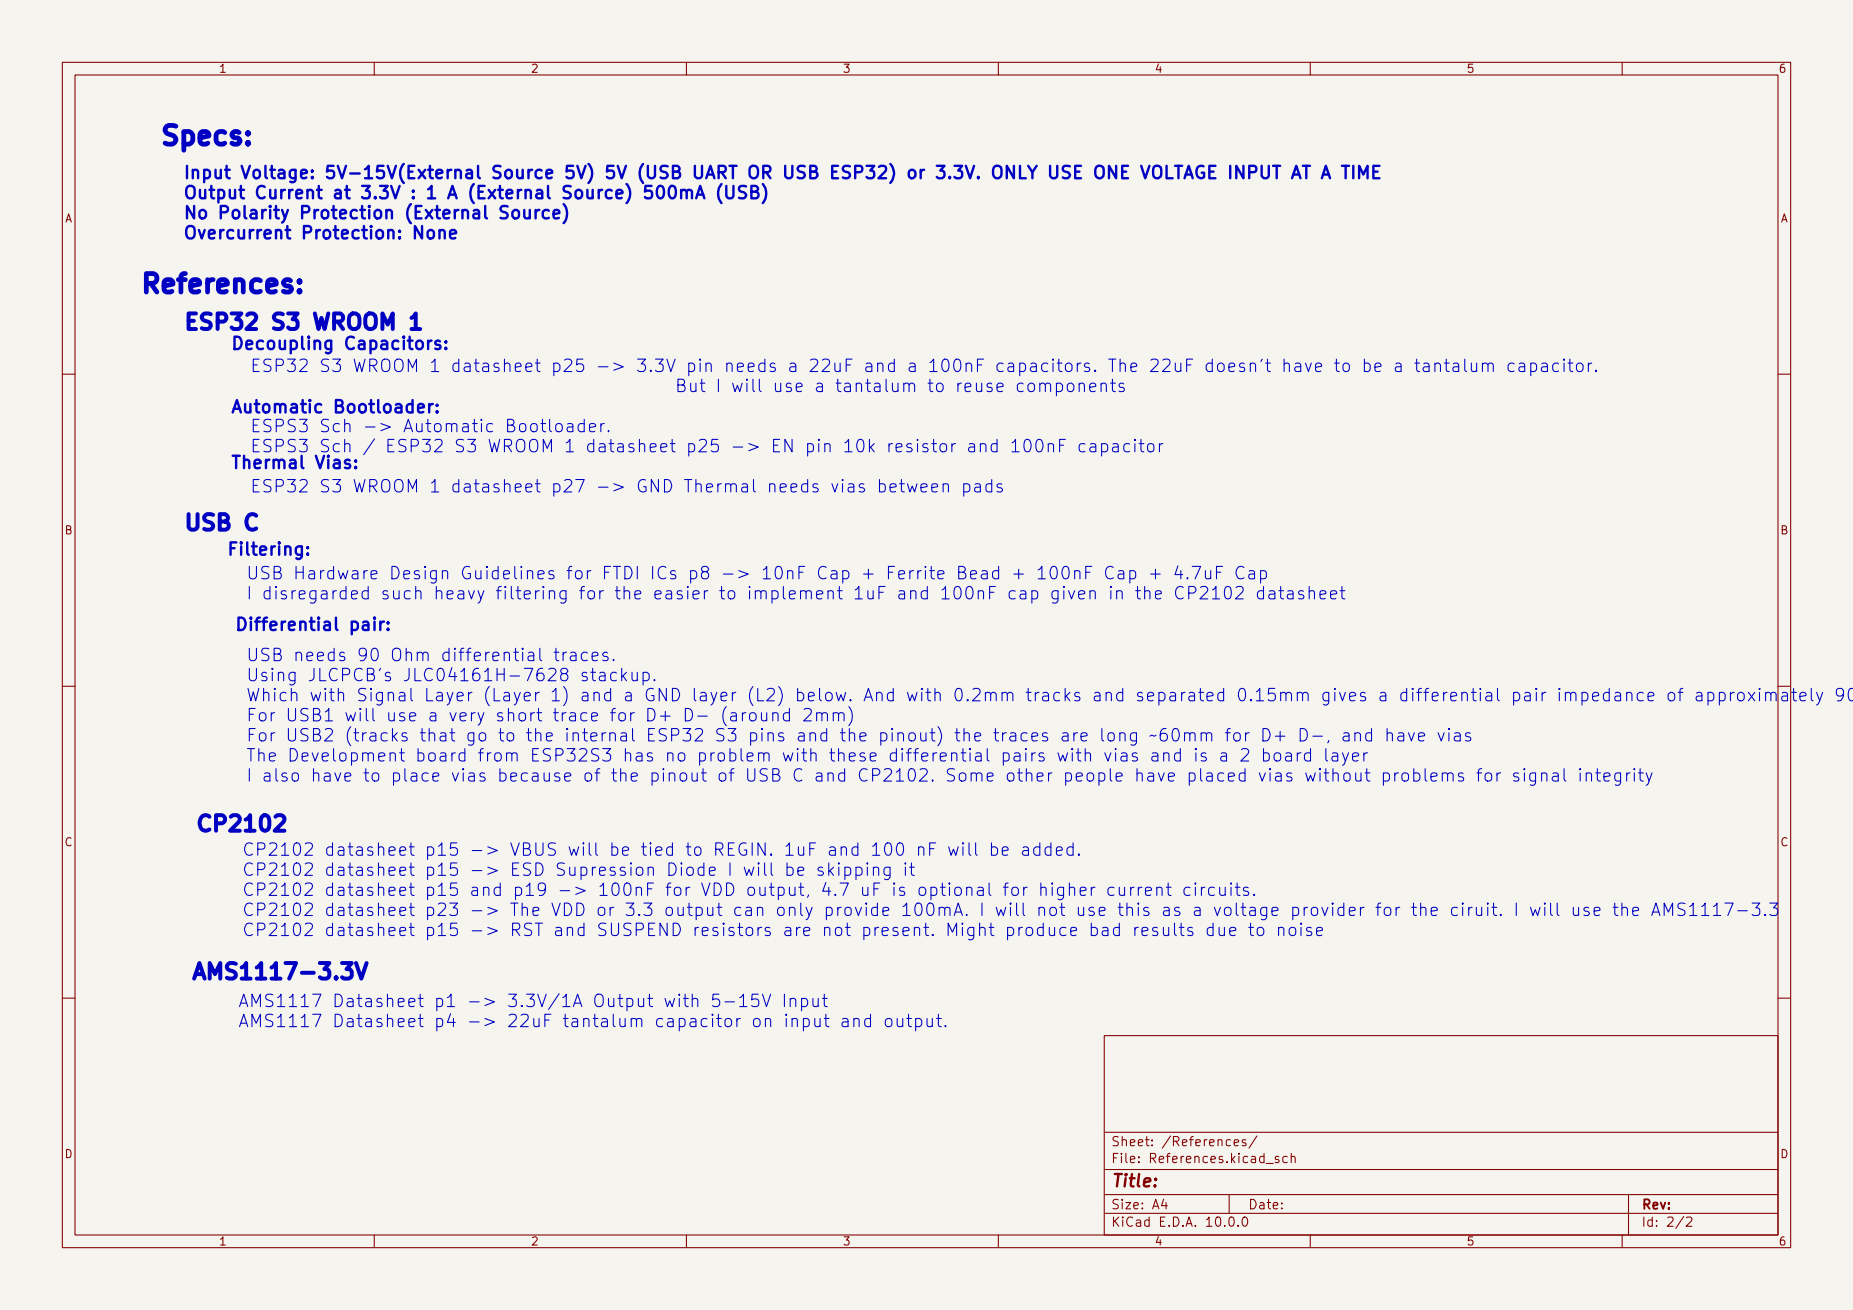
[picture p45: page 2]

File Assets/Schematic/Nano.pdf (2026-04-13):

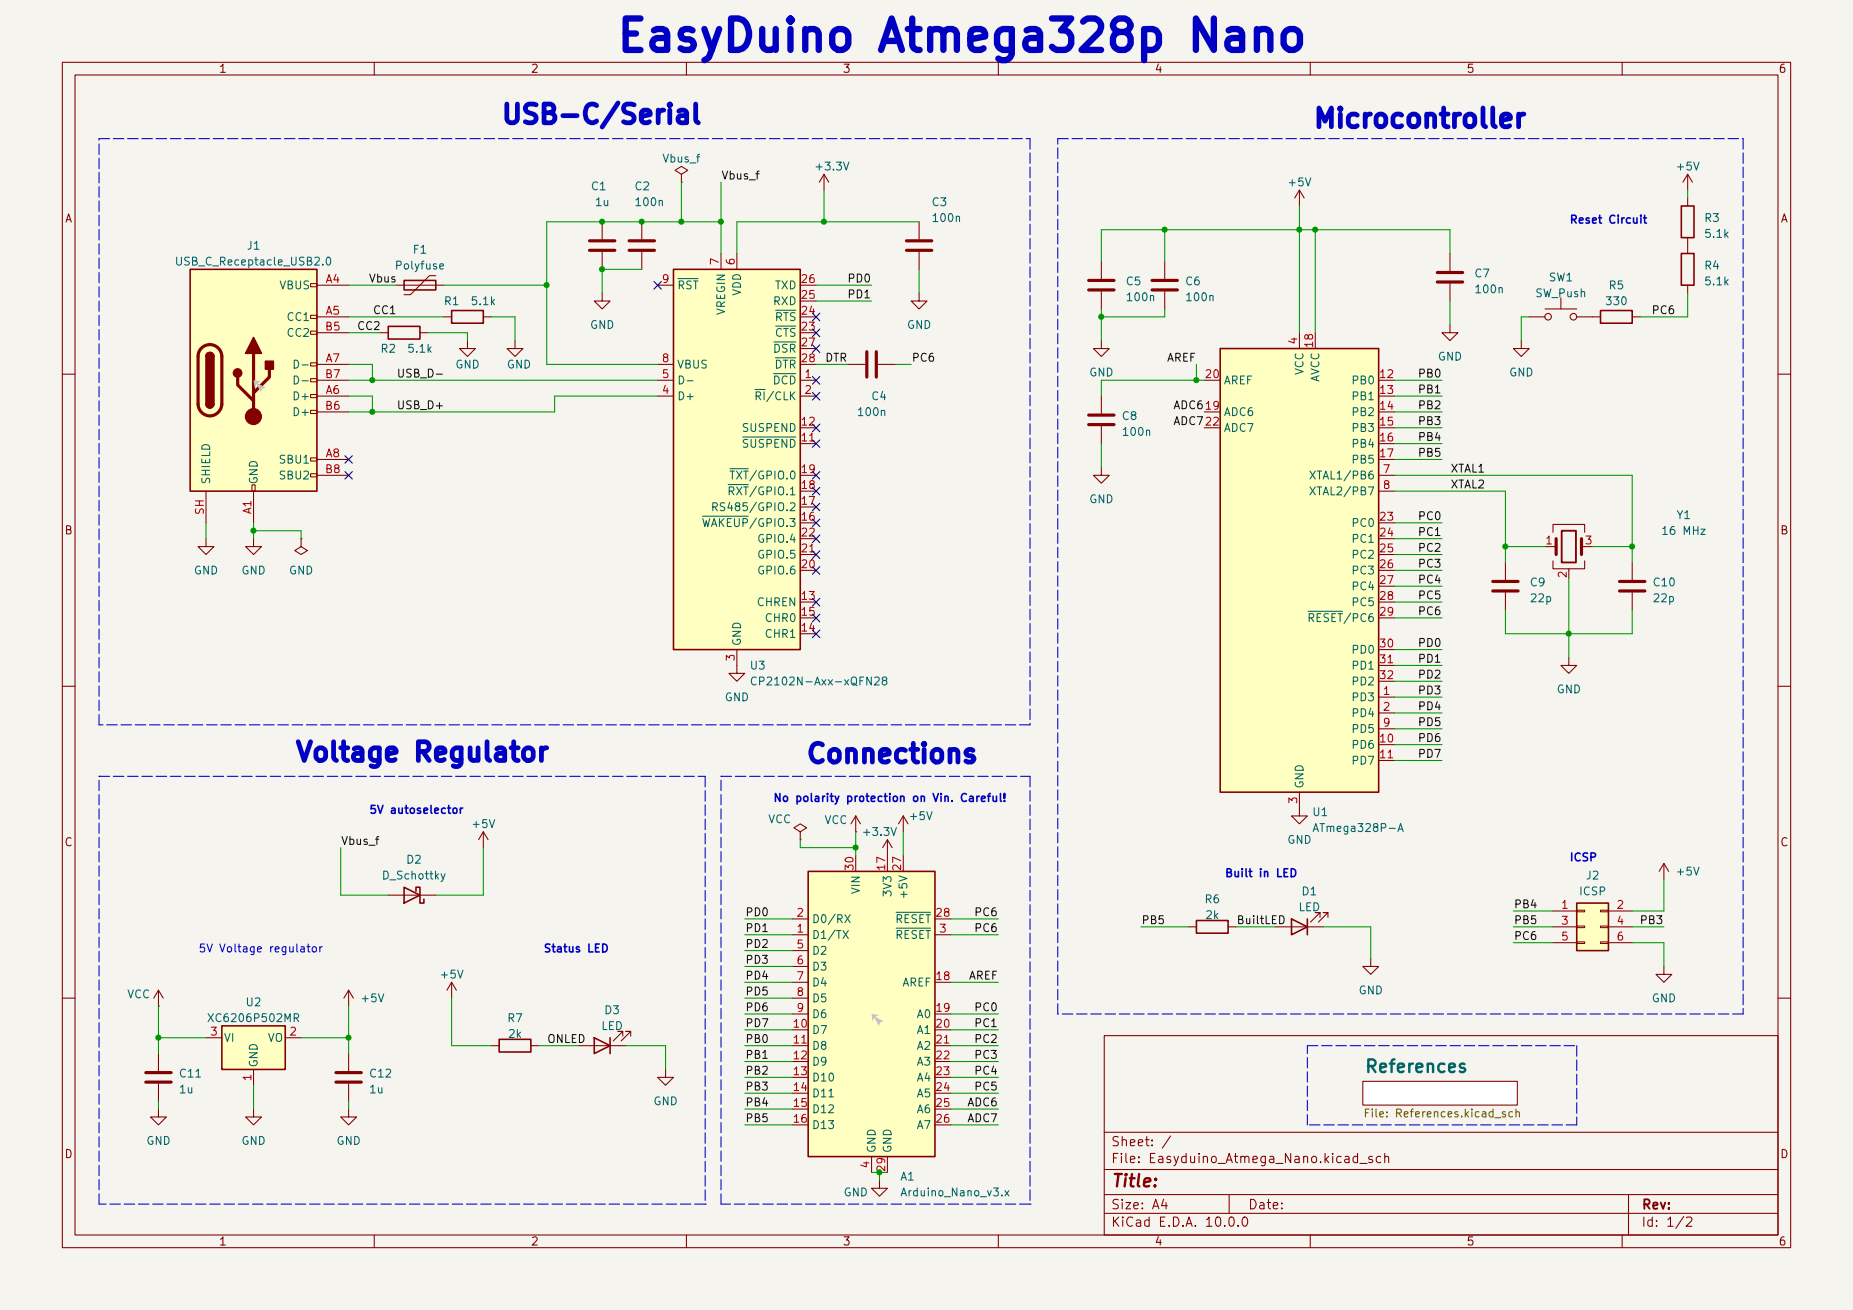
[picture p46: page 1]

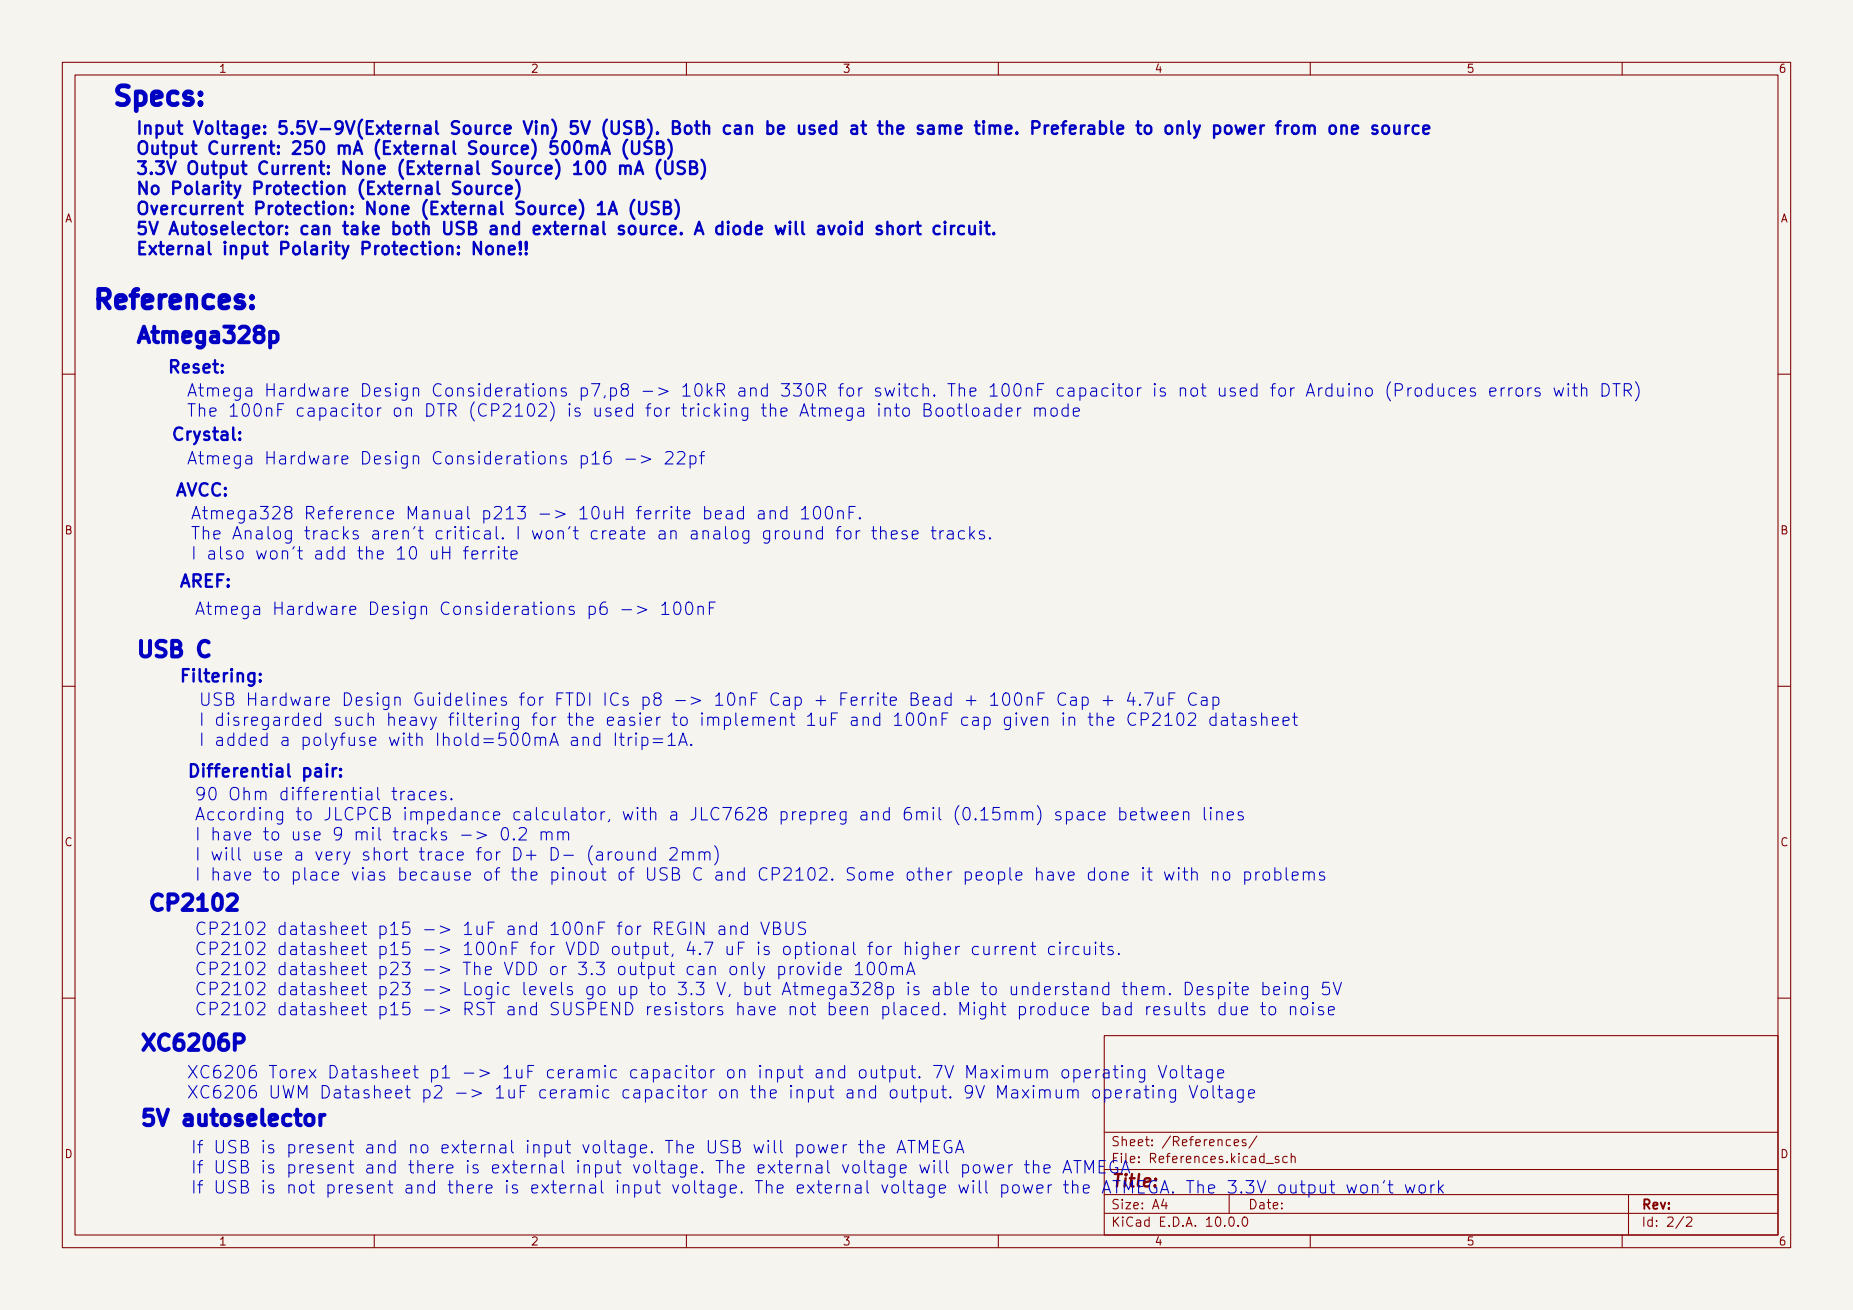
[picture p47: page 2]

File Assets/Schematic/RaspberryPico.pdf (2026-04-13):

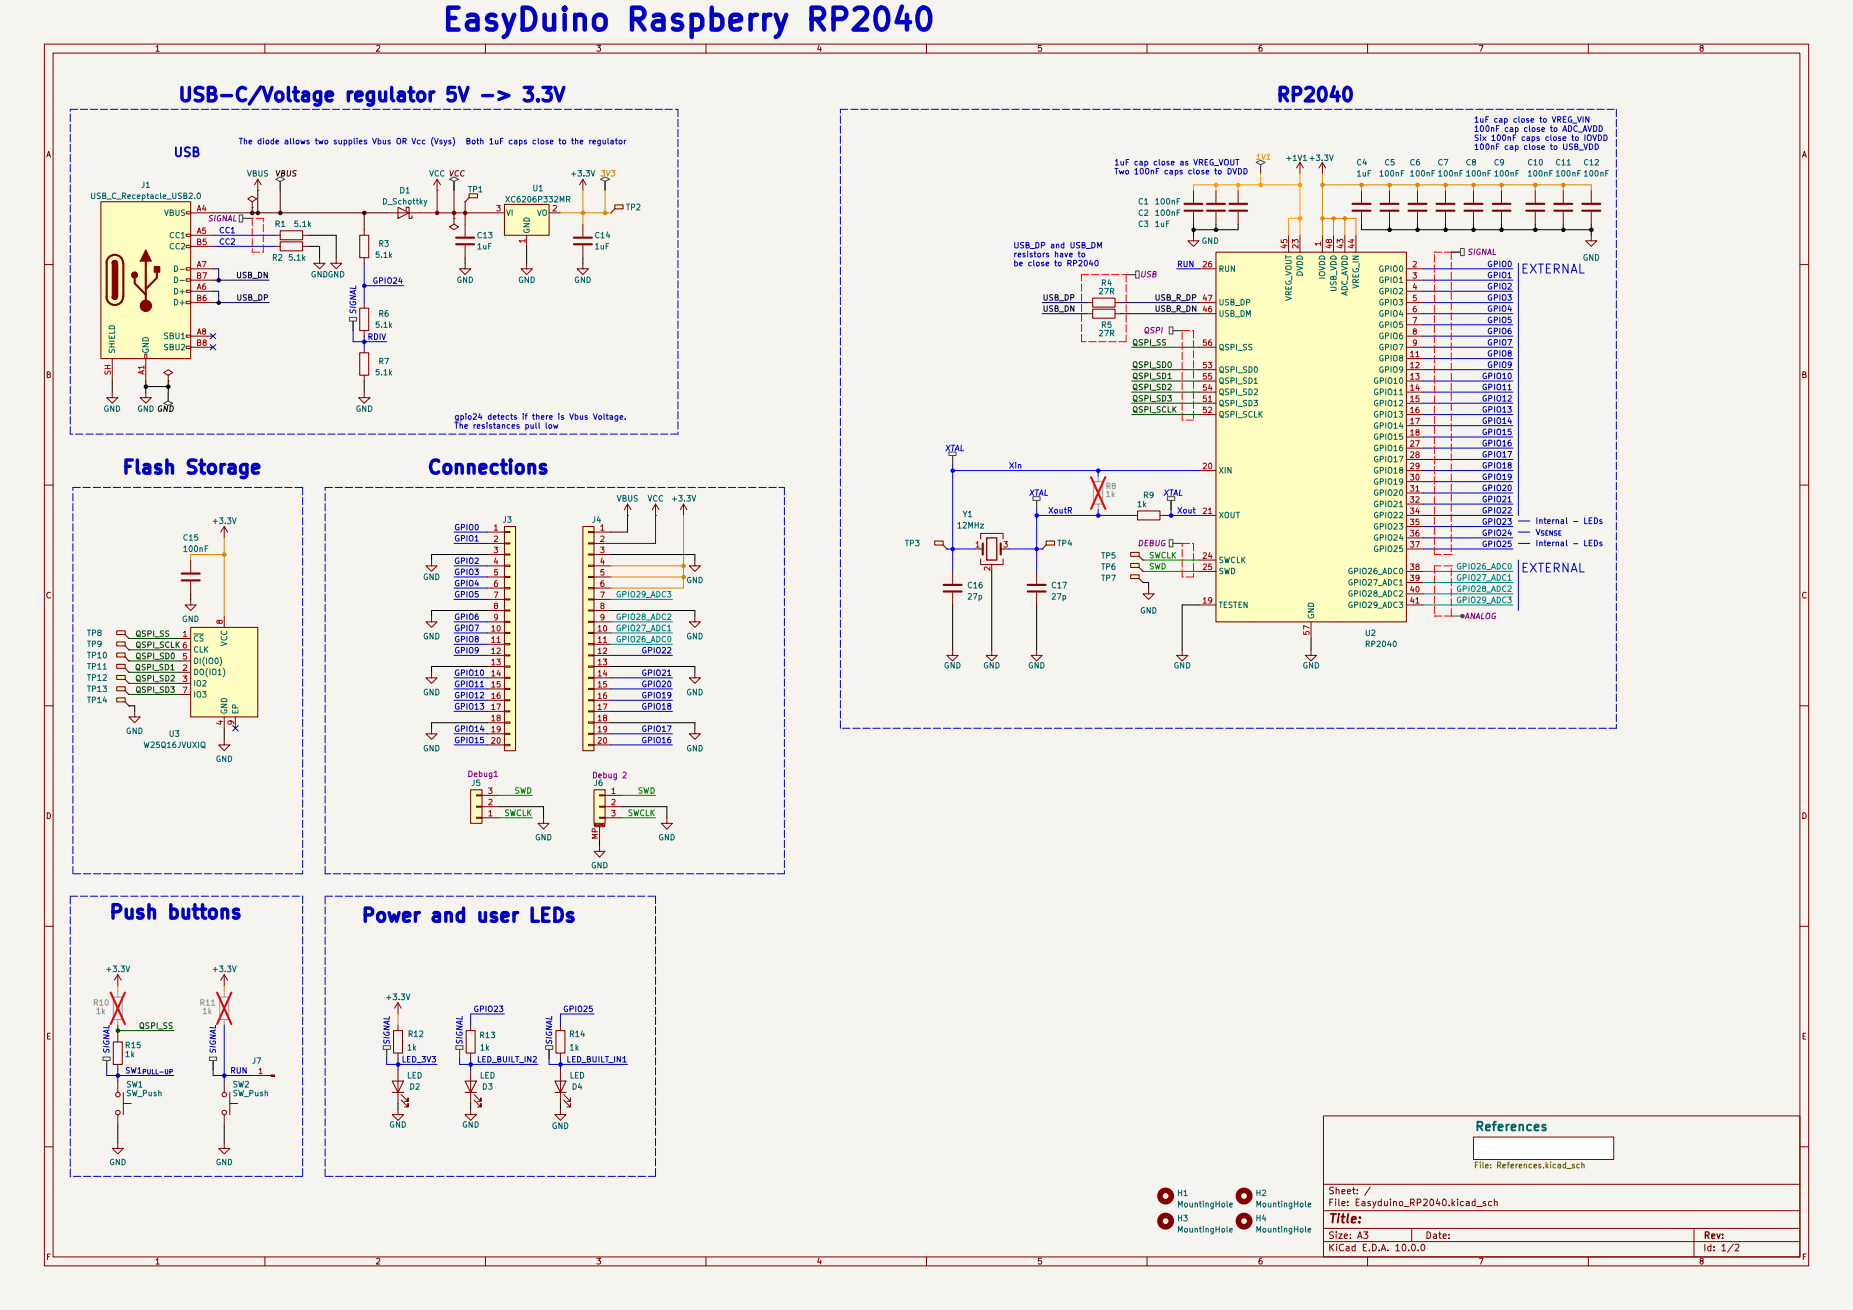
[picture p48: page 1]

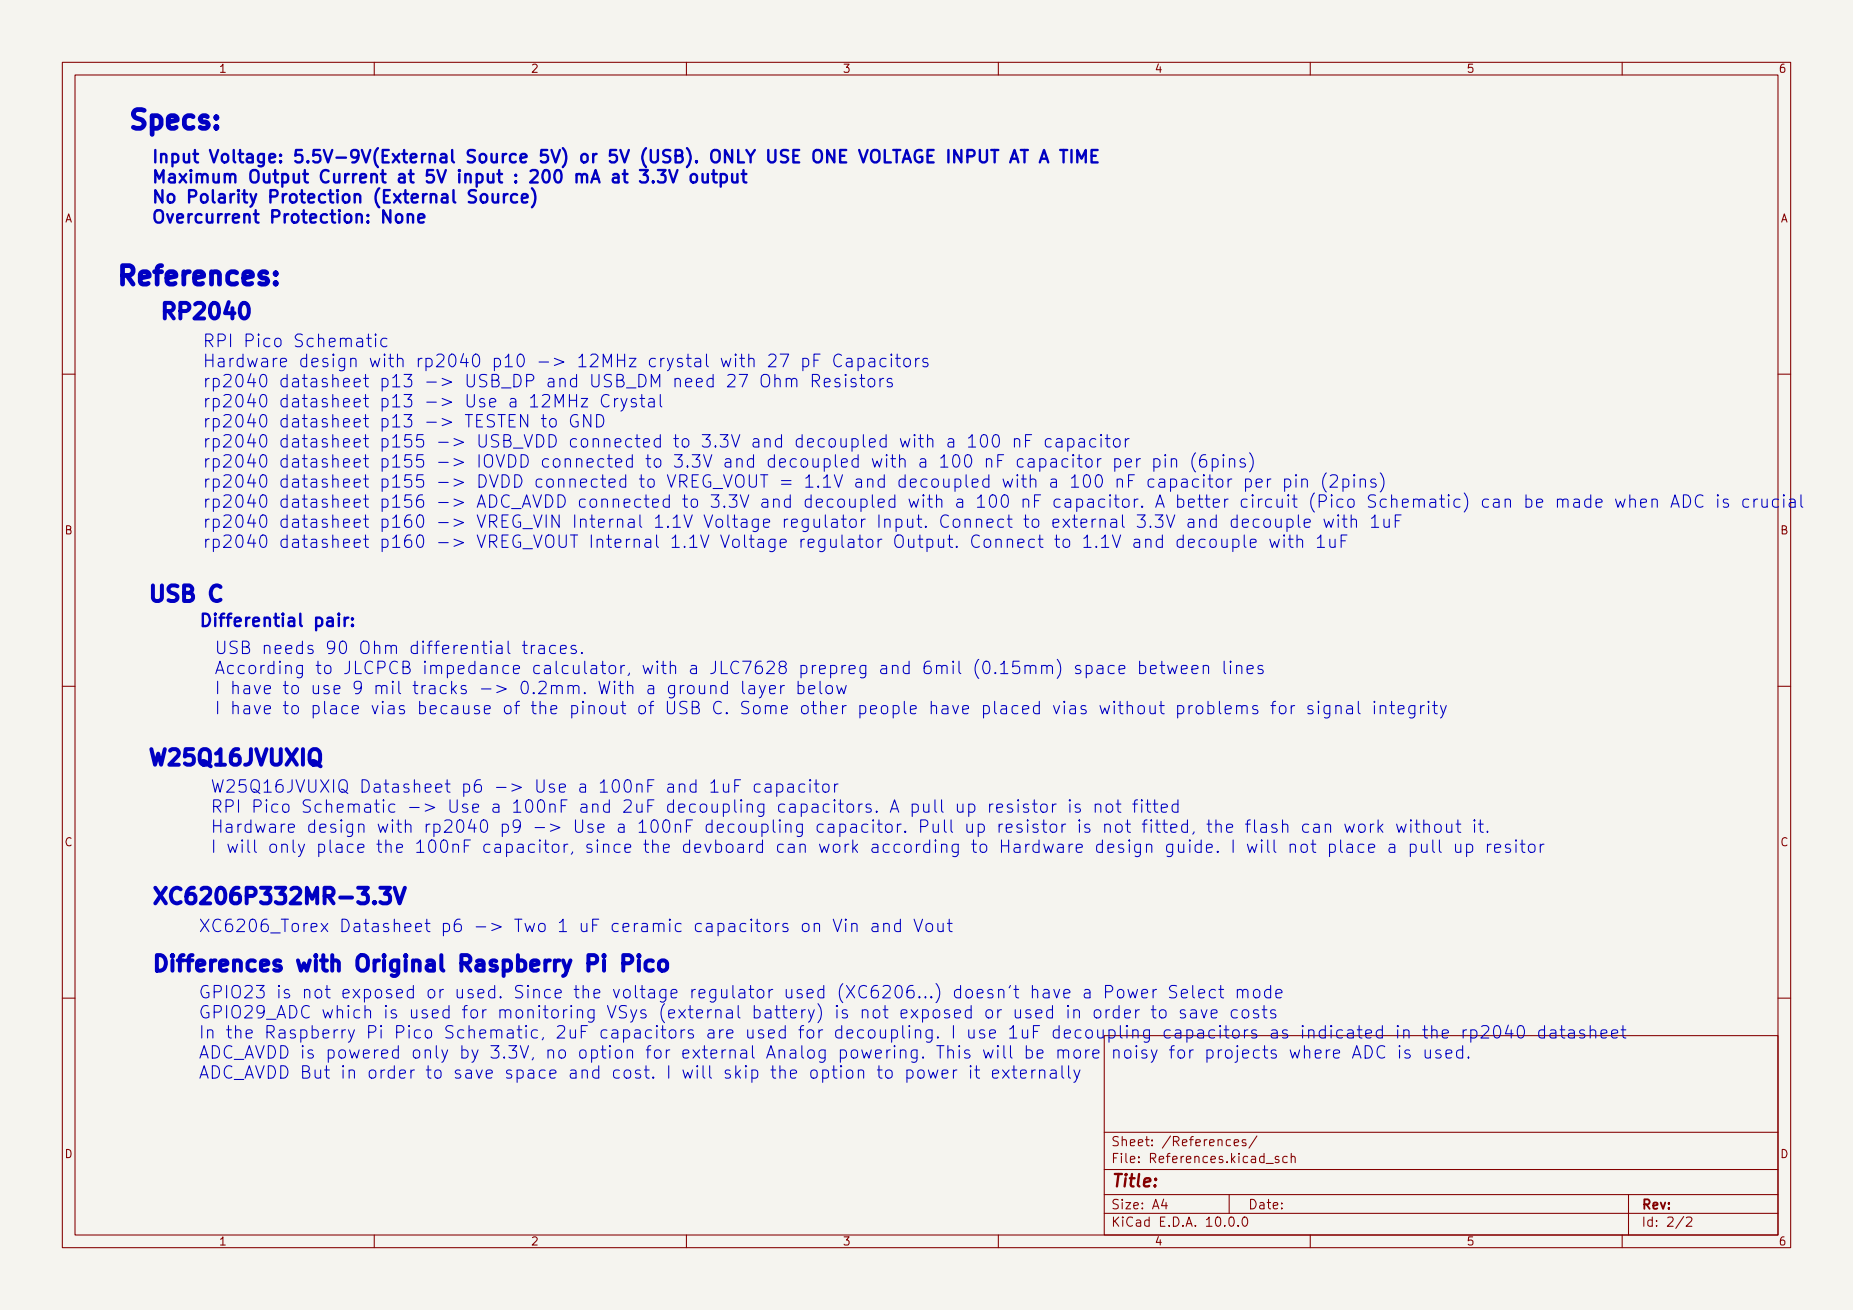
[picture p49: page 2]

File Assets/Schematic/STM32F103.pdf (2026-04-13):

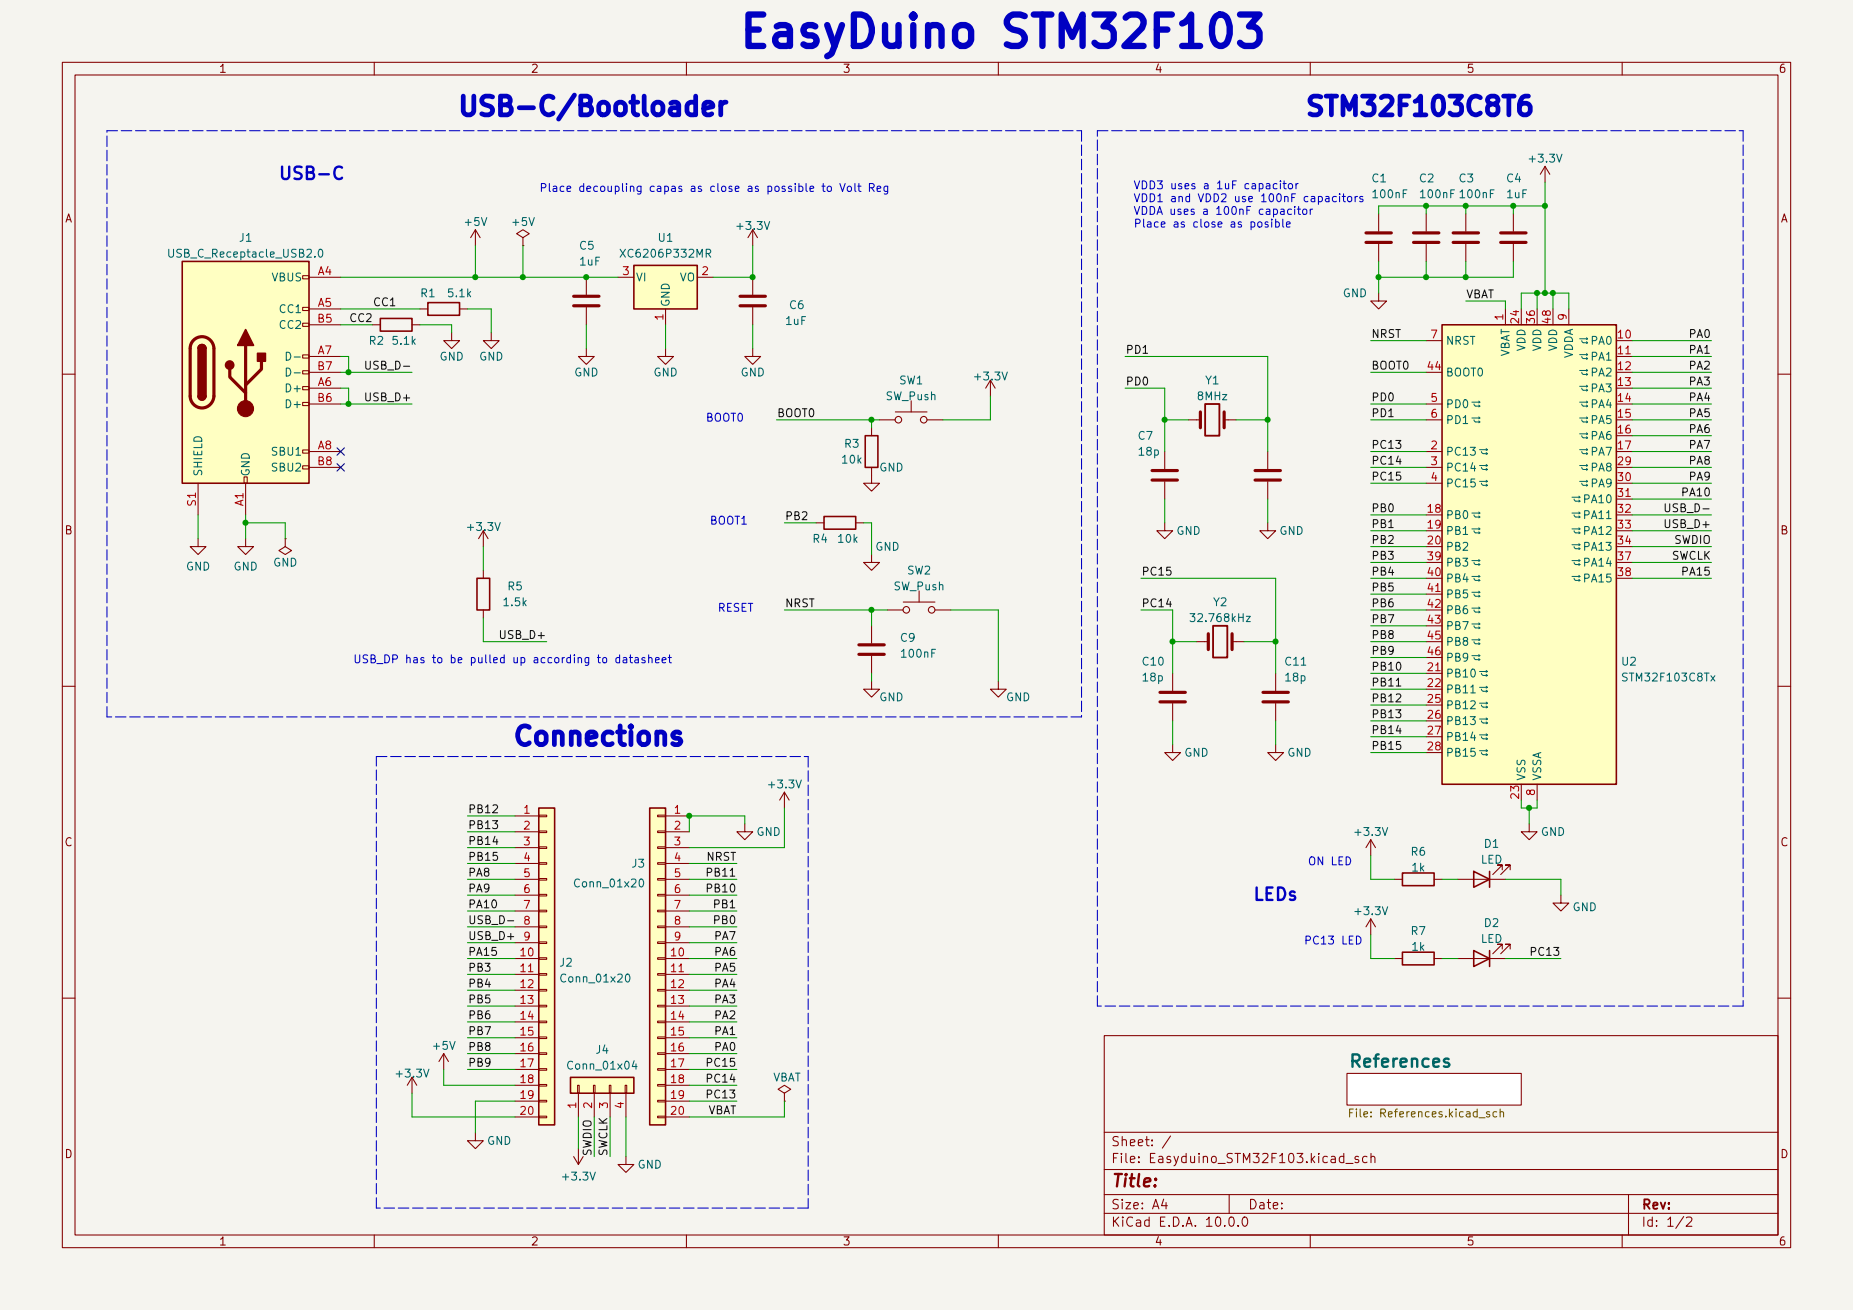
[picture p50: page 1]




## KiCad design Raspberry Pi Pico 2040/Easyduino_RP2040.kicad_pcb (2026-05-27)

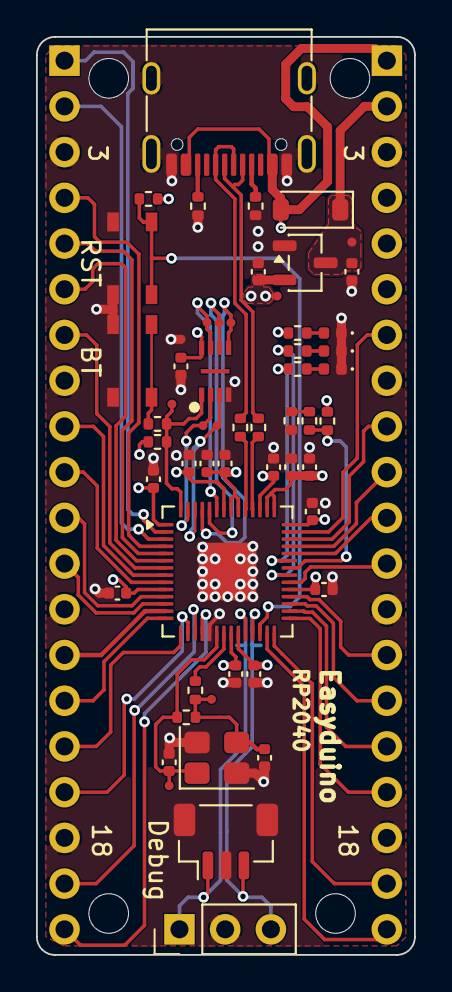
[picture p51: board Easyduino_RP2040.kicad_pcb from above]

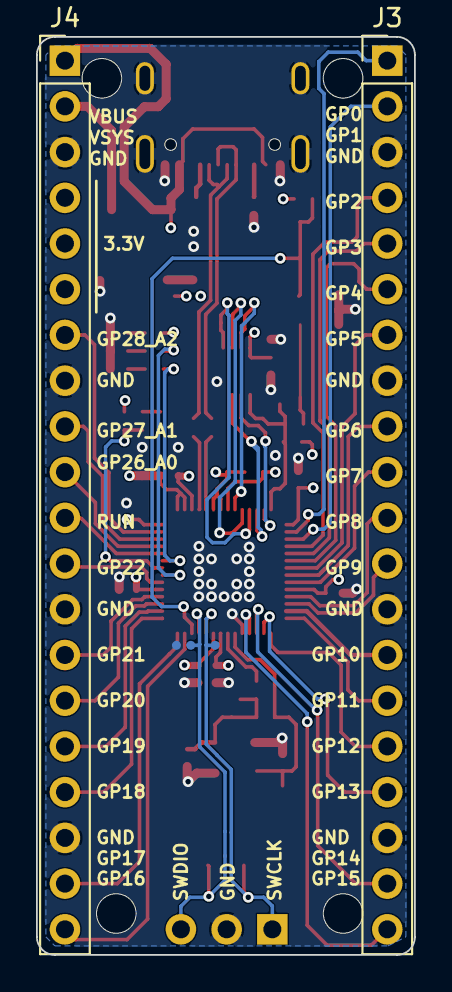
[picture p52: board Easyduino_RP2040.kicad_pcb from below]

Board: 4 copper layers, 21.0 x 51.0 mm, 65 parts (5 on the bottom side), 58 nets.

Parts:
C1, C2, C5, C6, C7, C8, C9, C10, C11, C12, C15: 100nF; C_0402_1005Metric
C3, C4, C13, C14: 1uF; C_0402_1005Metric
C16, C17: 27p; C_0402_1005Metric
D1: D_Schottky; D_SOD-123
D2, D3, D4: LED; LED_0402_1005Metric
H1, H2, H3, H4: MountingHole; MountingHole_2.2mm_M2
J1: USB_C_Receptacle_USB2.0; USB_C_Receptacle_G-Switch_GT-USB-7010ASV
J3, J4: Conn_01x20; PinHeader_1x20_P2.54mm_Vertical
J5: Conn_01x03; PinHeader_1x03_P2.54mm_Vertical
J6: Conn_01x03_MountingPin; JST_SH_BM03B-SRSS-TB_1x03-1MP_P1.00mm_Vertical
R1, R2, R3, R6, R7: 5.1k; R_0402_1005Metric
R4, R5: 27R; R_0402_1005Metric
R8, R9, R10, R11, R12, R13, R14, R15: 1k; R_0402_1005Metric
SW1, SW2: SW_Push; ALPSALPINE_SKRPACE010
TP1, TP2, TP3, TP4, TP5, TP6, TP7, TP8, TP9, TP10, TP11, TP12, TP13, TP14: TestPoint_pad
U1: XC6206P332MR; SOT-23-3
U2: RP2040; QFN-56-1EP_7x7mm_P0.4mm_EP3.2x3.2mm
U3: W25Q16JVUXIQ
Y1: 12MHz; Crystal_SMD_3225-4Pin_3.2x2.5mm

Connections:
+1V1: C1.1, C2.1, C3.1, U2.23 (DVDD), U2.45 (VREG_VOUT), U2.50 (DVDD)
+3.3V: C4.1, C5.1, C6.1, C7.1, C8.1, C9.1, C10.1, C11.1, C12.1, C14.1, C15.1, J4.4, J4.5, J4.6, R10.1, R11.1, R12.1, TP2.1 (1_1), U1.2 (VO), U2.1 (IOVDD), U2.10 (IOVDD), U2.22 (IOVDD), U2.33 (IOVDD), U2.42 (IOVDD), U2.43 (ADC_AVDD), U2.44 (VREG_IN), U2.48 (USB_VDD), U2.49 (IOVDD), U3.8 (VCC)
/CC1: J1.A5 (CC1), R1.1
/CC2: J1.B5 (CC2), R2.1
/GPIO0: J3.1, U2.2 (GPIO0)
/GPIO1: J3.2, U2.3 (GPIO1)
/GPIO2: J3.4, U2.4 (GPIO2)
/GPIO3: J3.5, U2.5 (GPIO3)
/GPIO4: J3.6, U2.6 (GPIO4)
/GPIO5: J3.7, U2.7 (GPIO5)
/GPIO6: J3.9, U2.8 (GPIO6)
/GPIO7: J3.10, U2.9 (GPIO7)
/GPIO8: J3.11, U2.11 (GPIO8)
/GPIO9: J3.12, U2.12 (GPIO9)
/GPIO10: J3.14, U2.13 (GPIO10)
/GPIO11: J3.15, U2.14 (GPIO11)
/GPIO12: J3.16, U2.15 (GPIO12)
/GPIO13: J3.17, U2.16 (GPIO13)
/GPIO14: J3.19, U2.17 (GPIO14)
/GPIO15: J3.20, U2.18 (GPIO15)
/GPIO16: J4.20, U2.27 (GPIO16)
/GPIO17: J4.19, U2.28 (GPIO17)
/GPIO18: J4.17, U2.29 (GPIO18)
/GPIO19: J4.16, U2.30 (GPIO19)
/GPIO20: J4.15, U2.31 (GPIO20)
/GPIO21: J4.14, U2.32 (GPIO21)
/GPIO22: J4.12, U2.34 (GPIO22)
/GPIO23: R13.1, U2.35 (GPIO23)
/GPIO24: R3.1, R6.2, U2.36 (GPIO24)
/GPIO25: R14.1, U2.37 (GPIO25)
/GPIO26_ADC0: J4.11, U2.38 (GPIO26_ADC0)
/GPIO27_ADC1: J4.10, U2.39 (GPIO27_ADC1)
/GPIO28_ADC2: J4.9, U2.40 (GPIO28_ADC2)
/GPIO29_ADC3: J4.7, U2.41 (GPIO29_ADC3)
/LED_3V3: D2.2 (A), R12.2
/LED_BUILT_IN1: D4.2 (A), R14.2
/LED_BUILT_IN2: D3.2 (A), R13.2
/QSPI_SCLK: TP9.1 (1_1), U2.52 (QSPI_SCLK), U3.6 (CLK)
/QSPI_SD0: TP10.1 (1_1), U2.53 (QSPI_SD0), U3.5 (DI(IO0))
/QSPI_SD1: TP11.1 (1_1), U2.55 (QSPI_SD1), U3.2 (DO(IO1))
/QSPI_SD2: TP12.1 (1_1), U2.54 (QSPI_SD2), U3.3 (IO2)
/QSPI_SD3: TP13.1 (1_1), U2.51 (QSPI_SD3), U3.7 (IO3)
/QSPI_SS: R10.2, R15.1, TP8.1 (1_1), U2.56 (QSPI_SS), U3.1 (~CS)
/RDIV: R6.1, R7.2
/RUN: R11.2, SW2.2, U2.26 (RUN)
/SW1_{PULL-UP}: R15.2, SW1.2
/SWCLK: J5.1, J6.1, TP5.1 (1_1), U2.24 (SWCLK)
/SWD: J5.3, J6.3, TP6.1 (1_1), U2.25 (SWD)
/USB_DN: J1.A7 (D-), J1.B7 (D-), R5.1
/USB_DP: J1.A6 (D+), J1.B6 (D+), R4.1
/USB_R_DN: R5.2, U2.46 (USB_DM)
/USB_R_DP: R4.2, U2.47 (USB_DP)
/Xin: C16.1, R8.1, TP3.1 (1_1), U2.20 (XIN), Y1.1
/Xout: R9.2, U2.21 (XOUT)
/XoutR: C17.1, R8.2, R9.1, TP4.1 (1_1), Y1.3
GND: C1.2, C2.2, C3.2, C4.2, C5.2, C6.2, C7.2, C8.2, C9.2, C10.2, C11.2, C12.2, C13.2, C14.2, C15.2, C16.2, C17.2, D2.1 (K), D3.1 (K), D4.1 (K), J1.A1 (GND), J1.A12 (GND), J1.B1 (GND), J1.B12 (GND), J1.SH (SHIELD), J3.3, J3.8, J3.13, J3.18, J4.3, J4.8, J4.13, J4.18, J5.2, J6.2, J6.MP (MountPin), R1.2, R2.2, R7.1, SW1.1, SW2.1, TP7.1 (1_1), TP14.1 (1_1), U1.1 (GND), U2.19 (TESTEN), U2.57 (GND), U3.4 (GND), Y1.2 (G), Y1.4 (G)
VBUS: D1.2 (A), J1.A4 (VBUS), J1.A9 (VBUS), J1.B4 (VBUS), J1.B9 (VBUS), J4.1, R3.2
VCC: C13.1, D1.1 (K), J4.2, TP1.1 (1_1), U1.3 (VI)

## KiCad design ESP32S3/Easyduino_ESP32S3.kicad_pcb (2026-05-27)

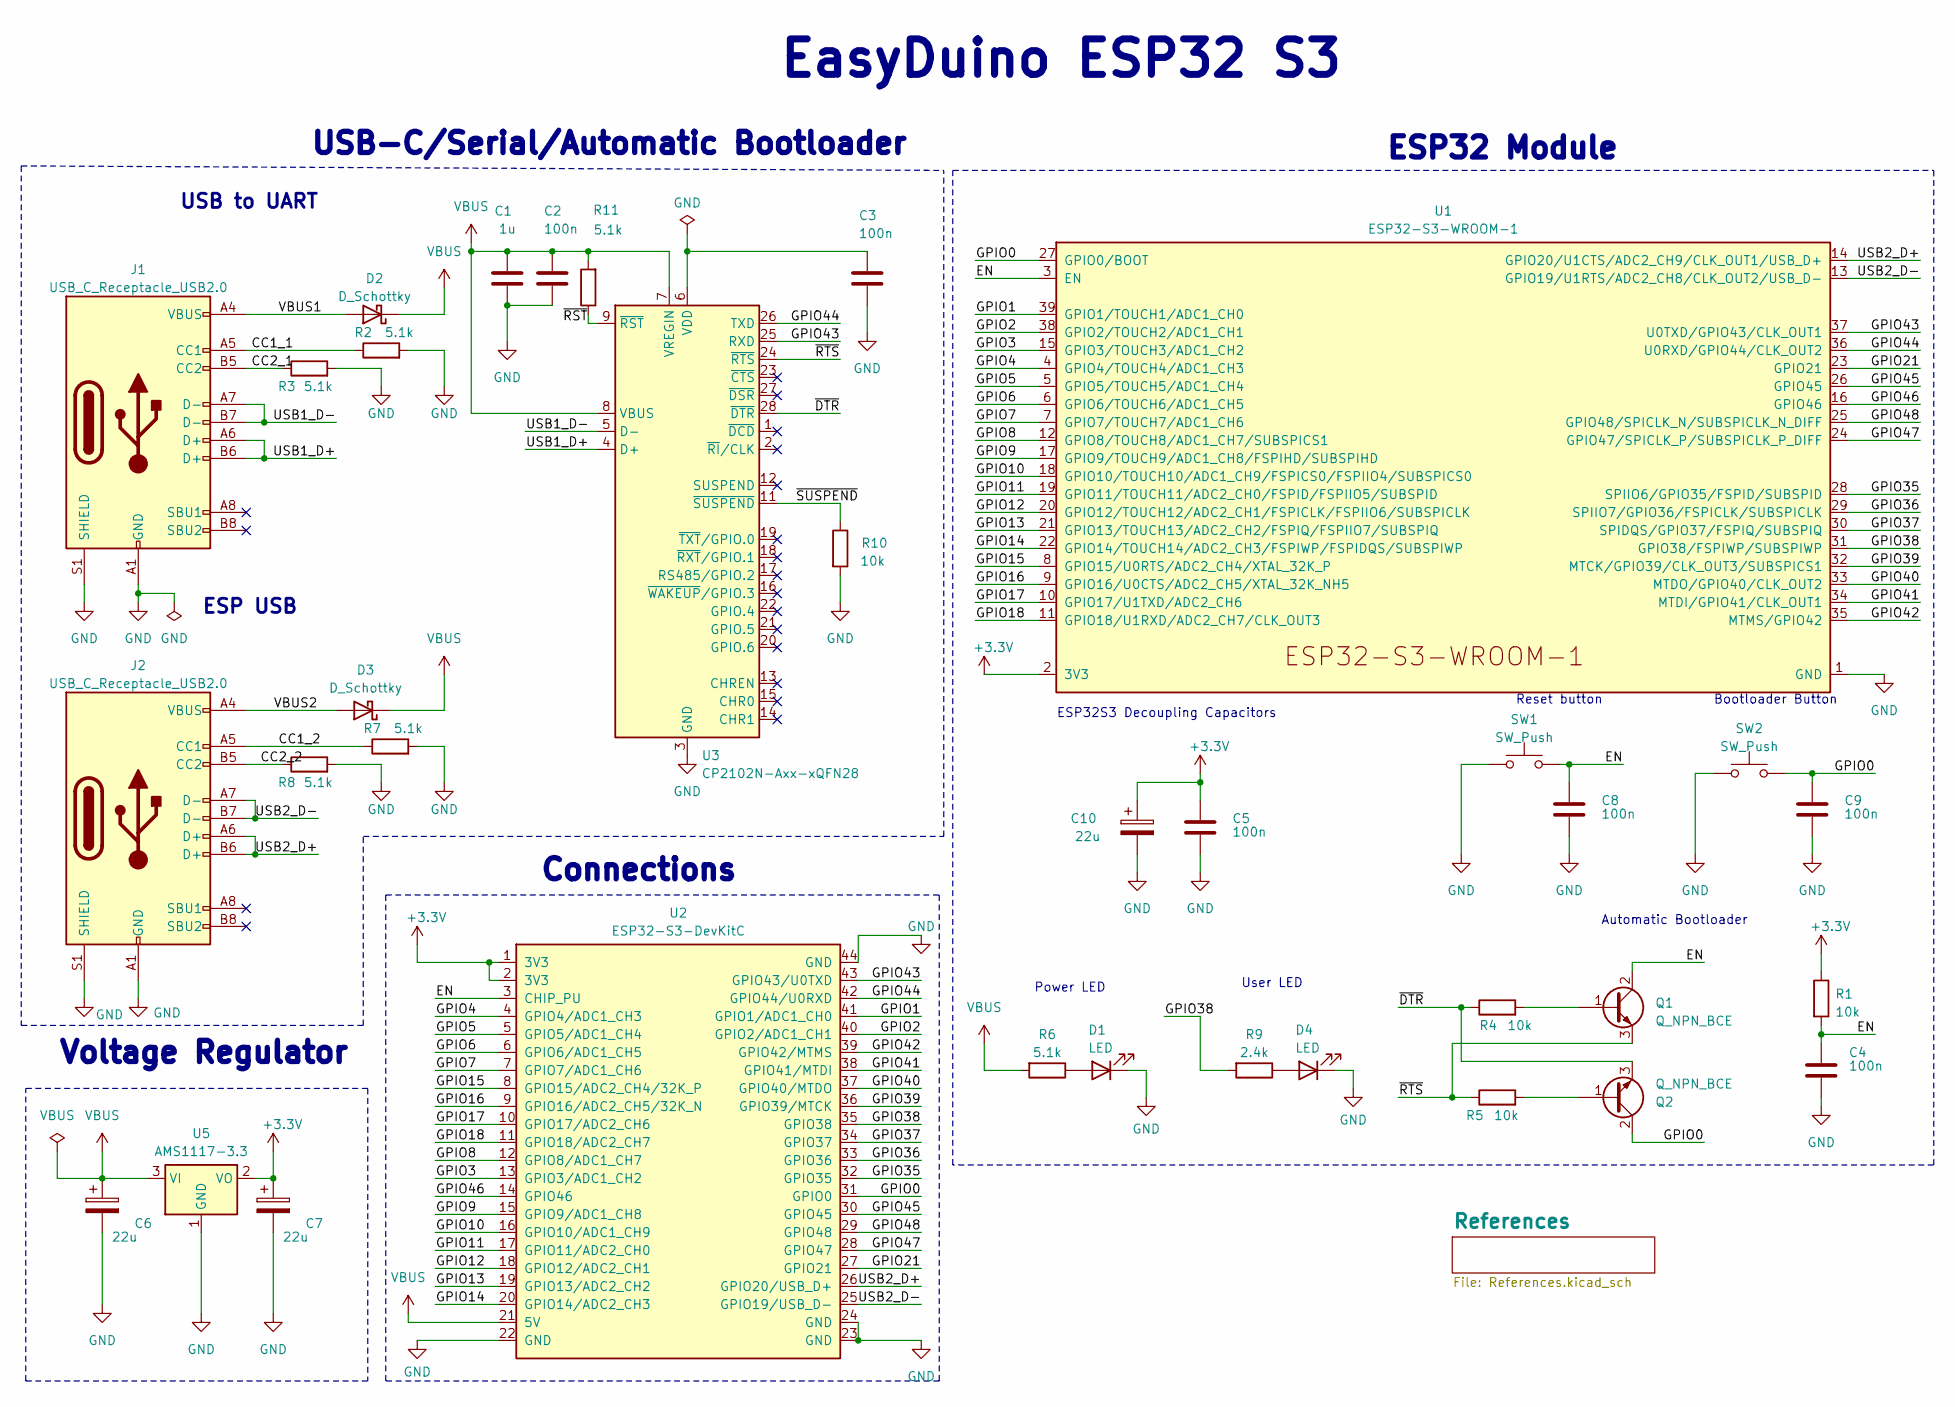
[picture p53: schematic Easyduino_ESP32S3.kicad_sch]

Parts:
C1: 1u; C_0402_1005Metric; LCSC C52923
C2, C3, C4, C5, C8, C9: 100n; C_0402_1005Metric; LCSC C1525
C6, C7, C10: 22u; CP_EIA-3216-10_Kemet-I; LCSC C11366
D1, D4: LED; LED_0402_1005Metric; LCSC C434447
D2, D3: D_Schottky; D_0402_1005Metric; LCSC C2837790
J1, J2: USB_C_Receptacle_USB2.0; USB_C_Receptacle_G-Switch_GT-USB-7010ASV; LCSC C2765186
Q1, Q2: Q_NPN_BCE; SOT-23W; LCSC C916392
R1, R4, R5, R10: 10k; R_0402_1005Metric; LCSC C25744
R2, R3, R6, R7, R8, R11: 5.1k; R_0402_1005Metric; LCSC C25905
R9: 2.4k; R_0402_1005Metric; LCSC C25882
SW1, SW2: SW_Push; SW_Push_SPST_NO_Alps_SKRK; LCSC C720477
U1: ESP32-S3-WROOM-1; LCSC C2913197
U2: ESP32-S3-DevKitC
U3: CP2102N-Axx-xQFN28; QFN-28-1EP_5x5mm_P0.5mm_EP3.35x3.35mm; LCSC C6568
U5: AMS1117-3.3; SOT-223-3_TabPin2; LCSC C6186

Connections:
+3.3V: C5.1, C7.1, C10.1, R1.1, U1.2 (3V3), U2.1 (3V3), U2.2 (3V3), U5.2 (VO)
/CC1_1: J1.A5 (CC1), R2.1
/CC1_2: J2.A5 (CC1), R7.1
/CC2_1: J1.B5 (CC2), R3.1
/CC2_2: J2.B5 (CC2), R8.1
/EN: C4.1, C8.1, Q1.2 (C), R1.2, SW1.2, U1.3 (EN), U2.3 (CHIP_PU)
/GPIO0: C9.1, Q2.2 (C), SW2.2, U1.27 (GPIO0/BOOT), U2.31 (GPIO0)
/GPIO1: U1.39 (GPIO1/TOUCH1/ADC1_CH0), U2.41 (GPIO1/ADC1_CH0)
/GPIO2: U1.38 (GPIO2/TOUCH2/ADC1_CH1), U2.40 (GPIO2/ADC1_CH1)
/GPIO3: U1.15 (GPIO3/TOUCH3/ADC1_CH2), U2.13 (GPIO3/ADC1_CH2)
/GPIO4: U1.4 (GPIO4/TOUCH4/ADC1_CH3), U2.4 (GPIO4/ADC1_CH3)
/GPIO5: U1.5 (GPIO5/TOUCH5/ADC1_CH4), U2.5 (GPIO5/ADC1_CH4)
/GPIO6: U1.6 (GPIO6/TOUCH6/ADC1_CH5), U2.6 (GPIO6/ADC1_CH5)
/GPIO7: U1.7 (GPIO7/TOUCH7/ADC1_CH6), U2.7 (GPIO7/ADC1_CH6)
/GPIO8: U1.12 (GPIO8/TOUCH8/ADC1_CH7/SUBSPICS1), U2.12 (GPIO8/ADC1_CH7)
/GPIO9: U1.17 (GPIO9/TOUCH9/ADC1_CH8/FSPIHD/SUBSPIHD), U2.15 (GPIO9/ADC1_CH8)
/GPIO10: U1.18 (GPIO10/TOUCH10/ADC1_CH9/FSPICS0/FSPIIO4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), U2.16 (GPIO10/ADC1_CH9)
/GPIO11: U1.19 (GPIO11/TOUCH11/ADC2_CH0/FSPID/FSPIIO5/S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), U2.17 (GPIO11/ADC2_CH0)
/GPIO12: U1.20 (GPIO12/TOUCH12/ADC2_CH1/FSPICLK/FSPIIO6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), U2.18 (GPIO12/ADC2_CH1)
/GPIO13: U1.21 (GPIO13/TOUCH13/ADC2_CH2/FSPIQ/FSPIIO7/S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), U2.19 (GPIO13/ADC2_CH2)
/GPIO14: U1.22 (GPIO14/TOUCH14/ADC2_CH3/FSPIWP/FSPIDQS/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), U2.20 (GPIO14/ADC2_CH3)
/GPIO15: U1.8 (GPIO15/U0RTS/ADC2_CH4/XTAL_32K_P), U2.8 (GPIO15/ADC2_CH4/32K_P)
/GPIO16: U1.9 (GPIO16/U0CTS/ADC2_CH5/XTAL_32K_NH5), U2.9 (GPIO16/ADC2_CH5/32K_N)
/GPIO17: U1.10 (GPIO17/U1TXD/ADC2_CH6), U2.10 (GPIO17/ADC2_CH6)
/GPIO18: U1.11 (GPIO18/U1RXD/ADC2_CH7/CLK_OUT3), U2.11 (GPIO18/ADC2_CH7)
/GPIO21: U1.23 (GPIO21), U2.27 (GPIO21)
/GPIO35: U1.28 (SPIIO6/GPIO35/FSPID/SUBSPID), U2.32 (GPIO35)
/GPIO36: U1.29 (SPIIO7/GPIO36/FSPICLK/SUBSPICLK), U2.33 (GPIO36)
/GPIO37: U1.30 (SPIDQS/GPIO37/FSPIQ/SUBSPIQ), U2.34 (GPIO37)
/GPIO38: R9.2, U1.31 (GPIO38/FSPIWP/SUBSPIWP), U2.35 (GPIO38)
/GPIO39: U1.32 (MTCK/GPIO39/CLK_OUT3/SUBSPICS1), U2.36 (GPIO39/MTCK)
/GPIO40: U1.33 (MTDO/GPIO40/CLK_OUT2), U2.37 (GPIO40/MTDO)
/GPIO41: U1.34 (MTDI/GPIO41/CLK_OUT1), U2.38 (GPIO41/MTDI)
/GPIO42: U1.35 (MTMS/GPIO42), U2.39 (GPIO42/MTMS)
/GPIO43: U1.37 (U0TXD/GPIO43/CLK_OUT1), U2.43 (GPIO43/U0TXD), U3.25 (RXD)
/GPIO44: U1.36 (U0RXD/GPIO44/CLK_OUT2), U2.42 (GPIO44/U0RXD), U3.26 (TXD)
/GPIO45: U1.26 (GPIO45), U2.30 (GPIO45)
/GPIO46: U1.16 (GPIO46), U2.14 (GPIO46)
/GPIO47: U1.24 (GPIO47/SPICLK_P/SUBSPICLK_P_DIFF), U2.28 (GPIO47)
/GPIO48: U1.25 (GPIO48/SPICLK_N/SUBSPICLK_N_DIFF), U2.29 (GPIO48)
/USB1_D+: J1.A6 (D+), J1.B6 (D+), U3.4 (D+)
/USB1_D-: J1.A7 (D-), J1.B7 (D-), U3.5 (D-)
/USB2_D+: J2.A6 (D+), J2.B6 (D+), U1.14 (GPIO20/U1CTS/ADC2_CH9/CLK_OUT1/USB_D+), U2.26 (GPIO20/USB_D+)
/USB2_D-: J2.A7 (D-), J2.B7 (D-), U1.13 (GPIO19/U1RTS/ADC2_CH8/CLK_OUT2/USB_D-), U2.25 (GPIO19/USB_D-)
/VBUS1: D2.2 (A), J1.A4 (VBUS), J1.A9 (VBUS), J1.B4 (VBUS), J1.B9 (VBUS)
/VBUS2: D3.2 (A), J2.A4 (VBUS), J2.A9 (VBUS), J2.B4 (VBUS), J2.B9 (VBUS)
/~DTR: Q2.3 (E), R4.1, U3.28 (~DTR)
/~RST: R11.1, U3.9 (~RST)
/~RTS: Q1.3 (E), R5.1, U3.24 (~RTS)
/~SUSPEND: R10.1, U3.11 (~SUSPEND)
GND: C1.2, C2.2, C3.2, C4.2, C5.2, C6.2, C7.2, C8.2, C9.2, C10.2, D1.1 (K), D4.1 (K), J1.A1 (GND), J1.A12 (GND), J1.B1 (GND), J1.B12 (GND), J1.S1 (SHIELD), J2.A1 (GND), J2.A12 (GND), J2.B1 (GND), J2.B12 (GND), J2.S1 (SHIELD), R2.2, R3.2, R7.2, R8.2, R10.2, SW1.1, SW2.1, U1.1 (GND), U1.40 (GND), U1.41 (GND), U2.22 (GND), U2.23 (GND), U2.24 (GND), U2.44 (GND), U3.3 (GND), U3.29 (GND), U5.1 (GND)
unnamed: D1.2 (A), R6.1
unnamed: D4.2 (A), R9.1
unnamed: Q1.1 (B), R4.2
unnamed: Q2.1 (B), R5.2
unnamed: C3.1, U3.6 (VDD)
VBUS: C1.1, C2.1, C6.1, D2.1 (K), D3.1 (K), R6.2, R11.2, U2.21 (5V), U3.7 (VREGIN), U3.8 (VBUS), U5.3 (VI)

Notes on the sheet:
Automatic Bootloader
ESP USB
Power LED
ESP32 Module
User LED
USB-C/Serial/Automatic Bootloader
ESP32S3 Decoupling Capacitors
Connections
USB to UART
Voltage Regulator
Bootloader Button
EasyDuino ESP32 S3
Reset button

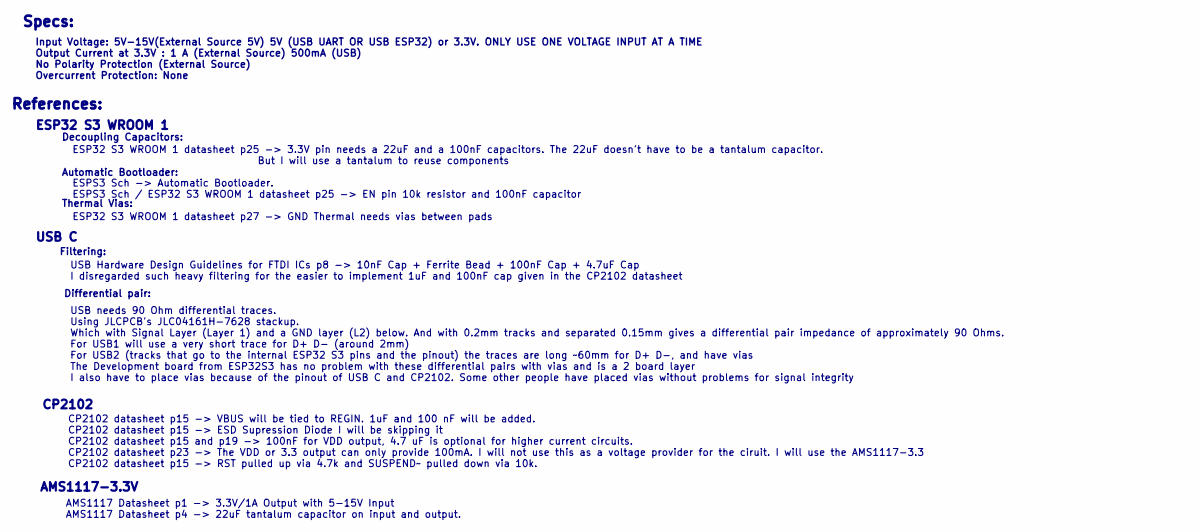
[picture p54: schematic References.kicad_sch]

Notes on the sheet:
Filtering:
Input Voltage: 5V-15V(External Source 5V) 5V (USB UART OR USB ESP32) or 3.3V. ONLY USE ONE VOLTAGE INPUT AT A TIME Output Current at 3.3V : 1 A (External Source) 500mA (USB) No Polarity Protection (External Source) Overcurrent Protection: None
Thermal Vias:
References:
ESP32 S3 WROOM 1
ESP32 S3 WROOM 1 datasheet p25 -> 3.3V pin needs a 22uF and a 100nF capacitors. The 22uF doesn't have to be a tantalum capacitor. But I will use a tantalum to reuse components ESPS3 Sch -> Automatic Bootloader. ESPS3 Sch / ESP32 S3 WROOM 1 datasheet p25 -> EN pin 10k resistor and 100nF capacitor ES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
Specs:
USB C
AMS1117-3.3V
CP2102 datasheet p15 -> VBUS will be tied to REGIN. 1uF and 100 nF will be added. CP2102 datasheet p15 -> ESD Supression Diode I will be skipping it CP2102 datasheet p15 and p19 -> 100nF for VDD output, 4.7 uF is optional for higher current circuits. CP2102 datasheet p23 -> The VDD or 3.3 output ca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
AMS1117 Datasheet p1 -> 3.3V/1A Output with 5-15V Input AMS1117 Datasheet p4 -> 22uF tantalum capacitor on input and output.
CP2102
Decoupling Capacitors:
USB needs 90 Ohm differential traces. Using JLCPCB's JLC04161H-7628 stackup. Which with Signal Layer (Layer 1) and a GND layer (L2) below. And with 0.2mm tracks and separated 0.15mm gives a differential pair impedance of approximately 90 Ohms. For USB1 will use a very short trace for D+ D- (around 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
Automatic Bootloader:
USB Hardware Design Guidelines for FTDI ICs p8 -> 10nF Cap + Ferrite Bead + 100nF Cap + 4.7uF Cap I disregarded such heavy filtering for the easier to implement 1uF and 100nF cap given in the CP2102 datasheet
Differential pair:

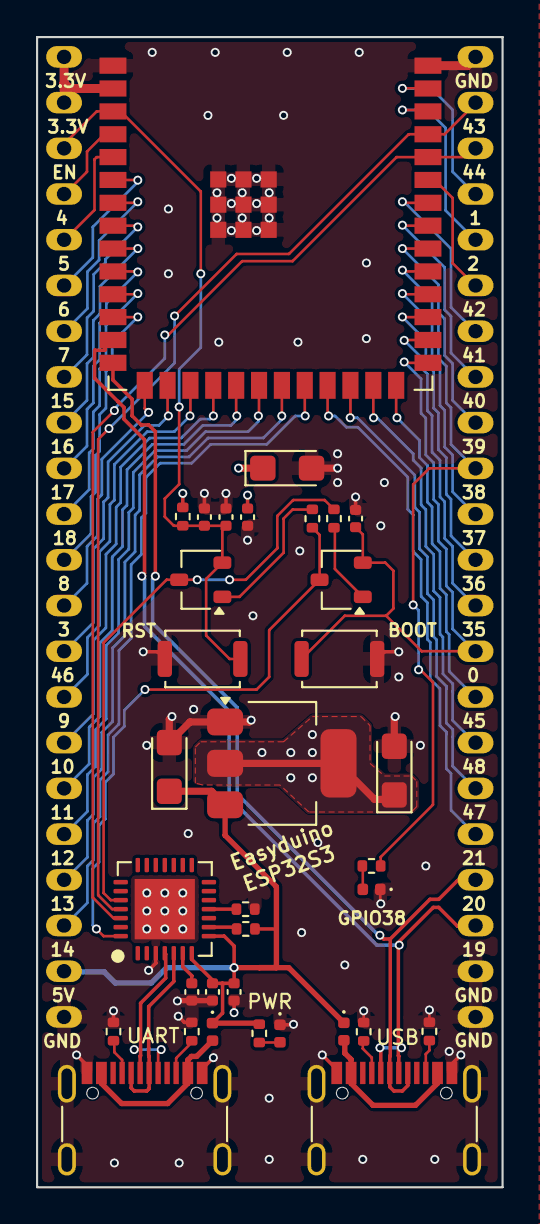
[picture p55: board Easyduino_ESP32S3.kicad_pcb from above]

Board: 4 copper layers, 25.9 x 63.9 mm, 35 parts (0 on the bottom side), 57 nets.

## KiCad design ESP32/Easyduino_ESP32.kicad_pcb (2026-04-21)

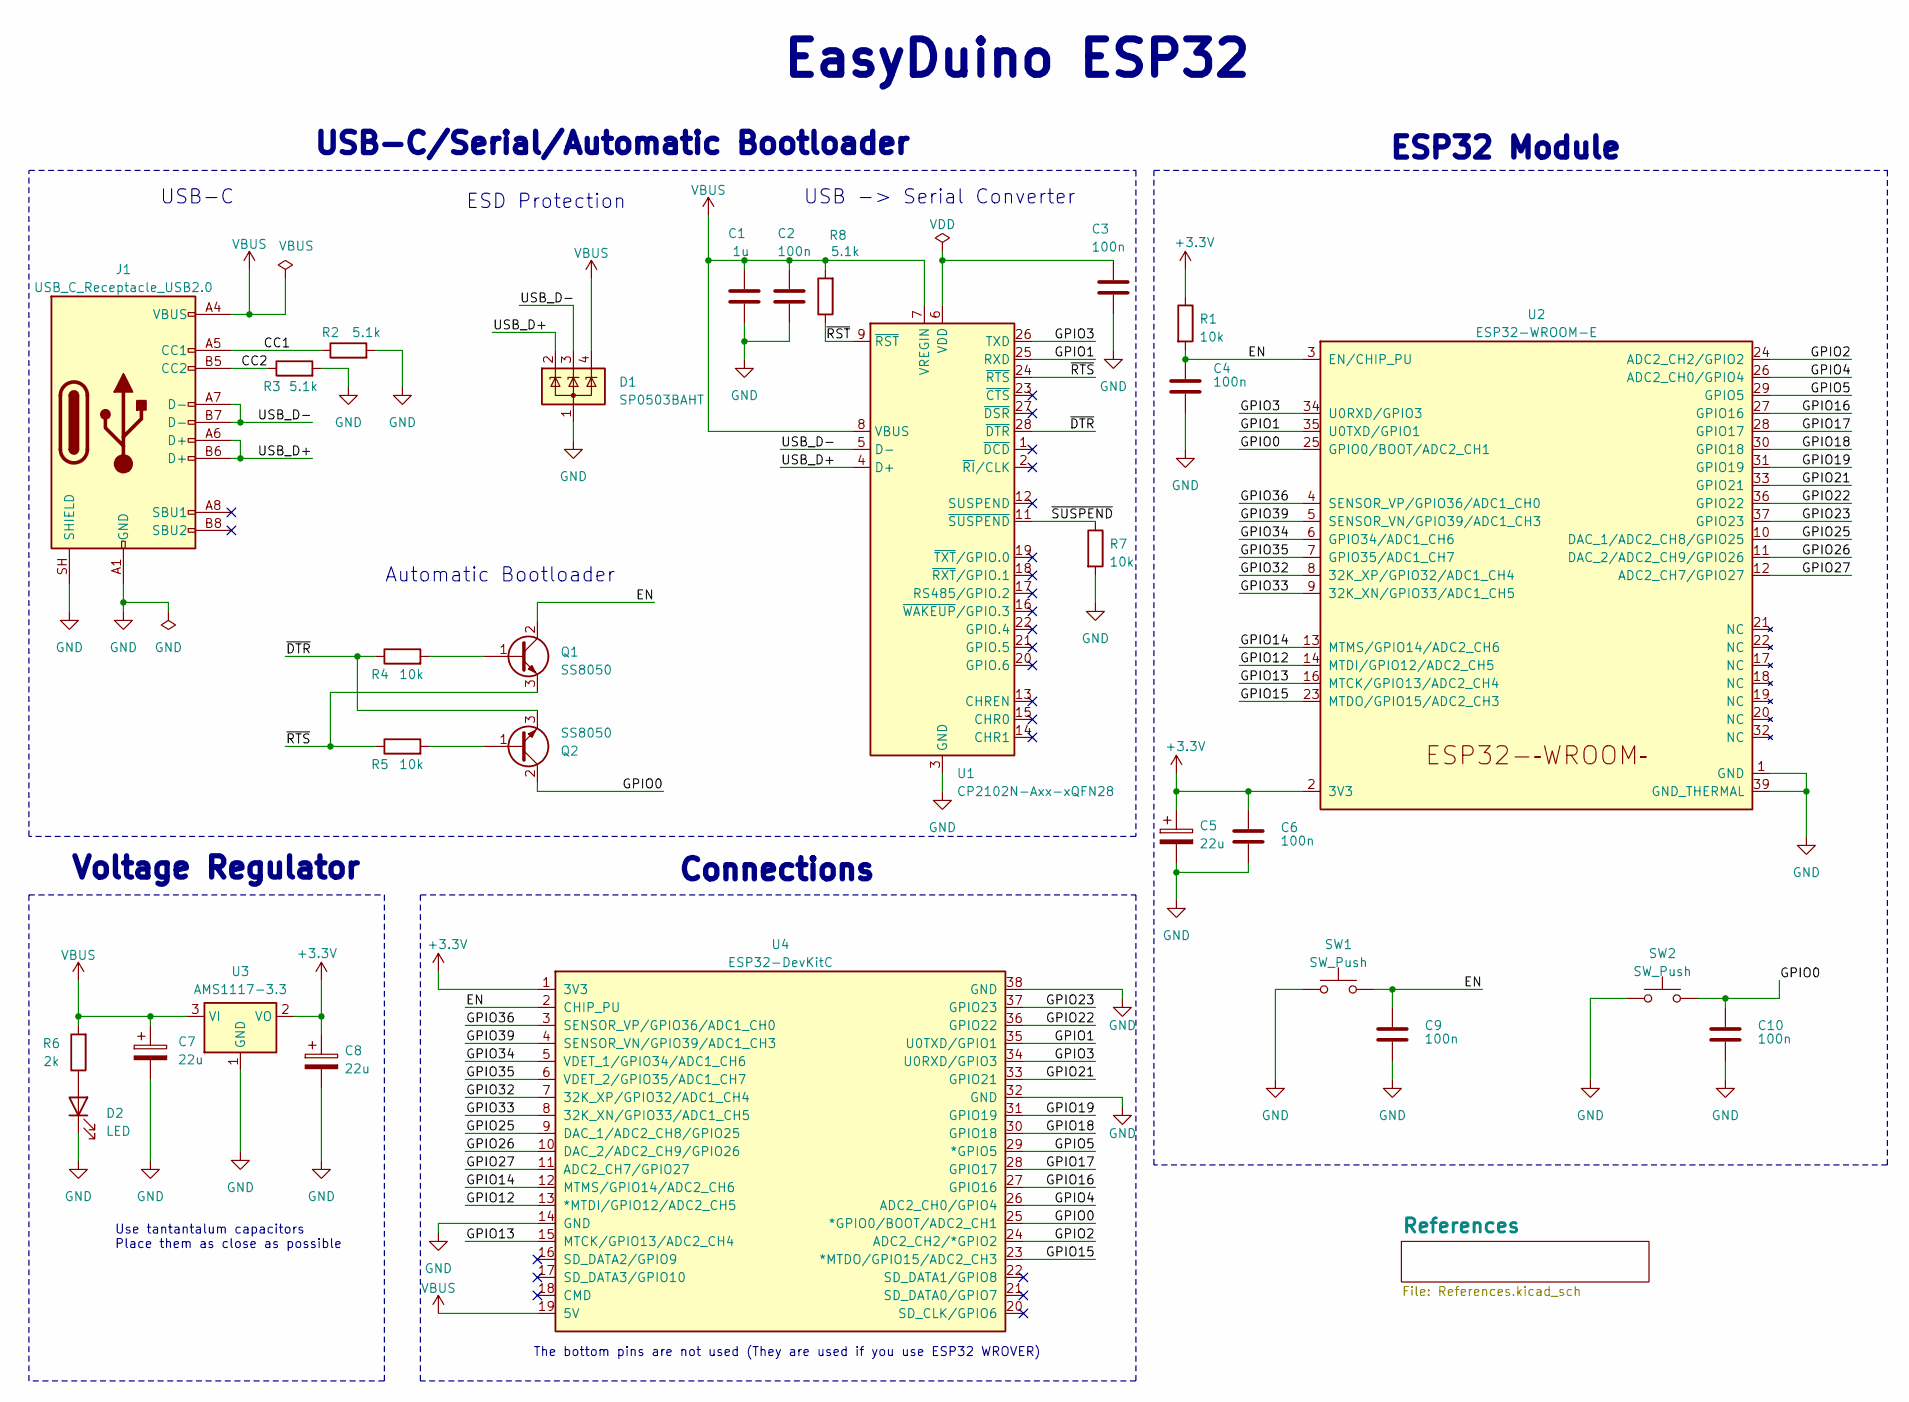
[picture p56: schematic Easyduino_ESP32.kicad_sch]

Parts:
C1: 1u; C_0402_1005Metric; LCSC C52923
C2, C3, C4, C6, C9, C10: 100n; C_0402_1005Metric; LCSC C1525
C5, C7, C8: 22u; CP_EIA-3216-10_Kemet-I; LCSC C11366
D1: SP0503BAHT; SOT-143; LCSC C7074
D2: LED; LED_0402_1005Metric; LCSC C434447
J1: USB_C_Receptacle_USB2.0; USB_C_Receptacle_G-Switch_GT-USB-7010ASV; LCSC C2765186
Q1, Q2: SS8050; SOT-23W; LCSC C916392
R1, R4, R5, R7: 10k; R_0402_1005Metric; LCSC C25744
R2, R3, R8: 5.1k; R_0402_1005Metric; LCSC C25905
R6: 2k; R_0402_1005Metric; LCSC C4109
SW1, SW2: SW_Push; SW_Push_SPST_NO_Alps_SKRK; LCSC C720477
U1: CP2102N-Axx-xQFN28; QFN-28-1EP_5x5mm_P0.5mm_EP3.35x3.35mm; LCSC C6568
U2: ESP32-WROOM-E; ESP32-WROOM-32E; LCSC C701342
U3: AMS1117-3.3; SOT-223-3_TabPin2; LCSC C6186
U4: ESP32-DevKitC

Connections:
+3.3V: C5.1, C6.1, C8.1, R1.1, U2.2 (3V3), U3.2 (VO), U4.1 (3V3)
/CC1: J1.A5 (CC1), R2.1
/CC2: J1.B5 (CC2), R3.1
/EN: C4.1, C9.1, Q1.2 (C), R1.2, SW1.2, U2.3 (EN/CHIP_PU), U4.2 (CHIP_PU)
/GPIO0: C10.1, Q2.2 (C), SW2.2, U2.25 (GPIO0/BOOT/ADC2_CH1), U4.25 (*GPIO0/BOOT/ADC2_CH1)
/GPIO1: U1.25 (RXD), U2.35 (U0TXD/GPIO1), U4.35 (U0TXD/GPIO1)
/GPIO2: U2.24 (ADC2_CH2/GPIO2), U4.24 (ADC2_CH2/*GPIO2)
/GPIO3: U1.26 (TXD), U2.34 (U0RXD/GPIO3), U4.34 (U0RXD/GPIO3)
/GPIO4: U2.26 (ADC2_CH0/GPIO4), U4.26 (ADC2_CH0/GPIO4)
/GPIO5: U2.29 (GPIO5), U4.29 (*GPIO5)
/GPIO12: U2.14 (MTDI/GPIO12/ADC2_CH5), U4.13 (*MTDI/GPIO12/ADC2_CH5)
/GPIO13: U2.16 (MTCK/GPIO13/ADC2_CH4), U4.15 (MTCK/GPIO13/ADC2_CH4)
/GPIO14: U2.13 (MTMS/GPIO14/ADC2_CH6), U4.12 (MTMS/GPIO14/ADC2_CH6)
/GPIO15: U2.23 (MTDO/GPIO15/ADC2_CH3), U4.23 (*MTDO/GPIO15/ADC2_CH3)
/GPIO16: U2.27 (GPIO16), U4.27 (GPIO16)
/GPIO17: U2.28 (GPIO17), U4.28 (GPIO17)
/GPIO18: U2.30 (GPIO18), U4.30 (GPIO18)
/GPIO19: U2.31 (GPIO19), U4.31 (GPIO19)
/GPIO21: U2.33 (GPIO21), U4.33 (GPIO21)
/GPIO22: U2.36 (GPIO22), U4.36 (GPIO22)
/GPIO23: U2.37 (GPIO23), U4.37 (GPIO23)
/GPIO25: U2.10 (DAC_1/ADC2_CH8/GPIO25), U4.9 (DAC_1/ADC2_CH8/GPIO25)
/GPIO26: U2.11 (DAC_2/ADC2_CH9/GPIO26), U4.10 (DAC_2/ADC2_CH9/GPIO26)
/GPIO27: U2.12 (ADC2_CH7/GPIO27), U4.11 (ADC2_CH7/GPIO27)
/GPIO32: U2.8 (32K_XP/GPIO32/ADC1_CH4), U4.7 (32K_XP/GPIO32/ADC1_CH4)
/GPIO33: U2.9 (32K_XN/GPIO33/ADC1_CH5), U4.8 (32K_XN/GPIO33/ADC1_CH5)
/GPIO34: U2.6 (GPIO34/ADC1_CH6), U4.5 (VDET_1/GPIO34/ADC1_CH6)
/GPIO35: U2.7 (GPIO35/ADC1_CH7), U4.6 (VDET_2/GPIO35/ADC1_CH7)
/GPIO36: U2.4 (SENSOR_VP/GPIO36/ADC1_CH0), U4.3 (SENSOR_VP/GPIO36/ADC1_CH0)
/GPIO39: U2.5 (SENSOR_VN/GPIO39/ADC1_CH3), U4.4 (SENSOR_VN/GPIO39/ADC1_CH3)
/USB_D+: D1.2 (K), J1.A6 (D+), J1.B6 (D+), U1.4 (D+)
/USB_D-: D1.3 (K), J1.A7 (D-), J1.B7 (D-), U1.5 (D-)
/~DTR: Q2.3 (E), R4.1, U1.28 (~DTR)
/~RST: R8.1, U1.9 (~RST)
/~RTS: Q1.3 (E), R5.1, U1.24 (~RTS)
/~SUSPEND: R7.1, U1.11 (~SUSPEND)
GND: C1.2, C2.2, C3.2, C4.2, C5.2, C6.2, C7.2, C8.2, C9.2, C10.2, D1.1 (A), D2.1 (K), J1.A1 (GND), J1.A12 (GND), J1.B1 (GND), J1.B12 (GND), J1.SH (SHIELD), R2.2, R3.2, R7.2, SW1.1, SW2.1, U1.3 (GND), U1.29 (GND), U2.1 (GND), U2.15 (GND), U2.38 (GND), U2.39 (GND_THERMAL), U3.1 (GND), U4.14 (GND), U4.32 (GND), U4.38 (GND)
unnamed: D2.2 (A), R6.1
unnamed: Q1.1 (B), R4.2
unnamed: Q2.1 (B), R5.2
unnamed: C3.1, U1.6 (VDD)
VBUS: C1.1, C2.1, C7.1, D1.4 (K), J1.A4 (VBUS), J1.A9 (VBUS), J1.B4 (VBUS), J1.B9 (VBUS), R6.2, R8.2, U1.7 (VREGIN), U1.8 (VBUS), U3.3 (VI), U4.19 (5V)

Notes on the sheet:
ESD Protection
ESP32 Module
Voltage Regulator
Use tantantalum capacitors Place them as close as possible
Automatic Bootloader
USB-C
The bottom pins are not used (They are used if you use ESP32 WROVER)
USB -> Serial Converter
USB-C/Serial/Automatic Bootloader
EasyDuino ESP32
Connections

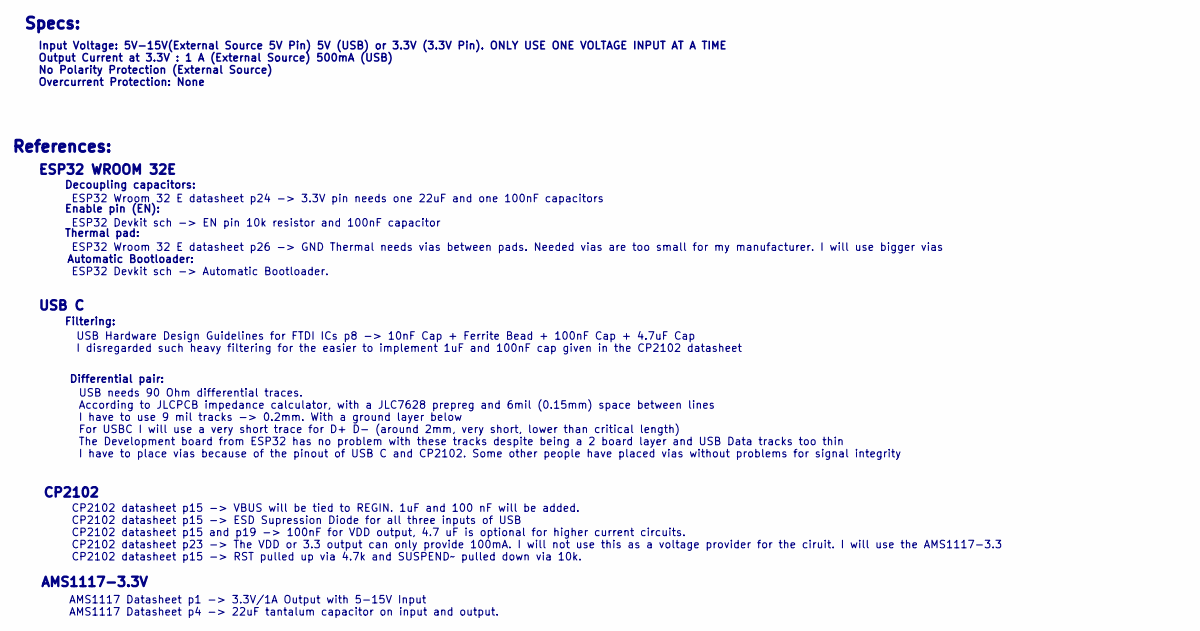
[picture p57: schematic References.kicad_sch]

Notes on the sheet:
ESP32 WROOM 32E
CP2102
AMS1117-3.3V
References:
Automatic Bootloader:
Decoupling capacitors:
ESP32 Wroom 32 E datasheet p24 -> 3.3V pin needs one 22uF and one 100nF capacitors ESP32 Devkit sch -> EN pin 10k resistor and 100nF capacitor ESP32 Wroom 32 E datasheet p26 -> GND Thermal needs vias between pads. Needed vias are too small for my manufacturer. I will use bigger vias ESP32 Devkit sc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
CP2102 datasheet p15 -> VBUS will be tied to REGIN. 1uF and 100 nF will be added. CP2102 datasheet p15 -> ESD Supression Diode for all three inputs of USB CP2102 datasheet p15 and p19 -> 100nF for VDD output, 4.7 uF is optional for higher current circuits. CP2102 datasheet p23 -> The VDD or 3.3 out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
Filtering:
Input Voltage: 5V-15V(External Source 5V Pin) 5V (USB) or 3.3V (3.3V Pin). ONLY USE ONE VOLTAGE INPUT AT A TIME Output Current at 3.3V : 1 A (External Source) 500mA (USB) No Polarity Protection (External Source) Overcurrent Protection: None
USB C
Specs:
Differential pair:
USB needs 90 Ohm differential traces. According to JLCPCB impedance calculator, with a JLC7628 prepreg and 6mil (0.15mm) space between lines I have to use 9 mil tracks -> 0.2mm. With a ground layer below For USBC I will use a very short trace for D+ D- (around 2mm, very short, lower than critical l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
USB Hardware Design Guidelines for FTDI ICs p8 -> 10nF Cap + Ferrite Bead + 100nF Cap + 4.7uF Cap I disregarded such heavy filtering for the easier to implement 1uF and 100nF cap given in the CP2102 datasheet
Enable pin (EN):
Thermal pad:
AMS1117 Datasheet p1 -> 3.3V/1A Output with 5-15V Input AMS1117 Datasheet p4 -> 22uF tantalum capacitor on input and output.

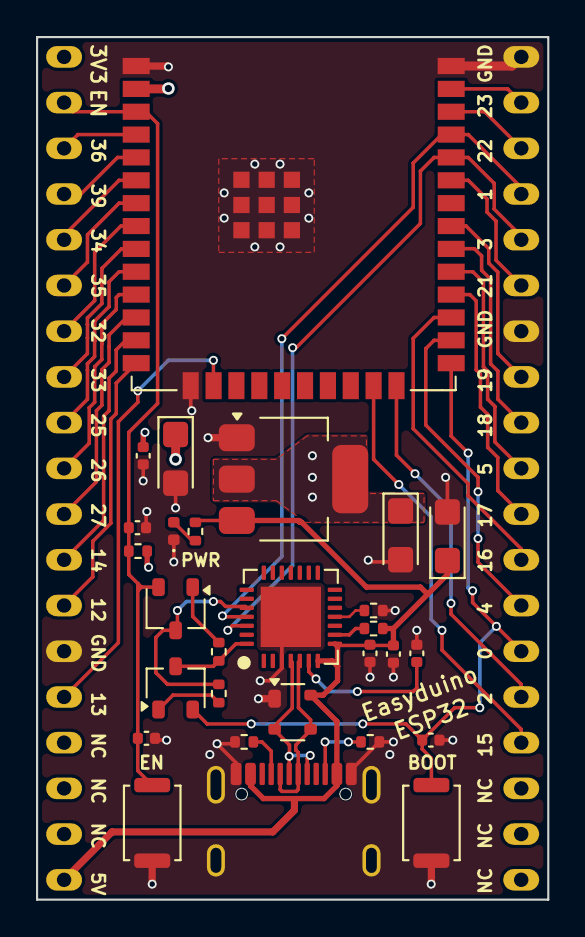
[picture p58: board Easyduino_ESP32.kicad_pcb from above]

Board: 4 copper layers, 28.4 x 47.9 mm, 29 parts (0 on the bottom side), 42 nets.

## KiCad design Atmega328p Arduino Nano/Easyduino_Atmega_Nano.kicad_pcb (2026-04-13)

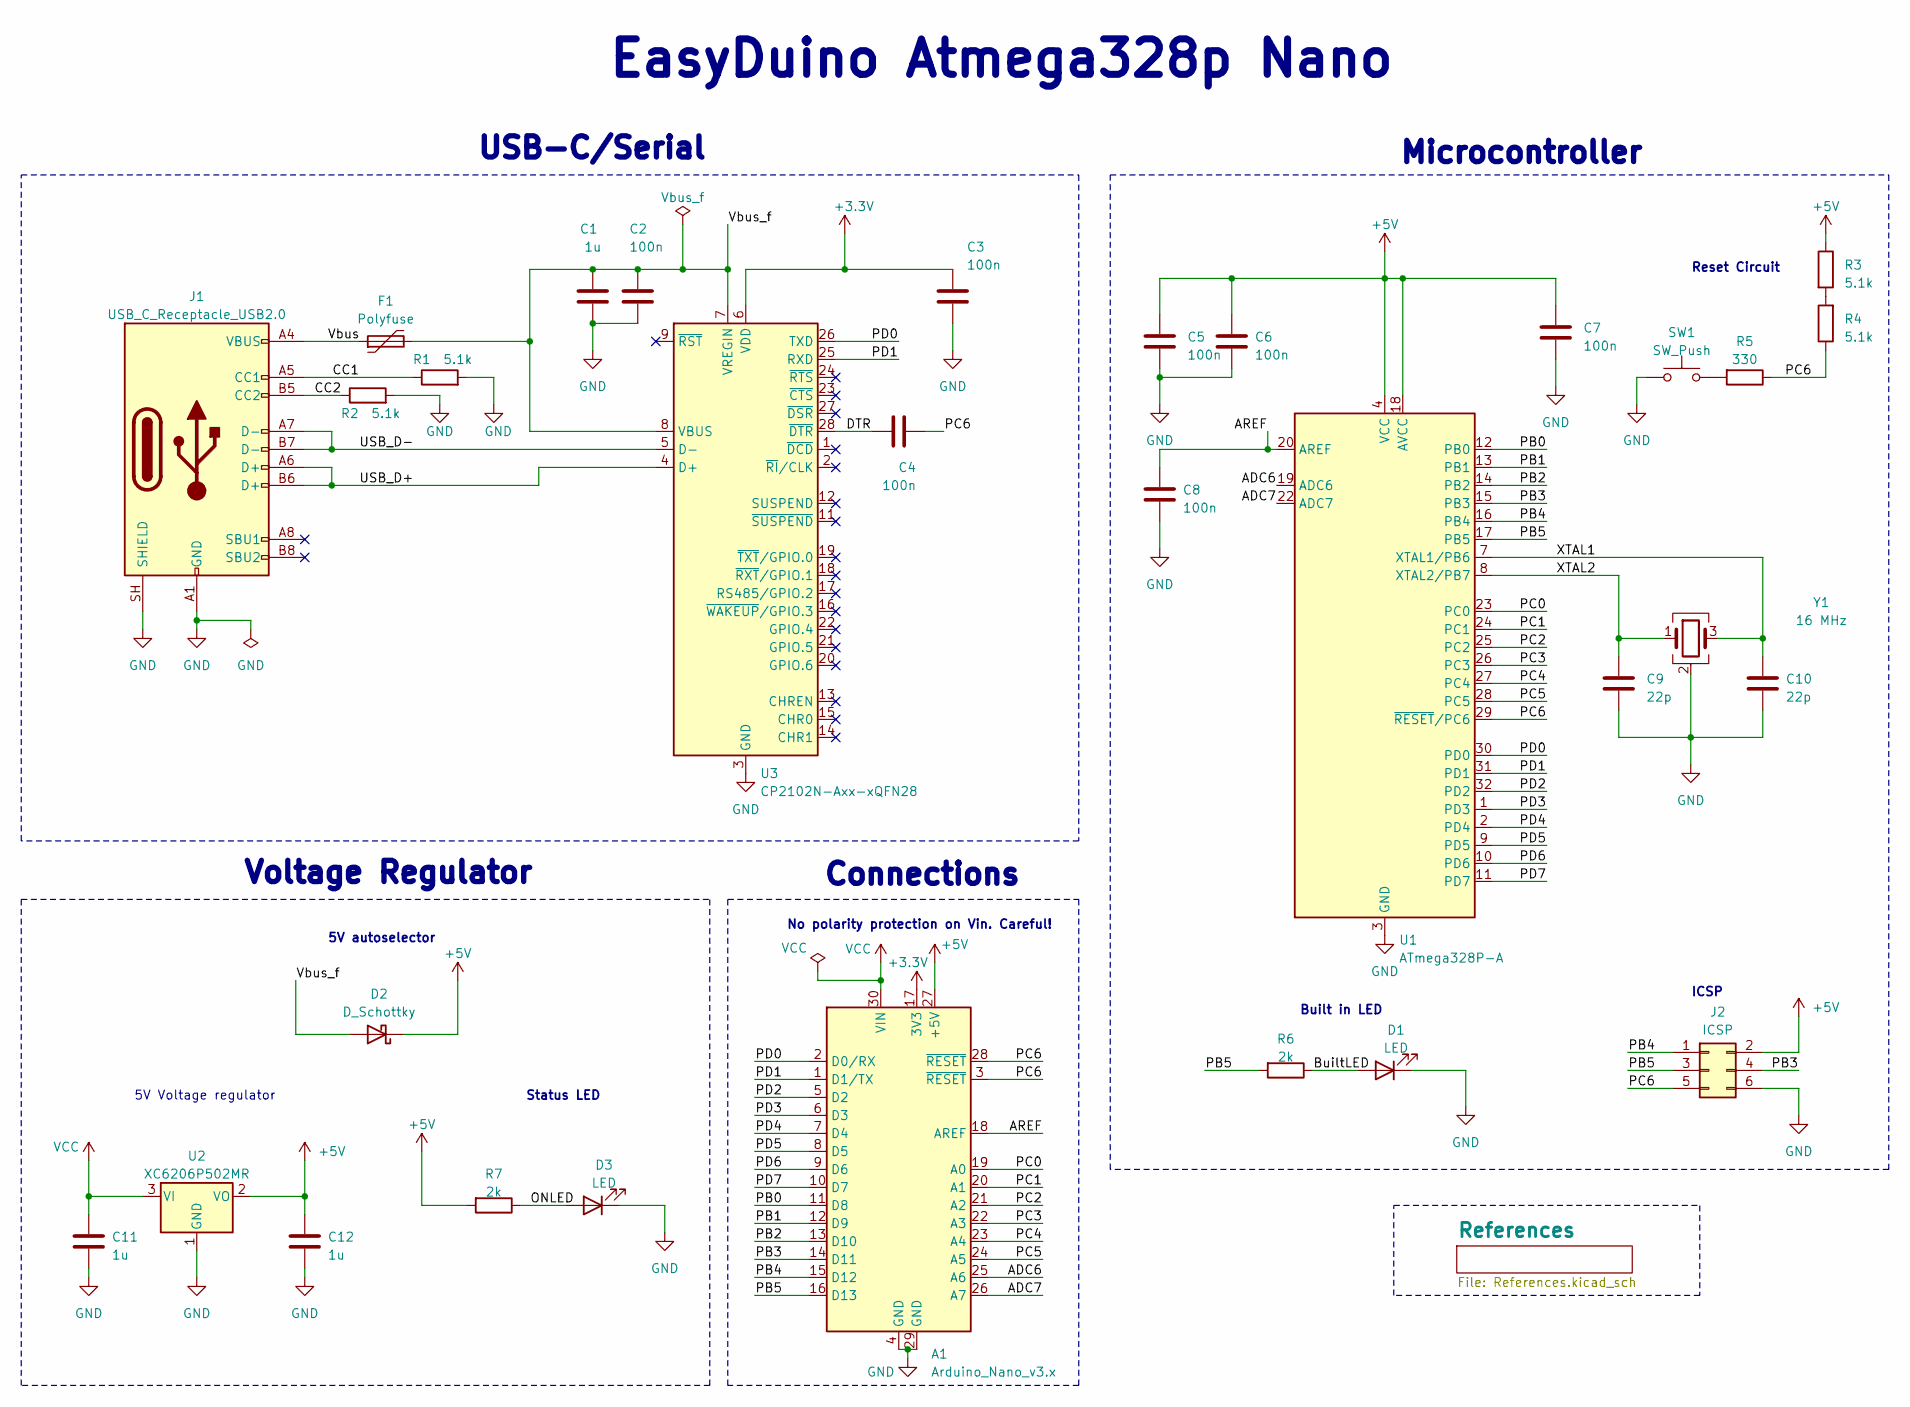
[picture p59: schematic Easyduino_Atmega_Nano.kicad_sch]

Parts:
A1: Arduino_Nano_v3.x; Arduino_Nano_WithMountingHoles
C1, C11, C12: 1u; C_0402_1005Metric; LCSC C52923
C2, C3, C4, C5, C6, C7, C8: 100n; C_0402_1005Metric; LCSC C1525
C9, C10: 22p; C_0402_1005Metric; LCSC C1555
D1, D3: LED; LED_0402_1005Metric; LCSC C434447
D2: D_Schottky; D_0402_1005Metric; LCSC C2837790
F1: Polyfuse; Fuse_0402_1005Metric; LCSC C914087
J1: USB_C_Receptacle_USB2.0; USB_C_Receptacle_G-Switch_GT-USB-7010ASV; LCSC C2765186
J2: ICSP; PinHeader_2x03_P2.54mm_Vertical
R1, R2, R3, R4: 5.1k; R_0402_1005Metric; LCSC C25905
R5: 330; R_0402_1005Metric; LCSC C25104
R6, R7: 2k; R_0402_1005Metric; LCSC C4109
SW1: SW_Push; SW_Tactile_SPST_NO_Straight_CK_PTS636Sx25SMTRLFS; LCSC C520860
U1: ATmega328P-A; TQFP-32_7x7mm_P0.8mm; LCSC C14877
U2: XC6206P502MR; SOT-23-3; LCSC C16767
U3: CP2102N-Axx-xQFN28; QFN-28-1EP_5x5mm_P0.5mm_EP3.35x3.35mm; LCSC C6568
Y1: 16 MHz; Crystal_SMD_3225-4Pin_3.2x2.5mm; LCSC C13738

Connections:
+3.3V: A1.17 (3V3), C3.1, U3.6 (VDD)
+5V: A1.27 (+5V), C5.1, C6.1, C7.2, C12.1, D2.1 (K), J2.2, R3.1, R7.2, U1.4 (VCC), U1.6 (VCC), U1.18 (AVCC), U2.2 (VO)
/ADC6: A1.25 (A6), U1.19 (ADC6)
/ADC7: A1.26 (A7), U1.22 (ADC7)
/AREF: A1.18 (AREF), C8.1, U1.20 (AREF)
/BuiltLED: D1.2 (A), R6.1
/CC1: J1.A5 (CC1), R1.1
/CC2: J1.B5 (CC2), R2.1
/DTR: C4.1, U3.28 (~DTR)
/ONLED: D3.2 (A), R7.1
/PB0: A1.11 (D8), U1.12 (PB0)
/PB1: A1.12 (D9), U1.13 (PB1)
/PB2: A1.13 (D10), U1.14 (PB2)
/PB3: A1.14 (D11), J2.4, U1.15 (PB3)
/PB4: A1.15 (D12), J2.1, U1.16 (PB4)
/PB5: A1.16 (D13), J2.3, R6.2, U1.17 (PB5)
/PC0: A1.19 (A0), U1.23 (PC0)
/PC1: A1.20 (A1), U1.24 (PC1)
/PC2: A1.21 (A2), U1.25 (PC2)
/PC3: A1.22 (A3), U1.26 (PC3)
/PC4: A1.23 (A4), U1.27 (PC4)
/PC5: A1.24 (A5), U1.28 (PC5)
/PC6: A1.3 (~RESET), A1.28 (~RESET), C4.2, J2.5, R4.1, R5.1, U1.29 (~RESET/PC6)
/PD0: A1.2 (D0/RX), U1.30 (PD0), U3.26 (TXD)
/PD1: A1.1 (D1/TX), U1.31 (PD1), U3.25 (RXD)
/PD2: A1.5 (D2), U1.32 (PD2)
/PD3: A1.6 (D3), U1.1 (PD3)
/PD4: A1.7 (D4), U1.2 (PD4)
/PD5: A1.8 (D5), U1.9 (PD5)
/PD6: A1.9 (D6), U1.10 (PD6)
/PD7: A1.10 (D7), U1.11 (PD7)
/USB_D+: J1.A6 (D+), J1.B6 (D+), U3.4 (D+)
/USB_D-: J1.A7 (D-), J1.B7 (D-), U3.5 (D-)
/Vbus: F1.1, J1.A4 (VBUS), J1.A9 (VBUS), J1.B4 (VBUS), J1.B9 (VBUS)
/Vbus_f: C1.1, C2.1, D2.2 (A), F1.2, U3.7 (VREGIN), U3.8 (VBUS)
/XTAL1: C10.1, U1.7 (XTAL1/PB6), Y1.3
/XTAL2: C9.2, U1.8 (XTAL2/PB7), Y1.1
GND: A1.4 (GND), A1.29 (GND), C1.2, C2.2, C3.2, C5.2, C6.2, C7.1, C8.2, C9.1, C10.2, C11.2, C12.2, D1.1 (K), D3.1 (K), J1.A1 (GND), J1.A12 (GND), J1.B1 (GND), J1.B12 (GND), J1.SH (SHIELD), J2.6, R1.2, R2.2, SW1.1, U1.3 (GND), U1.5 (GND), U1.21 (GND), U2.1 (GND), U3.3 (GND), U3.29 (GND), Y1.2 (G), Y1.4 (G)
unnamed: R3.2, R4.2
unnamed: R5.2, SW1.2
VCC: A1.30 (VIN), C11.1, U2.3 (VI)

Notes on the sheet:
USB-C/Serial
Status LED
Microcontroller
Connections
ICSP
Reset Circuit
Voltage Regulator
5V autoselector
EasyDuino Atmega328p Nano
Built in LED
No polarity protection on Vin. Careful!
5V Voltage regulator

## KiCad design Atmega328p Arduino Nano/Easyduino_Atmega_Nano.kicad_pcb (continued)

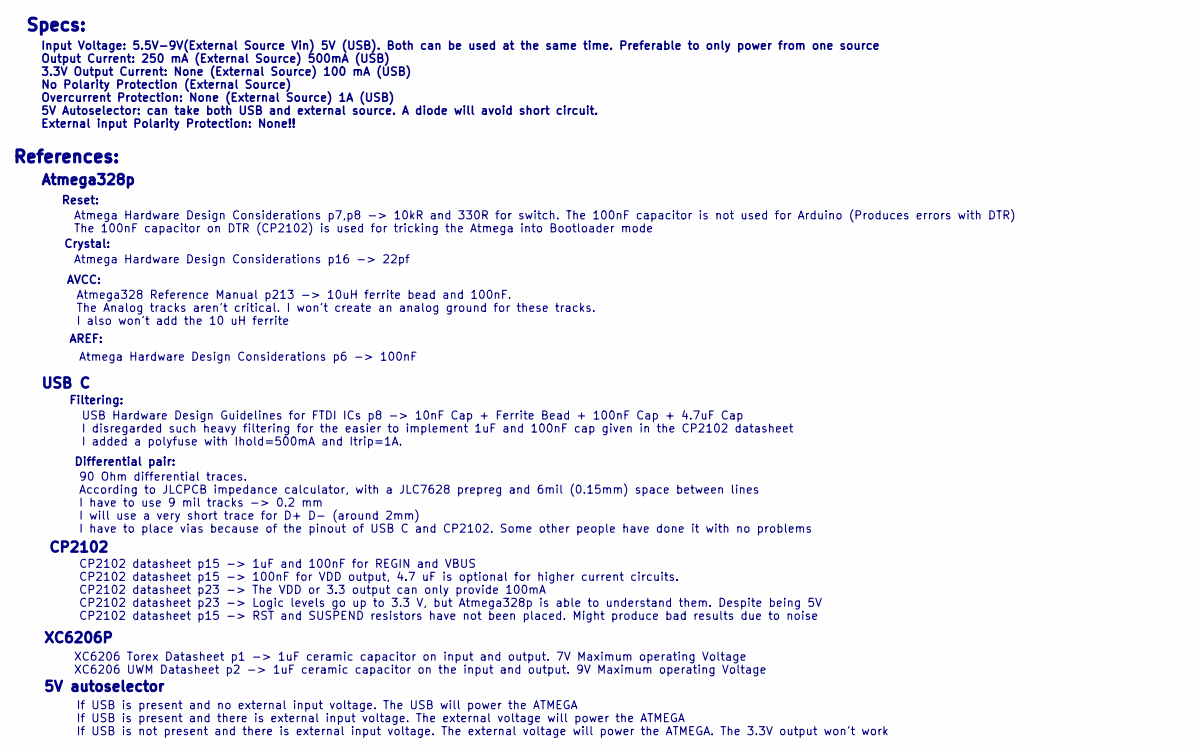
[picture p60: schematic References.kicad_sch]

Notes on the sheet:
AREF:
References:
Atmega328 Reference Manual p213 -> 10uH ferrite bead and 100nF. The Analog tracks aren't critical. I won't create an analog ground for these tracks. I also won't add the 10 uH ferrite
Atmega Hardware Design Considerations p7,p8 -> 10kR and 330R for switch. The 100nF capacitor is not used for Arduino (Produces errors with DTR) The 100nF capacitor on DTR (CP2102) is used for tricking the Atmega into Bootloader mode
Atmega328p
Specs:
CP2102
90 Ohm differential traces. According to JLCPCB impedance calculator, with a JLC7628 prepreg and 6mil (0.15mm) space between lines I have to use 9 mil tracks -> 0.2 mm I will use a very short trace for D+ D- (around 2mm) I have to place vias because of the pinout of USB C and CP2102. Some other peo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
5V autoselector
Filtering:
If USB is present and no external input voltage. The USB will power the ATMEGA If USB is present and there is external input voltage. The external voltage will power the ATMEGA If USB is not present and there is external input voltage. The external voltage will power the ATMEGA. The 3.3V output won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
XC6206P
Crystal:
Reset:
CP2102 datasheet p15 -> 1uF and 100nF for REGIN and VBUS CP2102 datasheet p15 -> 100nF for VDD output, 4.7 uF is optional for higher current circuits. CP2102 datasheet p23 -> The VDD or 3.3 output can only provide 100mA CP2102 datasheet p23 -> Logic levels go up to 3.3 V, but Atmega328p is able to 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
AVCC:
Atmega Hardware Design Considerations p6 -> 100nF
USB C
Differential pair:
USB Hardware Design Guidelines for FTDI ICs p8 -> 10nF Cap + Ferrite Bead + 100nF Cap + 4.7uF Cap I disregarded such heavy filtering for the easier to implement 1uF and 100nF cap given in the CP2102 datasheet I added a polyfuse with Ihold=500mA and Itrip=1A.
Atmega Hardware Design Considerations p16 -> 22pf
Input Voltage: 5.5V-9V(External Source Vin) 5V (USB). Both can be used at the same time. Preferable to only power from one source Output Current: 250 mA (External Source) 500mA (USB) 3.3V Output Current: None (External Source) 100 mA (USB) No Polarity Protection (External Source) Overcurrent Protec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
XC6206 Torex Datasheet p1 -> 1uF ceramic capacitor on input and output. 7V Maximum operating Voltage XC6206 UWM Datasheet p2 -> 1uF ceramic capacitor on the input and output. 9V Maximum operating Voltage

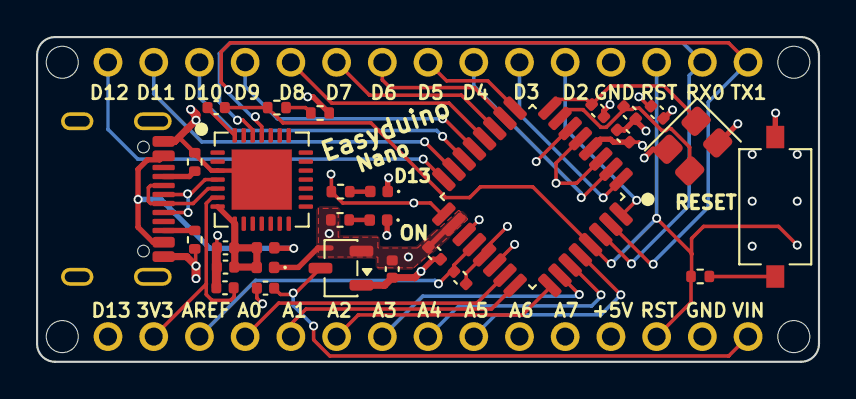
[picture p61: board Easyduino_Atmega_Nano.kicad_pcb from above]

Board: 4 copper layers, 43.4 x 18.0 mm, 31 parts (1 on the bottom side), 41 nets.

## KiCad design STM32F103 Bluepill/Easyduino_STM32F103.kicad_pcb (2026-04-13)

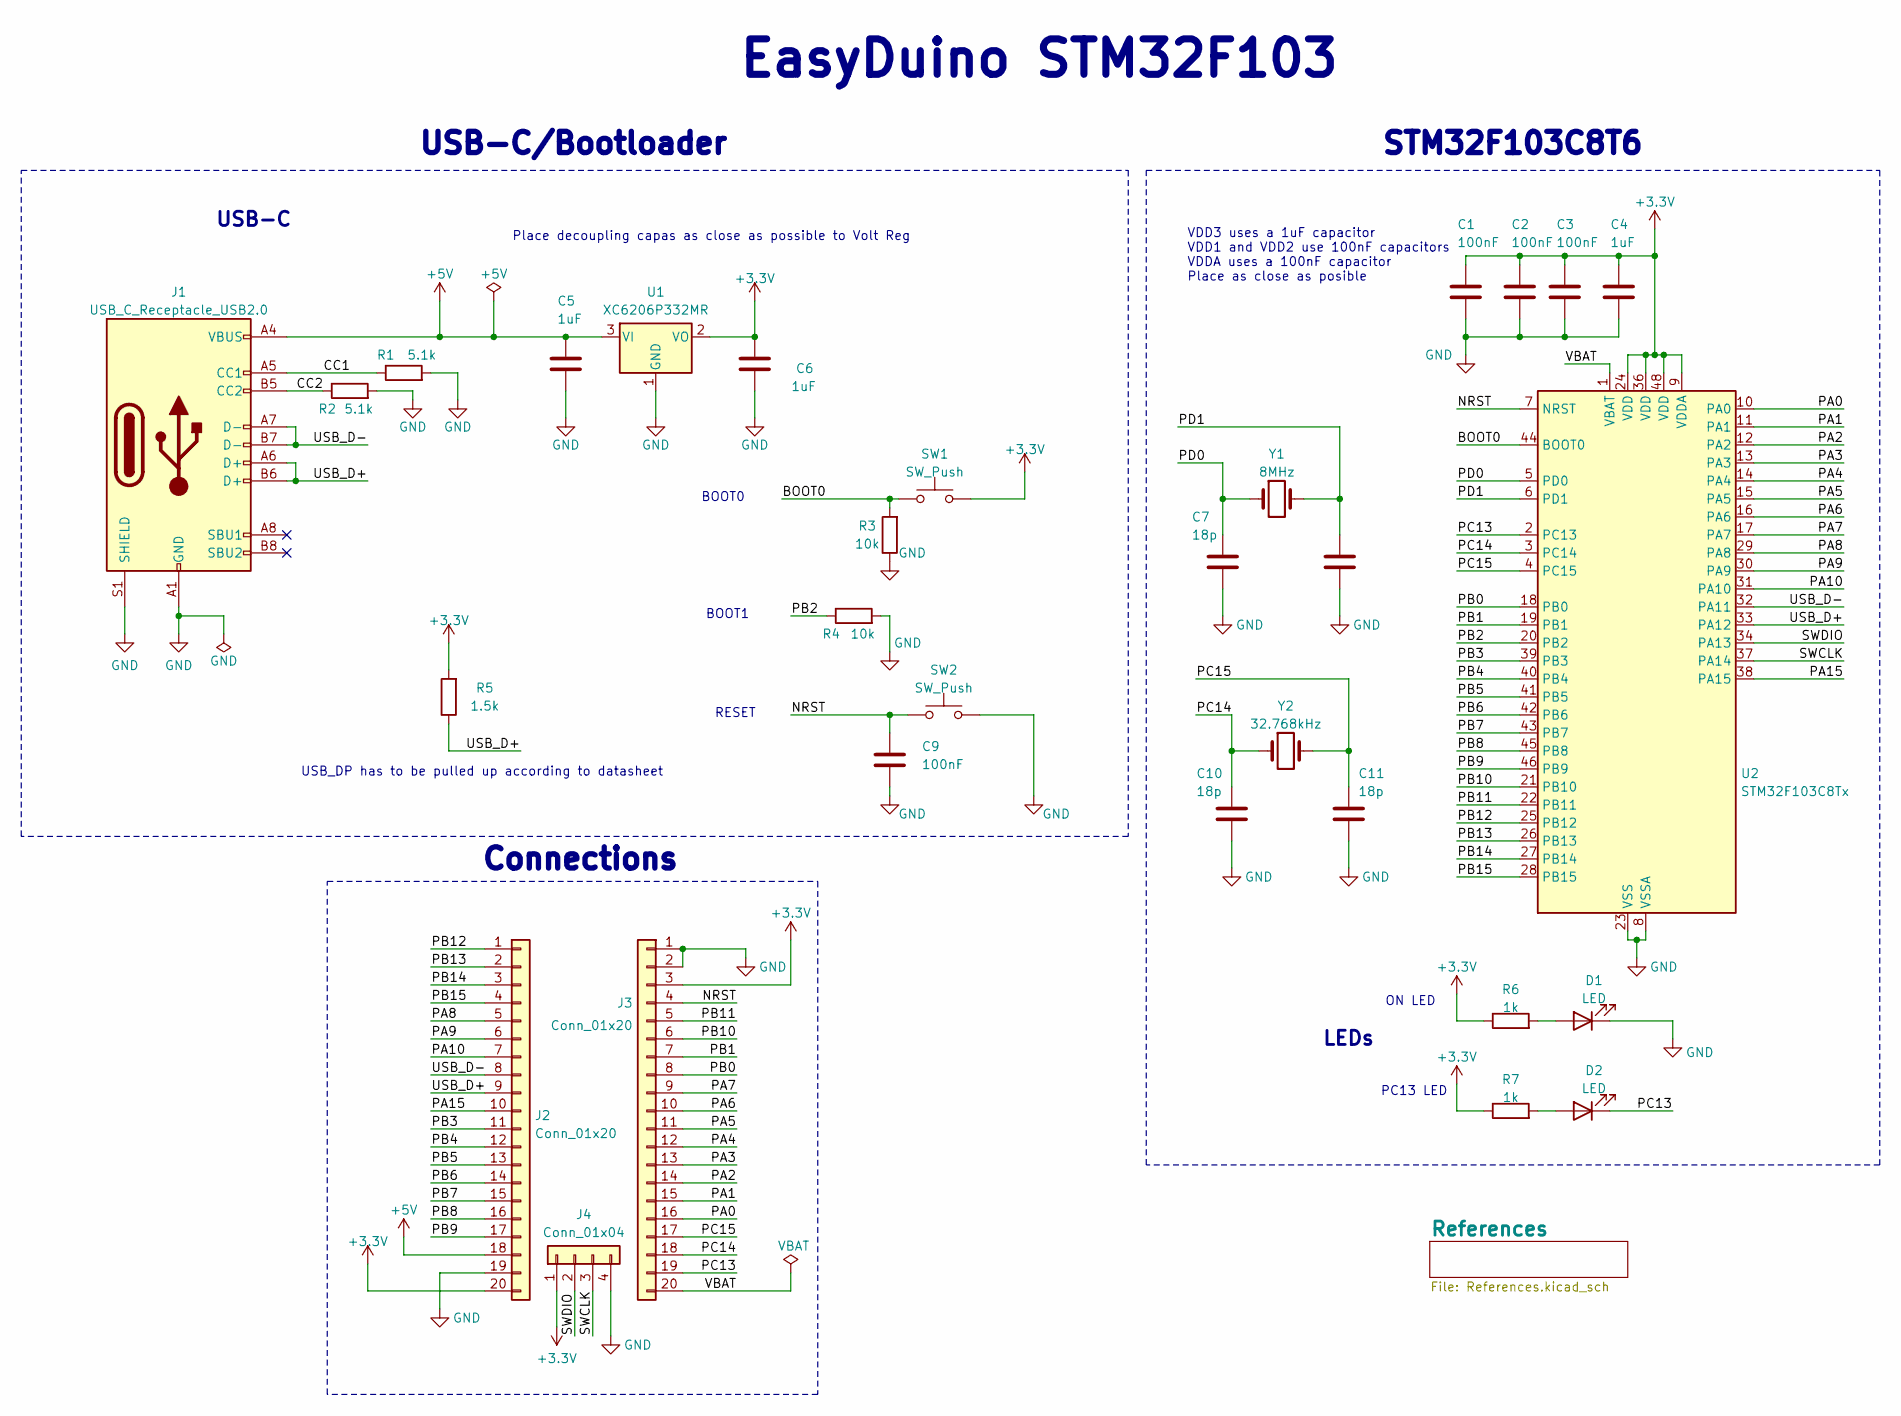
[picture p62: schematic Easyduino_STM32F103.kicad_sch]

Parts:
C1, C2, C3, C9: 100nF; C_0402_1005Metric; LCSC C1525
C4, C5, C6: 1uF; C_0402_1005Metric; LCSC C52923
C7, C8, C10, C11: 18p; C_0402_1005Metric; LCSC C1549
D1, D2: LED; LED_0402_1005Metric; LCSC C434448
J1: USB_C_Receptacle_USB2.0; USB_C_Receptacle_G-Switch_GT-USB-7010ASV; LCSC C2765186
J2, J3: Conn_01x20; PinHeader_1x20_P2.54mm_Vertical
J4: Conn_01x04; PinHeader_1x04_P2.54mm_Vertical
R1, R2: 5.1k; R_0402_1005Metric; LCSC C25905
R3, R4: 10k; R_0402_1005Metric; LCSC C25744
R5: 1.5k; R_0402_1005Metric; LCSC C25867
R6, R7: 1k; R_0402_1005Metric; LCSC C11702
SW1, SW2: SW_Push; ALPSALPINE_SKRPACE010; LCSC C139797
U1: XC6206P332MR; SOT-23-3; LCSC C347376
U2: STM32F103C8Tx; LQFP-48_7x7mm_P0.5mm; LCSC C8734
Y1: 8MHz; Crystal_SMD_5032-2Pin_5.0x3.2mm; LCSC C115962
Y2: 32.768kHz; Crystal_SMD_3215-2Pin_3.2x1.5mm; LCSC C32346

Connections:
+3.3V: C1.1, C2.1, C3.1, C4.1, C6.1, J2.20, J3.3, J4.1, R5.2, R6.1, R7.1, SW1.1, U1.2 (VO), U2.9 (VDDA), U2.24 (VDD), U2.36 (VDD), U2.48 (VDD)
+5V: C5.1, J1.A4 (VBUS), J1.A9 (VBUS), J1.B4 (VBUS), J1.B9 (VBUS), J2.18, U1.3 (VI)
/BOOT0: R3.2, SW1.2, U2.44 (BOOT0)
/CC1: J1.A5 (CC1), R1.1
/CC2: J1.B5 (CC2), R2.1
/NRST: C9.1, J3.4, SW2.2, U2.7 (NRST)
/PA0: J3.16, U2.10 (PA0)
/PA1: J3.15, U2.11 (PA1)
/PA2: J3.14, U2.12 (PA2)
/PA3: J3.13, U2.13 (PA3)
/PA4: J3.12, U2.14 (PA4)
/PA5: J3.11, U2.15 (PA5)
/PA6: J3.10, U2.16 (PA6)
/PA7: J3.9, U2.17 (PA7)
/PA8: J2.5, U2.29 (PA8)
/PA9: J2.6, U2.30 (PA9)
/PA10: J2.7, U2.31 (PA10)
/PA15: J2.10, U2.38 (PA15)
/PB0: J3.8, U2.18 (PB0)
/PB1: J3.7, U2.19 (PB1)
/PB2: R4.1, U2.20 (PB2)
/PB3: J2.11, U2.39 (PB3)
/PB4: J2.12, U2.40 (PB4)
/PB5: J2.13, U2.41 (PB5)
/PB6: J2.14, U2.42 (PB6)
/PB7: J2.15, U2.43 (PB7)
/PB8: J2.16, U2.45 (PB8)
/PB9: J2.17, U2.46 (PB9)
/PB10: J3.6, U2.21 (PB10)
/PB11: J3.5, U2.22 (PB11)
/PB12: J2.1, U2.25 (PB12)
/PB13: J2.2, U2.26 (PB13)
/PB14: J2.3, U2.27 (PB14)
/PB15: J2.4, U2.28 (PB15)
/PC13: D2.1 (K), J3.19, U2.2 (PC13)
/PC14: C10.1, J3.18, U2.3 (PC14), Y2.1
/PC15: C11.1, J3.17, U2.4 (PC15), Y2.2
/PD0: C7.1, U2.5 (PD0), Y1.1
/PD1: C8.1, U2.6 (PD1), Y1.2
/SWCLK: J4.3, U2.37 (PA14)
/SWDIO: J4.2, U2.34 (PA13)
/USB_D+: J1.A6 (D+), J1.B6 (D+), J2.9, R5.1, U2.33 (PA12)
/USB_D-: J1.A7 (D-), J1.B7 (D-), J2.8, U2.32 (PA11)
/VBAT: J3.20, U2.1 (VBAT)
GND: C1.2, C2.2, C3.2, C4.2, C5.2, C6.2, C7.2, C8.2, C9.2, C10.2, C11.2, D1.1 (K), J1.A1 (GND), J1.A12 (GND), J1.B1 (GND), J1.B12 (GND), J1.S1 (SHIELD), J2.19, J3.1, J3.2, J4.4, R1.2, R2.2, R3.1, R4.2, SW2.1, U1.1 (GND), U2.8 (VSSA), U2.23 (VSS), U2.35 (VSS), U2.47 (VSS)
unnamed: D1.2 (A), R6.2
unnamed: D2.2 (A), R7.2

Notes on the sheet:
STM32F103C8T6
BOOT0
ON LED
RESET
Place decoupling capas as close as possible to Volt Reg
BOOT1
PC13 LED
EasyDuino STM32F103
USB_DP has to be pulled up according to datasheet
VDD3 uses a 1uF capacitor VDD1 and VDD2 use 100nF capacitors VDDA uses a 100nF capacitor Place as close as posible
USB-C
USB-C/Bootloader
LEDs
Connections


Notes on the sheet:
USB C
Specs:
STM32F103x8 Datasheet p36 -> one 100nF decoupling capacitor per VDD pin except one 4.7uF capacitor in VDD3. I will use a 1uF capacitor in VDD3 to save costs STM32F103x8 Datasheet p36 -> one 10nF decoupling capacitor plus a 1uF capacitor for VDDA. I will not be needing very precise analog measuremen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
References:
USB
XC6206_Torex Datasheet p6 -> Two 1 uF ceramic capacitors on Vin and Vout
USB needs 90 Ohm differential traces. According to JLCPCB impedance calculator, with a JLC7628 prepreg and 6mil (0.15mm) space between lines I have to use 9 mil tracks -> 0.2mm. With a ground layer below I have to place vias because of the pinout of USB C. Some other people have placed vias without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
Input Voltage: 5.5V-9V(External Source through 5V pin) or 5V (USB). ONLY USE ONE VOLTAGE INPUT AT A TIME Maximum Output Current at 5V input : 200 mA at 3.3V output No Polarity Protection (External Source) Overcurrent Protection: None
Boot0 and Boot1:
XC6206P332MR-3.3V
Crystals
Decoupling Capacitors
NRST
STM32F103C8T6
Differential pair:



Board: 4 copper layers, 23.0 x 53.0 mm, 30 parts (2 on the bottom side), 47 nets.

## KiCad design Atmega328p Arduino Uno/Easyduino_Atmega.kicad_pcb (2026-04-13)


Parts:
A1: Arduino_UNO_Connects; Arduino_UNO_R3_WithMountingHoles
C1, C2, C3, C4, C5, C6, C7: 100n; C_0603_1608Metric; LCSC C14663
C8, C9: 22p; C_0603_1608Metric; LCSC C1653
C10, C11, C12: 22u; CP_EIA-3216-10_Kemet-I; LCSC C11366
D1: PRTR5V0U2X; SOT-143; LCSC C2827688
D2, D3: D_Schottky; D_SOD-123; LCSC C8598
D4, D5: LED; D_0603_1608Metric; LCSC C72043
F1: Polyfuse; Fuse_1206_3216Metric; LCSC C70077
J1: USB_C_Receptacle_USB2.0; USB_C_Receptacle_G-Switch_GT-USB-7010ASV; LCSC C2765186
J2: Conn_01x02_Pin; PinHeader_1x02_P2.54mm_Vertical
J3: ICSP; PinHeader_2x03_P2.54mm_Vertical
L1: 10uH; L_0603_1608Metric; LCSC C51942
R1, R2, R3, R4: 5.1k; R_0603_1608Metric; LCSC C23186
R5: 330; R_0603_1608Metric; LCSC C23138
R6, R7: 2k; R_0603_1608Metric; LCSC C22940
SW1: SW_Push; SW_SPST_Omron_B3FS-100xP; LCSC C271751
TP1, TP2: TestPoint; TestPoint_Pad_2.5x2.5mm
U1: CH340C; SOIC-16_3.9x9.9mm_P1.27mm; LCSC C84681
U2: ATmega328P-A; TQFP-32_7x7mm_P0.8mm; LCSC C14877
U3: AMS1117-5V; SOT-223-3_TabPin2; LCSC C6187
U4: AMS1117-3.3V; SOT-223-3_TabPin2; LCSC C6186
Y1: 16MHz; Crystal_SMD_3225-4Pin_3.2x2.5mm; LCSC C13738

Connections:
+3.3V: A1.4 (3V3), C12.1, U4.2 (VO)
+5V: A1.2 (IOREF), A1.5 (+5V), C3.2, C4.2, C11.1, D3.1 (K), J3.2, L1.1, R1.2, R7.1, U2.4 (VCC), U2.6 (VCC), U3.2 (VO), U4.3 (VI)
/AREF: A1.30 (AREF), C7.1, U2.20 (AREF)
/AVcc: C5.1, L1.2, U2.18 (AVCC)
/BuiltLed: D4.2 (A), R6.2
/ONLED: D5.2 (A), R7.2
/PB0: A1.23 (D8), U2.12 (PB0)
/PB1: A1.24 (D9), U2.13 (PB1)
/PB2: A1.25 (D10), U2.14 (PB2)
/PB3: A1.26 (D11), J3.4, U2.15 (PB3)
/PB4: A1.27 (D12), J3.1, U2.16 (PB4)
/PB5: A1.28 (D13), J3.3, R6.1, U2.17 (PB5)
/PC0: A1.9 (A0), U2.23 (PC0)
/PC1: A1.10 (A1), U2.24 (PC1)
/PC2: A1.11 (A2), U2.25 (PC2)
/PC3: A1.12 (A3), U2.26 (PC3)
/PC4: A1.13 (SDA/A4), A1.31 (SDA/A4), U2.27 (PC4)
/PC5: A1.14 (SCL/A5), A1.32 (SCL/A5), U2.28 (PC5)
/PC6: A1.3 (~RESET), C6.2, J3.5, R4.1, R5.2, U2.29 (~RESET/PC6)
/PD0: A1.15 (D0/RX), U1.2 (TXD), U2.30 (PD0)
/PD1: A1.16 (D1/TX), U1.3 (RXD), U2.31 (PD1)
/PD2: A1.17 (D2), U2.32 (PD2)
/PD3: A1.18 (D3), U2.1 (PD3)
/PD4: A1.19 (D4), U2.2 (PD4)
/PD5: A1.20 (D5), U2.9 (PD5)
/PD6: A1.21 (D6), U2.10 (PD6)
/PD7: A1.22 (D7), U2.11 (PD7)
/USB_D+: D1.3 (I/O2), J1.A6 (D+), J1.B6 (D+), U1.5 (UD+)
/USB_D-: D1.2 (I/O1), J1.A7 (D-), J1.B7 (D-), U1.6 (UD-)
/Vbus: F1.1, J1.A4 (VBUS), J1.A9 (VBUS), J1.B4 (VBUS), J1.B9 (VBUS)
/Vbus_f: C1.1, D1.4 (VCC), D3.2 (A), F1.2, U1.16 (VCC)
/Vin: D2.2 (A), J2.1, TP1.1 (1_1)
/XTAL1: C9.2, U2.7 (XTAL1/PB6), Y1.3
/XTAL2: C8.2, U2.8 (XTAL2/PB7), Y1.1
/cc1: J1.A5 (CC1), R2.1
/cc2: J1.B5 (CC2), R3.1
GND: A1.6 (GND), A1.7 (GND), A1.29 (GND), C1.2, C2.2, C3.1, C4.1, C5.2, C7.2, C8.1, C9.1, C10.2, C11.2, C12.2, D1.1 (GND), D4.1 (K), D5.1 (K), J1.A1 (GND), J1.A12 (GND), J1.B1 (GND), J1.B12 (GND), J1.S1 (SHIELD), J2.2, J3.6, R2.2, R3.2, SW1.1, TP2.1 (1_1), U1.1 (GND), U2.3 (GND), U2.5 (GND), U2.21 (GND), U3.1 (ADJ), U4.1 (ADJ), Y1.2 (G), Y1.4 (G)
unnamed: R1.1, R4.2
unnamed: R5.1, SW1.2
unnamed: C2.1, U1.4 (V3)
unnamed: C6.1, U1.13 (~DTR)
VCC: A1.8 (VIN), C10.1, D2.1 (K), U3.3 (VI)

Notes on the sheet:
Status LED
Connections
Voltage Regulators
ICSP Connector
Microcontroller
5V autoselector
USB-C/ESD Protection/Serial
Builtin LED
EasyDuino Atmega328p
Reset Circuit
6,5V-15V Input Voltage
3.3 Volt Regulator
Input Voltage Regulator


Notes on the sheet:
Specs:
Atmega328p
90 Ohm differential traces. According to JLCPCB impedance calculator, with a JLC7628 prepreg and 6mil (0.15mm) space between lines I have to use 9 mil tracks -> 0.2 mm I will use a very short trace for D+ D- (around 2mm)
CH340C
Atmega328 Reference Manual p213 -> 10uH ferrite bead and 100nF The Analog tracks aren't critical. I won't create an analog ground for these tracks
Filtering:
Atmega Hardware Design Considerations p12
AMS1117
ICSP Connector:
References:
If USB is present and no external input voltage. The USB will power the ATMEGA If USB is present and there is external input voltage. The external voltage will power the ATMEGA If USB is not present and there is external input voltage. The external voltage will power the ATMEGA
AVCC:
USB Hardware Design Guidelines for FTDI ICs p8 -> 10nF Cap + Ferrite Bead + 100nF Cap + 4.7uF Cap I disregarded such heavy filtering for the easier to implement 100nF cap given by the CH340 datasheet I added a polyfuse with I hold 500mA and Itrip 1A
Reset:
Differential pair:
Crystal:
USB C
Atmega Hardware Design Considerations p6 -> 100nF
5V autoselector
Ch340 Datasheet: p10 -> 100nF between GND and V3. Ch340 Datasheet: p10 -> 100nF between GND and Vcc. Vcc to Vusb
Atmega Hardware Design Considerations p7,p8 -> 10kR, 100nF cap and 330R for switch. The 100nF is not used in Arduino (produces erors with DTR) The 100nF capacitor on DTR (CH340C) is used for tricking Arduino into Bootloader mode, it produces a voltage spike.
AREF:
AMS1117 p4 -> 22uF tantalum capacitor on output LMS1117 p16-> 10uF tantalum capacitor the input. I will use a 22uF to reuse the same capacitor I will reuse the output capacitor of AMS1117-5V to be the output capacitor of AMS1117-3.3V
Input Voltage: 6.5V-15V(External Source Vin) 5V (USB). Both can be used at the same time. 5V Output Current: 1A (External Source) 500mA (USB) 3.3V Output Current: 500mA (External Source) 250 mA (USB) Polarity Protection (External Source) diode D2 Overcurrent Protection: None (External Source) 1A (U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
Atmega Hardware Design Considerations p16, p19 -> 22pf for 16 MHz


Board: 4 copper layers, 68.8 x 53.6 mm, 38 parts (1 on the bottom side), 42 nets.

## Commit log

2026-04-20 Added TODO: Fix ESP32 and ESP32S3 flash and reset bugs
    Updated to-do list with fixes for ESP32 and ESP32S3.
2026-04-21 ESP32 CP2102 bugfix
    [BOM.csv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]
2026-04-21 ESP32S3 CP2102 bugfix
    [BOM.csv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]
2026-04-21 Changed TODO: Order ESP32S3
2026-05-27 Announce new PCBs
2026-05-27 RP2040 v1.2
    [BOM.csv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]
2026-05-27 ESP32S3 v1.2
    [Easyduino_ESP32S3-B_Cu.gbl, Easyduino_ESP32S3-B_Mask.gbs, Easyduino_ESP32S3-B_Paste.gbp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]
2026-05-27 RP2040 v1.2 SilkScreen Fix
    [Easyduino_RP2040.kicad_pcb]
